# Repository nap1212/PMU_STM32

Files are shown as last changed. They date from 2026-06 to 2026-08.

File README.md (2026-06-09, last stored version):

# PMU Synchrophasor Dashboard

STM32F446RE (Nucleo) を使用した IEEE C37.118.1 準拠の PMU (Phasor Measurement Unit) 実装と、リアルタイム可視化ダッシュボードです。

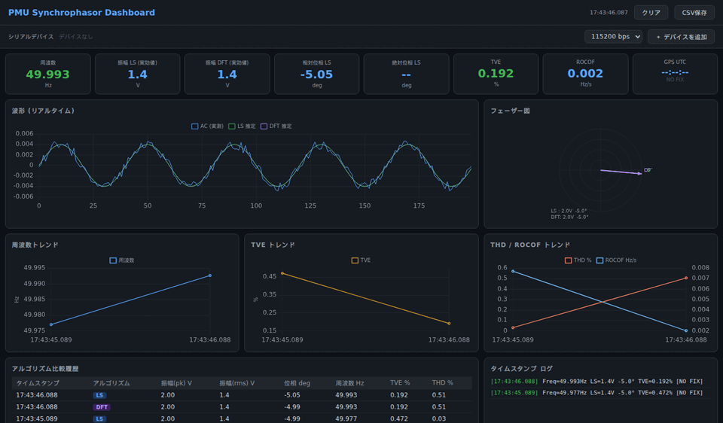
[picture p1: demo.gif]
Demo


---

## 概要

| 項目 | 内容 |
|---|---|
| MCU | STM32F446RE (Nucleo-F446RE) |
| GPS | Waveshare L76K GPS HAT |
| サンプリング周波数 | 2000 Hz |
| バッファサイズ | 200 サンプル (100 ms) |
| 対応系統周波数 | 50 Hz / 60 Hz |
| フェーザー推定 | LS法 (最小二乗) + DFT法 |
| 時刻同期 | GPS PPS (1秒パルス) による絶対フェーザー |

---

## ハードウェア構成

### 必要なもの

- STM32F446RE Nucleo ボード
- Waveshare L76K GPS HAT (または互換GPS モジュール)
- アナログ信号センサー (変換比 500:1)
- USB Type-A to Mini-B ケーブル
- ジャンパーワイヤー

### ピン接続

#### アナログ入力 (センサー)

```
交流電圧/電流
      │
   センサー (変換比 500:1)
      │
  DCバイアス回路 (目標: 1.65V = VDDA/2)
      │
   PA0 (Nucleo CN7 pin28) ← ADC1_IN0
```

#### GPS L76K HAT → Nucleo

```
L76K 40ピンヘッダー      Nucleo
─────────────────────────────────────
Pin 1  (3.3V)  ────→  3.3V (CN6 pin3)
Pin 6  (GND)   ────→  GND  (CN6 pin2)
Pin 7  (1PPS)  ────→  PA1  (CN7 pin24)  ← TIM5_CH2 入力キャプチャ
Pin 8  (TXD)   ────→  PA10 (CN10 pin33) ← USART1_RX
```

#### PC通信 (USB)

```
Nucleo USB ────→ PC (ST-Link 仮想COMポート, 115200 bps)
```

---

## ファームウェア機能

### 計測・解析

| 機能 | アルゴリズム |
|---|---|
| フェーザー推定 (相対) | LS法 (最小二乗) |
| フェーザー推定 (比較用) | DFT法 |
| **絶対フェーザー** | **GPS PPS 基準 UTC 同期** |
| 周波数推定 | ゼロクロス法 + 外れ値除外 |
| ROCOF | 周波数差分 |
| TVE | IEEE C37.118.1 準拠 (LS基準・DFT評価) |
| 高調波解析 | DFT 2次・3次 + THD |

### GPS同期

```
GPS PPS (1Hz) ──→ TIM5_CH2 入力キャプチャ
                      │
                  ppsCapture 記録 (90 MHz 分解能 ≈ 11 ns)
                      │
              バッファ先頭サンプル時刻との差分
                      │
              絶対位相 = 相対位相 − UTC基準コサイン位相
```

---

## ダッシュボード

Chrome / Edge でそのまま開けるシングルファイル HTML です。

```
pmu_dashboard.html をブラウザで開く
```

### 機能一覧

| パネル | 内容 |
|---|---|
| KPI カード | 周波数・振幅(LS/DFT)・相対位相・**絶対位相**・TVE・ROCOF・**GPS UTC/Lock** |
| 波形チャート | AC実測・LS推定・DFT推定 (200サンプルリアルタイム) |
| フェーザー図 | LS・DFT ベクトル描画 |
| 周波数トレンド | 直近60点 |
| TVE / THD / ROCOF トレンド | 直近60点 |
| アルゴリズム比較テーブル | LS vs DFT 履歴 |
| タイムスタンプログ | ミリ秒単位・GPS UTC 付き |
| CSV保存 | 全計測履歴をワンクリックでダウンロード |

### シリアル接続手順

1. Chrome または Edge でダッシュボードを開く (Firefox は WebSerial 非対応)
2. **「＋ デバイスを追加」** ボタンを押す
3. ブラウザのポート選択ダイアログで Nucleo の COM ポートを選択
4. **「接続」** ボタンを押す (115200 bps)

> デバイスパネルに `🔵 STM32 Nucleo` と表示されれば認識成功。  
> 接続すると自動でデモモードが停止し、実データに切り替わります。

---

## ビルド手順

### 1. 必要なもの

- STM32CubeIDE 1.14+
- STM32Cube FW_F4 V1.28+

### 2. ビルド

```
STM32CubeIDE でプロジェクトを開く
→ Project → Build Project
→ Run → Run
```

### 3. float printf 有効化 (初回のみ)

`Project → Properties → C/C++ Build → Settings → MCU GCC Linker → Miscellaneous → Other flags`

```
-u _printf_float
```

---

## シリアル出力フォーマット

### PLOT_MODE=0 (デフォルト: 波形)

```
AC:0.0012,LS_est:0.0011,DFT_est:0.0011   ← 200行
========================================
  PMU Synchrophasor Measurement Result
========================================
Frequency      : 50.012 Hz  [正常 50Hz]
ROCOF          : 0.0001 Hz/s
Abs Phase (LS) : -12.345 deg  [UTC基準]
GPS Lock       : LOCKED
UTC            : 12:34:56
TVE            : 0.234 %  [合格 <=1%]
...
```

### PLOT_MODE=1 (フェーザー情報)

```
Amp_LS:220.00,Amp_DFT:219.50,...,AbsPhase_LS:-12.345,UTC:12:34:56,GPS_LOCK:1
```

---

## ライセンス

MIT License

---

## 参考規格

- IEEE Std C37.118.1-2011: *IEEE Standard for Synchrophasor Measurements for Power Systems*
- NMEA 0183: GPS GPRMC センテンス

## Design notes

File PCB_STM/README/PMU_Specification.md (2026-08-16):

# 単相PMU 試作機 仕様書 (Specification)

**対象**：単相100V（コンセント地点）の同期フェーザ（電圧・電流）計測装置（ラボ試作・教育/研究用）
**版**：v3.2（アナログ3.3Vを **R1SE-0505廃止 → 低ノイズLDO一段** に簡素化）
**構成方針**：STM32で決定的サンプリング＋フェーザ演算／ESP32でWiFi送信／GPSで時刻同期／**測定線から分岐して装置自身に給電**

> **v3.2からの主な変更**：アナログ系電源（ADC AVDD / AMC VDD2）の生成を「R1SE-0505（絶縁DC-DC）＋LDO」から **低ノイズLDO一段** に変更。
> - この設計では安全絶縁は HLK と AMC3330/3302 が担うため、**R1SEの役割は“ノイズ絶縁”のみ**。R1SE自身がスイッチングノイズ源で結局LDOで掃除が要る → **最初からLDO一段の方が素直で低ノイズ・部品減**。
> - 振幅精度はADC内蔵Vref(1.2V)が決め、5Vノイズは PSRR 経由のみ。LDOのPSRR（DC〜系統高調波で60〜80dB）＋ΔΣ/AAFで十分クリーン。
> - フォールバック：**ESP32のグラウンド雑音がアナログ基準を揺らすのが実測で問題化した場合のみ**、R1SE（絶縁DC-DC）を復活してアナロググラウンドを島化する余地を残す。
>
> **v3.1（継続）**：自給電の電源部は **絶縁AC-DCモジュール HLK-10M05（AC100V→DC5V 2A）**。トランス T3＋整流＋三端子7805 を1個に集約（部品点数・発熱を削減）。容量2Aはピーク約1Aに対し余裕（5M05＝1Aは不足）。**分岐点はシャント Rsh 上流（L_NODE）で不変**。USBはデバッグ用途で併用可。

> **v2.0→v3.0**：外部USB/5V給電に代えて**測定対象の商用100Vから装置電源を自給**する構成を標準化（分岐はシャント上流）。
>
> **v1.0からの主な変更（継続）**：電流センサを ZMCT103C（電流トランス）→ **シャント抵抗 + AMC3302** に置換。
> 電流chが電圧chと同じ「センサ→絶縁アンプ→AAF→ADC」構造になり、**負担抵抗 Rb / Vcmバイアス Rcm / VCM基準回路 が不要**に。
> 位相誤差（純抵抗シャント＋固定遅延の絶縁アンプ）が大幅に低減し、PMUのTVE改善に寄与する。

---

## 1. 確定構成（主要部品）

| 役割 | 部品 | 備考 |
|---|---|---|
| MCU（取得・演算） | **STM32F446RE（NUCLEO-F446RE）** | FPU搭載、タイマ＋DMA |
| WiFi通信 | **ESP32（ESP32-WROOM-32E 開発ボード）** | C37.118 over WiFi 送信 |
| GPS（時刻同期） | **Waveshare L76K GPS HAT** | 1PPS出力、GPS/GLONASS/BeiDou/QZSS。Piに挿さずSTM32へ配線 |
| ADC | **ADS131M02** | 2ch・24bit・同時サンプリングΔΣ、SPI |
| 絶縁アンプ（電圧） | **AMC3330** | ±1V入力・絶縁DC-DC内蔵 |
| 絶縁アンプ（電流） | **AMC3302** | **±50mV入力・固定ゲイン41・絶縁DC-DC内蔵**（シャント用） |
| 電流シャント | **Rsh ≈ 1.5mΩ**（4端子/低TCR） | L線直列。10A時±21mV→×41で≈0.87V（ADC FSR ±1.2V内） |
| アナログ用LDO | **ADP7142（3.3V固定, TSOT-23-5：ADP7142AUJZ-3.3 / LFCSP：ACPZ-3.3）** | +5V_Fから ADC AVDD / AMC VDD2 を生成。入出力C≥2.2µF。代替 ADP7118-3.3 / TPS7A20 |
| **絶縁AC-DCモジュール** | **HLK-10M05（AC100-240V → DC5V 2A / 10W）** | 自給電の主電源。AC入力を**L_NODE-N_NODE（シャント上流）**へ。強化絶縁を担う。5M05(1A)は容量不足のため不採用 |
| **一次側ヒューズ（電源分岐）** | **F2：AC250V/T/0.5A** | HLK AC入力の保護 |

> **アナログ電源の位置づけ**：AMC3330/AMC3302はDC-DC内蔵のため絶縁電源は不要。ADC/AMCのアナログ3.3Vは **低ノイズLDO一段** で +5V から生成（アナロググラウンドはデジタルと1点接続）。安全絶縁はHLKとAMCが担うため、アナログ経路に絶縁DC-DC（R1SE等）は不要。**ESP32グラウンド雑音が実測で問題化した場合のみ**、R1SE（絶縁DC-DC）を追加してアナロググラウンドを島化する余地を残す。
> **自給電部（HLK-10M05）の位置づけ**：測定対象100Vから装置電源を作る。**絶縁境界は HLK（電源経路）と AMC3330/3302（信号経路）の二重**で、安全側は測定線に対して常にフローティング。**分岐点は必ずシャント Rsh より上流**とし、給電電流を測定経路（Rsh）に流さないこと（測定誤差ゼロの必須条件）。

---

## 2. システムブロック図

```
        危険側(AC100V, 測定線)          ┊絶縁┊            安全側(フローティング)
 L ─[F1]─[SW1]─●(L_NODE)─[Rsh 1.5mΩ]─●(L_LOAD)──────────→ 負荷へ(L)
              │  │                   │
              │ (電圧タップ)     シャント両端(±50mV)→ AMC3302(絶縁+DCDC) → AAF → ADS131M02 ch1
              │  │                                                          │
              │ 分圧(510k×3+5.1k)→ AMC3330(絶縁+DCDC) ─────────→ AAF → ADS131M02 ch0
              │  │                                                          │SPI/DRDY
   ┌──[F2]────┘  │      ← ★給電はシャント上流(L_NODE)で分岐 → Rshを通らない  │
   │(電源分岐)    │   ┊電源側の絶縁境界(HLK内蔵)┊                             │
 [HLK-10M05]─────┼─→ +5V(2A) ─┬─→ Nucleo(STM32) ──────────────────────────┤
 絶縁AC-DC 5V/2A  │            ├─→ ESP32 ─WiFi→ PC/PDC
   │            │            └─→ LDO(低ノイズ)→+3.3V_A(アナログ: ADC/AMC)
 N ●───────────●(N_NODE)────────────────────────────────→ 負荷へ(N)
        L76K GPS HAT ─UART/PPS─→ STM32(入力キャプチャ)   ↑MCO(8MHz)→ADC CLKIN
```

- **絶縁境界（信号）**：電圧ch＝AMC3330、電流ch＝**AMC3302**（いずれも容量結合の強化絶縁＋内蔵DC-DC）。
- **絶縁境界（電源）**：**HLK-10M05（絶縁AC-DC）**。AC入力＝危険側（L_NODE-N_NODE）、DC出力＝安全側。→ 安全側は測定線に対し**二重に絶縁**され、常にフローティング。MCU/ESP32/GPSは安全側。
- **自給電の要点**：分岐は**シャント Rsh より上流（L_NODE）**。HLK 1次電流は L_NODE→N_NODE を流れ **Rsh を通らない**ため、電流測定に一切影響しない。
- **両ch対称**：電圧・電流とも「センサ→絶縁アンプ→AAF→ADC」。出力コモンモードはアンプが自己生成（VDD2/2）。

---

## 3. 電源アーキテクチャ（測定線からの自給電）

**電源フロー**（AC-DCモジュール＋アナログ再生成）：
```
測定線 L_NODE ─[F2]─ HLK-10M05(AC100V→DC5V 2A) ═絶縁═ +5V
                                                       │
      +5V ─┬─→ Nucleo(E5V)→内蔵LDO→+3.3V_D(STM32/ADC DVDD/L76K)
           ├─→ ESP32（+5V, 470-1000µFバルク）
           └─→ LDO(低ノイズ3.3V) ─ +3.3V_A（ADC AVDD / AMC3330・3302 VDD2）
```

| レール | 供給先 | 供給元 |
|---|---|---|
| （AC入力） | HLK-10M05 Vin(L/N) | **測定線 L_NODE-N_NODE（シャント上流）** 経由、F2で保護 |
| +5V | ESP32 / アナログLDO入力 / Nucleo(E5V) | **HLK-10M05 出力 5V/2A**（自給電・絶縁済） |
| +3.3V（デジタル） | STM32 / ADS131M02 DVDD / L76K | Nucleo 3.3V（E5V経由の内蔵LDO） |
| +3.3V（アナログ） | ADS131M02 AVDD / **AMC3330 VDD2 / AMC3302 VDD2** | **+5V → 低ノイズLDO一段で3.3V**（π型フィルタ後の+5V_Fから） |
| AMC3330/AMC3302 フィールド側 | （各IC内部DC-DCが自動生成） | 不要 |

- **自給電の原則**：**分岐はシャント Rsh の上流（L_NODE）**。給電電流（HLKのAC入力）は Rsh を通らず、電流測定に影響しない（誤差ゼロの必須条件）。
- **ノイズ対策（要点）**：HLK-10M05は**スイッチング方式**で出力に数十mVppのリプル＋高周波ノイズを持つ。よって
  - **アナログ系(ADC/AMC)は π型フィルタ後の+5V → 低ノイズLDO** で作り、LDOのPSRR＋フィルタでHLKノイズを落とす。
  - HLK出力直後に **π型フィルタ（10µF＋小インダクタ/フェライトビーズ＋10µF）**＋各ICデカップリングでHF成分を減衰。
  - HLKのスイッチング周波数はADC帯域(≈fs/2 3.9kHz, AAF 1.7kHz)より遥かに高く、ΔΣ＋AAFで良く落ちるが、エイリアス防止のためAAF前段のクリーン化を優先。
- **Nucleo給電**：E5Vピンへ+5V供給（ジャンパ **JP5 を E5V 側**に設定）。
- **容量マージン**：HLK-10M05=2A に対しシステムピーク約1A → 2倍の余裕。ESP32送信バーストは **ESP32直近の 470-1000µFバルク**でも吸収。
- アナロググラウンド/デジタルグラウンドは**1点（スター）接続**。**HLKの −Vout=安全側基準（DGND）**（フローティング）。AGNDとはADC直下1点で結合。
- **VCM基準回路は廃止**（電流chがアンプ自己バイアスになったため不要）。

### 3.1 自給電電源部の設計（性能を落とさないための要点）

**目的**：測定対象の商用100Vから装置電源を作りつつ、（a）電流測定に誤差を出さない（b）ADC/AMCへスイッチングノイズを持ち込まない。

**(1) 分岐点＝シャント上流（測定誤差ゼロの必須条件）**
```
 L ─[F1]─[SW1]─●(L_NODE)──[Rsh 1.5mΩ]──●(L_LOAD)──→ 負荷L
                 │  ▲(ここを通る電流=測定値)
      ┌──[F2]────┘
 [HLK Vin(L)]   ← 分岐は必ず L_NODE（Rshの上流）。
      │           HLKのAC入力電流は L_NODE→N_NODE を流れ Rsh を通らない → 測定に加算されない
 N ───●(N_NODE)── HLK Vin(N)
```
- L_LOAD（シャント下流）から取ると給電電流が Rsh を流れ負荷電流に上乗せ＝誤差。**必ず L_NODE**。
- 電圧測定への影響：HLK入力は L_NODE-N_NODE 間の負荷になるが、分圧タップの電圧読み値自体は変わらない（精度影響なし。ごく軽い電源負荷が増えるのみ）。

**(2) 消費電力の見積り（+5V換算）**

| ブロック | 平均 | ピーク | 備考 |
|---|:---:|:---:|---|
| Nucleo（STM32＋内蔵LDO, L76K含む） | ~150mA | ~180mA | E5V給電 |
| ESP32 | ~120mA | ~500mA | WiFi送信時バースト |
| アナログ系（ADC/AMC＋LDO） | ~50mA | ~80mA | LDOで5V→3.3V、消費は小さい |
| **合計** | **~320mA** | **~0.8A** | HLK-10M05(2A)で2倍超の余裕 |

**(3) 電源モジュール（HLK-10M05）**

| 項目 | 値 | 計算/根拠 |
|---|----|---|
| 型式 | **HLK-10M05** | 絶縁AC-DC、AC100-240V入力、DC5V 2A(10W)出力 |
| 出力容量 | **2A** | システムピーク約1Aに対し2倍余裕（5M05=1Aは不足のため不採用） |
| 出力リプル | 数十mVpp＋SWノイズ | **アナログはπ型フィルタ＋低ノイズLDOで除去** |
| 出力バルク | +5V直下 100µF＋ESP32直近 470-1000µF | ESP32送信ピーク吸収 |
| AC入力保護 | **F2：AC250V/T/0.5A** | HLK入力側ヒューズ |
| 絶縁 | 強化絶縁（データシート値） | 安全側フローティングを担保 |

- **HLKの弱点＝スイッチングノイズ**：リニア（旧T3+7805）より不利。よって**アナログ経路は π型フィルタ＋低ノイズLDO** でHF減衰・再レギュレート。
- **利点**：部品点数削減・発熱ほぼ無し（放熱器不要）・入手容易・小型。トランス入手難と7805発熱の問題を解消。

**(4) ノイズ・性能維持**
- HLK-10M05は**スイッチング方式**なので、出力に数十mVppリプル＋高周波ノイズを持つ（リニアより不利）。対策を段で重ねてADCアナログ帯域への混入を抑える：
  1. **HLK出力直後にπ型LCフィルタ**（L1＋C45/C46 10µF）でHF成分を減衰。
  2. **アナログ系(ADC AVDD / AMC VDD2)は 低ノイズLDO一段**で3.3Vを再生成 → LDOのPSRR（DC〜系統高調波で60〜80dB）でHLKリプルを除去。
  3. ADCは**ΔΣ＋AAF(1.7kHz)**。HLKのスイッチング周波数（数十〜数百kHz）は帯域外で強く減衰。ただしエイリアス防止のためAAF前段のクリーン化を優先。
- 振幅精度を決めるのはADC内蔵Vref(1.2V)であり+5Vレールではない → 5Vノイズが基本波ビンのTVEへ乗る経路は細い。
- グラウンド：**HLK −Vout＝安全側基準（DGND, フローティング）**。AGND-DGNDはADC直下1点スター（§20）。ESP32のバースト電流はDGND側に閉じ込め、AGNDへ回さない。

---

## 4. 電圧フロントエンド設計

AMC3330：±1Vバイポーラ入力（中点バイアス不要）・**固定ゲイン2.0**。
分圧比は「**ゲイン2倍後の出力がADC FSR(±1.2V)に収まる**」よう設定（入力範囲だけでなく出力で確認）。

| 部品 | 値 | 計算/備考 |
|---|----|---|
| 分圧 上側 Rhi | **510kΩ ×3 直列（1.53MΩ）** | 各≈33V分担で耐圧確保。0.1%/≤25ppm/薄膜 |
| 分圧 下側 Rlo | **5.1kΩ** | 分圧比 ≈ 1/301（5.11kΩ/E96でも可）|
| 入力ピーク | 141Vpk ÷301 ≈ **0.47Vpk** | AMC3330 ±1V内 |
| AMC出力（×2）| 0.47Vpk×2 ≈ **0.94Vpk** | ADS131M02 FSR ±1.2V内（約22%余裕）|
| 分圧電流 | 約65µA（消費約6.5mW、発熱無視可） | Rhiでほぼ決まる |
| 出力コモンモード | AMC3330が VDD2/2（≈1.65V@3.3V）を生成 | ADC入力CMに整合 |

- **耐圧確認**：510kΩは working voltage ≥ 33V/本。
- **重要**：AMC3330はゲイン2なので `141Vpk × 分圧比 × 2 ≤ 1.2V` を満たすこと。
  （旧版の1/153では出力1.84Vpk＞FSRで飽和していた → Rloを10kΩ→5.1kΩに変更）

---

## 5. 電流フロントエンド設計（シャント抵抗 + AMC3302）

L線に低抵抗シャントを直列に挿入し、その両端電圧（±数十mV）を**絶縁シャントアンプ AMC3302**で測る。
純抵抗センスのため**位相誤差がほぼゼロ**、DCも測定可、飽和なし。**実用測定レンジ 〜10A**前提。

| 部品 | 値 | 計算/備考 |
|---|----|---|
| シャント Rsh | **1.5mΩ**（4端子ケルビン/≤25ppm/≥1W） | 10A rms（14.1Apk）で 14.1A×1.5mΩ ≈ **21.2mVpk**（AMC3302 ±50mV内） |
| 絶縁アンプ AMC3302 | 入力±50mV / **固定ゲイン 41** | 出力差動 = 21.2mV×41 ≈ **0.87Vpk**（ADS131M02 FSR ±1.2V内）|
| ADC飽和まで | 出力1.2V→入力29.3mV→ **約13.8A rms** | 定格10Aに対し約1.4倍の余裕 |
| 発熱 | I²R = 100×0.0015 ≈ **0.15W**（10A時）| 5A時≈0.04W |
| 出力コモンモード | AMC3302が VDD2/2（≈1.65V）を生成 | ADC入力CMに整合（中点バイアス不要）|
| レンジ調整 | 小信号重視→Rsh大（2mΩ等）／大電流→Rsh小 | 「最大電流×√2×Rsh×41 ≤ 1.2V」を満たすこと |

**接続**：Rshの両端を**ケルビン(4端子)**で AMC3302 INP/INN へ。AMC3302の高圧側GND(HGND)はシャント片端へ。
出力 OUTP/OUTN を AAF経由で AIN1P/AIN1N へ。**負担抵抗・Vcmバイアス・VCM基準は不要**。

> **重要**：シャント自体は非絶縁（L線上）。絶縁はAMC3302が担う（強化絶縁＋内蔵DC-DC）。
> シャントは**低TCR・4端子**品を選び、配線抵抗を測定値に含めないこと。

---

## 6. アンチエイリアスフィルタ（AAF）

電圧ch・電流chで**完全同一**（位相整合のため）。差動構成。**v1.0から変更なし**。

| 部品 | 値 | 備考 |
|---|----|----|
| 直列R（各ライン） | **1kΩ ×2/ch**（0.1%/薄膜） | 両ch同一型番 |
| 差動C（Cdiff） | **47nF**（C0G/NP0 or フィルム） | fc_diff ≈ 1/(2π·2kΩ·47nF) ≈ **1.7kHz** |
| コモンモードC（Ccm） | **1nF ×2/ch**（C0G） | 各ラインからAGNDへ（任意） |

- fc≈1.7kHz は fs/2（≈3.9kHz）より十分下。50Hzで約−1.7°の群遅延 → **両ch同一化で相殺＋実測補償**。

---

## 7. ADCサブシステム（ADS131M02）

| 項目 | 設計値 |
|---|---|
| CLKIN | **STM32 MCO出力 8MHz**（PA8/MCO1。Nucleo HSE由来） |
| fMOD | 4MHz（CLKIN/2） |
| OSR | **512** |
| データレート fDATA | **≈7812.5 SPS**（50Hzで約156サンプル/周期、60Hzで約130） |
| ゲイン | 1（FSR ±1.2V、内部Vref 1.2V） |
| インタフェース | SPI（STM32マスタ）、**DRDY→EXTI割込**、DMA転送 |
| ch割当 | ch0=電圧、ch1=電流（同時サンプリング） |

---

## 8. 時刻同期（L76K GPS HAT）

- HATはPi用だが、**UART(TX/RX)・PPS・5V/3.3V・GND をSTM32へ配線**して使用（Piに挿さない）。**PPSピンが端子に出ていることを確認**。
- L76K：GPS/GLONASS/BeiDou/**QZSS(みちびき)対応**、1PPS精度 <30ns（50Hzで約0.0005°相当＝十分）。
- **PPS → STM32タイマ入力キャプチャ**（sub-µsでエッジ時刻取得）。
- UARTでNMEA/構成（PPS周波数等）を受信。屋外/窓際で運用。

---

## 9. 制御・通信

- **STM32 → ESP32：UART（例 921600bps）**でフェーザ結果（タイムスタンプ・V振幅/位相・I振幅/位相・f・ROCOF）を転送。
- **ESP32**：受信データを **C37.118.2 フレーム化 → WiFi(UDP/TCP)** でPC/PDCへ。
- 両者3.3Vロジック・GND共通、レベルシフト不要。
- 時刻クリティカルパスはSTM32内で完結 → WiFi遅延・ジッタはフェーザ精度に無影響（値にタイムスタンプ）。

---

## 10. STM32ピン割当（例：NUCLEO-F446RE）

| 機能 | ピン例 |
|---|---|
| ADC SPI（SCLK/MISO/MOSI/CS） | SPI1: PA5/PA6/PA7/PA4 |
| ADC DRDY | EXTI: PB0 |
| ADC /SYNC-RESET | 予備GPIO（例 PC0。§19-E/§20参照） |
| ADC CLKIN | **MCO1: PA8（8MHz出力）** |
| GPS PPS | タイマ入力キャプチャ: TIM2_CH1 / PA0 |
| GPS UART | USART2: PA2(TX)/PA3(RX) |
| ESP32 UART | USART1: PA9(TX)/PA10(RX) |

---

## 11. 受動部品リスト（抵抗・コンデンサ）と数量

### 抵抗（すべて Thin Film、精度が効く所は 0.1%/≤25ppm）

| 値 | 用途 | 必要数 | 推奨購入数 | 仕様 |
|----|---|:---:|:---:|---|
| 510kΩ | 分圧上側（3直列） | 3 | **10** | 0.1%/≤25ppm/耐圧≥33V |
| 5.1kΩ | 分圧下側（Rlo） | 1 | **5** | 0.1%/≤25ppm（5.11kΩ/E96可・ゲイン2考慮で1/300）|
| 1kΩ | AAF（2本/ch×2ch） | 4 | **10** | 0.1%/薄膜・両ch同一型番 |
| **1.5mΩ シャント Rsh** | 電流センス | 1 | **3** | 4端子ケルビン/≤25ppm/≥1W（実発熱0.15W@10A） |

> v1.0から削除：68Ω負担抵抗 / 10kΩ×4（Vcm分圧2＋Rcm2）。
> 旧部品記号 R7(負担)・R8,R9(VCM)・R10,R11(Rcm) は廃止。

### コンデンサ

| 値 | 用途 | 必要数 | 推奨購入数 | 種類 |
|----|---|:---:|:---:|---|
| 0.1µF | 各IC電源デカップリング | ~12 | **30** | X7R 50V |
| 1µF | ADC(AVDD/DVDD/CAP)・AMC3330/AMC3302(VDD2・DC-DC高圧側) | ~10 | **25** | X7R 50V |
| 10µF | LDO入出力(C16/C18・各≥2.2µF)・AVDDバルク・πフィルタ(C45/C46) | ~5 | **15** | X5R/X7R |
| 100µF | 5Vバルク（ESP32突入対策） | 2 | **5** | 電解/タンタル |
| 47nF | AAF 差動C（Cdiff） | 2 | **10** | **C0G/NP0** or フィルム |
| 1nF | AAF コモンモードC（Ccm）・AMC高圧側 | ~8 | **15** | C0G |

> v1.0から削除：VCMバイパス10µF（C4）。追加：AMC3302のデカップリング一式（AMC3330と同じ構成）。
> ADS131M02/AMC3330/AMC3302/アナログLDO の各データシート推奨デカップリング（CAPピン・DC-DCピン等）を最終確認して値・本数を確定すること。

### 自給電電源部（v3.1：HLK-10M05 方式／v3.2：アナログLDO一段）

| 部品 | 記号 | 値/型 | 必要数 | 備考 |
|---|---|---|:---:|---|
| 絶縁AC-DCモジュール | U6 | **HLK-10M05**（AC100-240V→DC5V 2A） | 1 | AC入力を L_NODE-N_NODE（シャント上流）へ。強化絶縁 |
| 電源分岐ヒューズ | F2 | AC250V/T/0.5A ＋ホルダ | 1 | HLK AC入力保護 |
| 出力バルク（+5V直下） | C43 | 100µF | 1 | 電解/タンタル |
| 出力バルク（ESP32直近） | C44 | 470-1000µF | 1 | 電解。送信ピーク吸収 |
| πフィルタ用 | L1 | 大電流フェライトビーズ（1206以上/定格≥2A/DCR≤50mΩ/100〜600Ω@100MHz。例：村田BLM31系, TDK MPZ2012系）or 4.7〜10µH/≥2Aパワーインダクタ | 1 | HLK出力HF減衰。全電流が通るため信号用0603ビーズ不可 |
| πフィルタ用C | C45,C46 | 10µF ×2 | 2 | L1と組んでπ型LC |
| アナログ用LDO | U4 | ADP7142（3.3V固定, 例 AUJZ-3.3/ACPZ-3.3） | 1 | +5V_F→+3.3V_A。EN→VIN、SENSE→VOUT、入出力C≥2.2µF（C16/C18=10µF） |

> HLK-10M05は**トランス T3／ブリッジ BR1／平滑 C40／三端子 U6(7805)／放熱器 を全て置換**（v3.0比で大幅減）。放熱器・T3入手難の問題が解消。
> アナログ3.3Vは **低ノイズLDO一段**（R1SE-0505は廃止）。安全絶縁はHLK/AMCが担うためアナログ経路に絶縁DC-DCは不要。

---

## 12. アルゴリズム

### 12.1 取得（Acquisition）
1. STM32がMCOで8MHzをADC CLKINへ供給 → ADCは固定 fDATA(≈7812.5SPS) で**自走**。
2. **DRDY割込**ごとにSPI/DMAで2ch同時サンプル（V,I）を取得し、リングバッファへ。
3. **PPS立ち上がり**をタイマ入力キャプチャで捕捉 → そのタイマカウントを保持。
4. サンプルカウンタとPPSキャプチャ値から、各サンプルの**絶対時刻（UTC）**を復元。
   - PPS毎に基準を更新（STM32水晶のppm誤差を1秒毎にリセット）。

### 12.2 フェーザ推定（Phasor Estimation）
- 報告周期（例 **50 fps**、設定可）ごとに、UTCの基準時刻に整列した窓のサンプルを抽出。
- 基本波フェーザを **DFT** で算出：
  - `X = (2/N) Σ x[n]·e^(−j2πk0 n/N)`（k0＝基本波ビン）
  - この正規化で **|X| ＝ピーク振幅**、位相 = arg(X)（**UTC基準＝同期フェーザ**）。
  - **C37.118は振幅＝RMS慣例**のため、出力・電力計算の前に **RMS化：Vrms=|X|/√2、Irms=|X|/√2**。
- **補間DFT（Interpolated DFT, IpDFT）**で系統周波数の公称ズレを補正：
  - Hann窓を適用し、ピーク近傍の2〜3ビンから**真の周波数・振幅・位相**を補間推定。

### 12.3 周波数・ROCOF
- IpDFTで得た基本波周波数 f を出力。
- 連続する推定値から **ROCOF = df/dt**（平滑化付き差分）。

### 12.4 電力量
- **RMS化したフェーザ**（Vrms=|V|/√2, Irms=|I|/√2）から：
  - 有効電力 P = Vrms·Irms·cosφ、無効電力 Q = Vrms·Irms·sinφ、力率 = cosφ（φ＝∠V−∠I）。
  - ※ピーク振幅で計算する場合は P = ½|V||I|cosφ（1/2係数を忘れないこと）。

### 12.5 校正補償（適用順）
1. **振幅スケール**：分圧比・**シャント値 Rsh**・**AMC3302/AMC3330ゲイン**の実測係数で物理量へ換算。
2. **位相オフセット補償**：ch毎の遅れ（AMC3330/AMC3302＋AAF＋ADC）を校正テーブルで減算。
3. **AAF群遅延補償**：実測群遅延を位相から差し引く。

### 12.6 出力（C37.118）
- STM32 → ESP32（UART）：`{UTCタイムスタンプ, Vmag, Vang, Imag, Iang, f, ROCOF, status}`。
  - **Vmag/Imag は RMS値**（=|X|/√2）でC37.118に整合させる。
- ESP32：C37.118.2 データフレーム化 → WiFi送信。

---

## 13. 校正手順（TVEを決める要）

1. **振幅校正**：既知の基準電圧・電流を入力し、スケール係数を決定（電流は **Rsh×ゲイン** が基準）。
2. **位相校正**：同位相の基準V・I（抵抗負荷で力率≈1）を入力し、各chの位相オフセットを実測 → テーブル化。
   - シャント＋AMC3302は位相シフトが小さいので、残差はAAF群遅延が主成分。
3. **群遅延校正**：AAFカットオフ確定後、群遅延を実測し補償。
4. **検証**：基準器または既知力率負荷でTVE・力率を確認。

---

## 14. テスト負荷

| 負荷 | 電流 | 力率 | 用途 |
|---|---|---|---|
| 白熱電球100W | 約1A | ≈1.0 | 同相確認・位相校正基準 |
| 無誘導電力抵抗 470Ω50W | 約0.2A | ≈1.0 | 既知抵抗の校正基準 |
| 小型モーター/扇風機 | 数百mA〜 | <1 | 位相差（力率<1）観測 |

> Rsh 1.5mΩでは **ADC FSR(±1.2V)到達が約13.8A rms**（AMC3302入力±50mV到達より先にADCが飽和）。
> 余裕をみて **>10A 負荷は避ける**。レンジを変えるならRshを調整。

---

## 15. 安全設計（必須）

- L側に**ヒューズ（AC250V・T・ceramic HBC）＋電源SW**（F1/SW1）。**電源分岐にも専用ヒューズ F2**（HLK AC入力保護）。
- 危険側（分圧器・**シャント**・**HLK AC入力側**・配線）は**絶縁ケース＋端子カバー**で露出させない。
- **シャントはL線(活線)上にあり非絶縁**。絶縁境界（AMC3330・AMC3302・**HLK-10M05**）より先が安全側 → PC/WiFiデバッグ安全。
- **自給電の絶縁**：安全側は **HLK-10M05（電源）と AMC3330/3302（信号）の二重絶縁**で測定線からフローティング。**HLKは強化絶縁のAC-DC品**で、1次-2次の沿面/空間距離が確保されている（データシートの絶縁耐圧を確認）。非絶縁のトランスレス（コンデンサドロップ/抵抗ドロップ）電源は**禁止**（安全側が活線に浮く）。
- **HLK AC入力は必ずシャント上流（L_NODE）**。下流(L_LOAD)分岐は測定誤差の原因かつ配線が煩雑になるため不可。
- 危険側で自給電する場合、**測定側の絶縁トランス T2 は任意**。実系統をそのまま測るなら T2 を省き、装置ごと活線電位に置く運用も可（その場合こそ HLK/AMC の絶縁が生命線）。T2 を残すなら HLK AC入力は T2 2次側（=L_NODE-N_NODE）へ接続する。
- シャントの**ケルビン配線**を短く。高圧側GND(HGND)はシャント片端に確実に接続。
- **HLKのAC入力ピン（危険側）とDC出力ピン（安全側）を基板上で明確に分離**し、絶縁スリット/距離を確保。安全側配線を1次側パターンに近づけない。
- 初回は低ワット抵抗負荷から、電流を見ながら段階的に。自信が無ければ経験者立ち会い。

---

## 16. 追加で必要な支援部品（参考）

| 部品 | 用途 |
|---|---|
| 低ノイズ3.3V LDO（ADP7142/TPS7A20/NJM2845等） | +5V→アナログ3.3V（ADC AVDD / AMC VDD2） |
| ヒューズ＋ホルダ＋AC SW＋端子台 | 安全（F1/SW1、電源分岐F2） |
| **絶縁AC-DCモジュール HLK-10M05（5V/2A）** | **測定線からの自給電（強化絶縁・低部品点数）** |
| **πフィルタ部品（フェライトビーズ/インダクタ＋10µF×2）** | **HLK出力のスイッチングノイズ減衰** |
| 絶縁トランス T2（100:100V 小容量） | 測定側の安全給電（自給電時は任意） |
| SOIC→DIP / TSSOP→DIP 変換基板 | ADS131M02・AMC3330・AMC3302実装 |
| ユニバーサル基板・ピンヘッダ・配線材 | 試作 |

---

## 17. 要確認事項（データシート）

- **シャント Rsh**：定格電力・TCR・4端子接続の確認（測定確度に直結）。
- **AMC3302**：入力レンジ(±50mV)・**固定ゲイン41**・出力コモンモード・DC-DCピン結線とデカップリング。
- ADS131M02：CAPピン等の推奨デカップリング、入力コモンモード範囲、OSR設定。
- AMC3330：出力コモンモード値、DC-DCピン結線とデカップリング推奨部品。
- アナログLDO（U4）：出力3.3V・低ノイズ/高PSRR品か・ドロップアウト（5V入力で余裕）・入出力コンデンサ推奨値。
- L76K GPS HAT：PPSピンの引き出し位置、UART電圧レベル。
- STM32 MCO：8MHz出力設定（HSE経由）とADC CLKIN要件の整合。
- **HLK-10M05**：AC入力範囲・**絶縁耐圧（1次-2次）**・出力2A定格・出力リプル/ノイズ実測値・ピン配置（AC入力L/N、DC出力+Vo/-Vo）。基板の絶縁沿面距離。
- **HLK出力ノイズ**：スイッチング周波数と出力リプルをオシロで確認。**+3.3V_A（AVDD/VDD2）へノイズが混入しないこと**を確認し、必要ならπフィルタ/LDO段を強化。
- Nucleo給電：**E5V給電のジャンパ設定（JP5）**。
- ESP32送信バーストで+5Vが落ち込まないこと（C43＋C44バルクで確認、必要なら容量増）。

---

## 18. 既知の制約・発展

- シャント方式は**位相精度・DC測定・無飽和**が利点。一方シャントは**非絶縁・発熱**があり、大電流では抵抗値を下げてSNRとのトレードオフになる。
- L76Kは**測位・汎用グレード**（非timing）。TVE認証級を狙うならNEO-M8T等timingグレードへ格上げ。
- 単相構成。三相化＋正相算出、OCXOホールドオーバ、P/Mクラスフィルタ対応が標準PMUへの発展経路。

---

## 19. 詳細回路図（ブロック別）

> ピン名は機能名。実ピン番号は ADS131M02(TSSOP-16)/AMC3330・AMC3302(SOIC-16 DWE) のデータシートで確認。

### A. 商用入力・安全部（＋自給電分岐）
```
 L ●──[F1]──[SW1]──●(L_NODE)──→ 電圧タップ & シャントRsh & ★電源分岐
 N ●───────────────●(N_NODE)──→ 分圧基準 & 負荷N & ★電源分岐(戻り)
   ↑ 測定側の給電は絶縁トランス T2(100:100V) 経由（自給電時は任意）
 F1: AC250V/T/ceramic HBC/3〜10A   SW1: AC定格SW
 L_NODE─[Rsh 1.5mΩ]─●(L_LOAD)──→ 負荷L
 ★自給電分岐（シャント上流）:
   L_NODE─[F2 0.5A]─U6.Vin(L)   U6.Vin(N)─N_NODE   ; HLK AC入力は Rsh を通らない
   F2: AC250V/T/0.5A   U6: HLK-10M05
```

### B. 電圧チャネル（AMC3330）
```
 L_NODE─[R1 510k]─[R2 510k]─[R3 510k]─●(VDIV_TAP)─► U1.INP
                                       │
                                     [R4 5.1k]
                                       │
 N_NODE────────────────────────────────●─► U1.INN（=U1.HGND 高圧側基準）
            === 絶縁境界(U1内蔵DC-DC) ===
 U1.VDD2←+3.3V_A (C20 1µF/C21 0.1µF)  U1.GND2←AGND
 U1 DC-DC/LDO: DCDC_OUT-HLDO_IN, DCDC_HGND-HGND, LDO_OUT-DCDC_IN, DCDC_GND-GND
              HLDO_OUT(C 1nF/0.1µF→HGND), DCDC_OUT(C 1nF/1µF→HGND), DCDC_IN(C 0.1µF→GND)
 U1.OUTP─[R5 1k]─┬─► AIN0P     (C1 47nF 差動 across AIN0P/N)
 U1.OUTN─[R6 1k]─┴─► AIN0N     C2 1nF→AGND, C3 1nF→AGND
```

### C. 電流チャネル（シャント + AMC3302）
```
 L_NODE─[Rsh 1.5mΩ]─L_LOAD      ; シャント両端をケルビンで取り出し
 Rsh(L_NODE側)●──────► U5.INP
 Rsh(L_LOAD側)●──────► U5.INN（=U5.HGND 高圧側基準）
            === 絶縁境界(U5内蔵DC-DC) ===
 U5.VDD2←+3.3V_A (C28 1µF/C29 0.1µF)  U5.GND2←AGND
 U5 DC-DC/LDO: DCDC_OUT-HLDO_IN, DCDC_HGND-HGND, LDO_OUT-DCDC_IN, DCDC_GND-GND
              HLDO_OUT(C32 0.1µF/C33 1nF→HGND), DCDC_OUT(C30 1µF/C31 1nF→HGND), DCDC_IN(C34 0.1µF→GND)
 U5.OUTP─[R12 1k]─┬─► AIN1P    (C5 47nF across AIN1P/N)
 U5.OUTN─[R13 1k]─┴─► AIN1N    C6 1nF→AGND, C7 1nF→AGND
```

### D. （VCM基準は廃止）
```
 v1.0のVCM分圧(R8/R9/C4)は、電流chがAMC3302の自己バイアスになったため不要。
```

### E. ADC（U2 ADS131M02）
```
 +3.3V_A─(C8 1µF/C9 0.1µF)─U2.AVDD   U2.AGND→AGND
 +3.3V_D─(C10 1µF/C11 0.1µF)─U2.DVDD U2.DGND→DGND
 U2.CAP─C12 1µF→AGND
 U2.AIN0P/AIN0N←電圧(AMC3330)   U2.AIN1P/AIN1N←電流(AMC3302)
 U2.CLKIN←PA8(MCO 8MHz)
 SPI: SCLK←PA5 DIN←PA7 DOUT→PA6 /CS←PA4 /DRDY→PB0 /SYNC-RST←GPIO
 ★AGND-DGNDはU2直下で1点接続
```

### F. 自給電電源部（測定線 → +5V, HLK-10M05）
```
 [危険側]              === 絶縁境界(HLK内蔵) ===        [安全側]
 L_NODE─[F2]─U6.Vin(L)                    U6.+Vout─●(+5V)
 N_NODE──────U6.Vin(N)                    U6.−Vout─●(DGND=安全側基準)
   U6 = HLK-10M05（AC100V→DC5V 2A, 強化絶縁）
   ●(+5V) C43(100µF)→DGND / C45(10µF)→DGND          ; ★π入力側C（HLK出力直後）
   +5V─[L1 ﾌｪﾗｲﾄﾋﾞｰｽﾞ≥2A/or 数µH]─●(+5V_F)  C46(10µF)→DGND ; L1＋C46でπ出力側
   +5V_F─┬─→ Nucleo E5V（JP5=E5V）
         ├─→ ESP32 +5V                    C44(470-1000µF)→DGND（ESP32直近）
         └─→ U4(アナログLDO)入力          C16(10µF)/C17(0.1µF)→DGND（LDO入力）
 ※ HLKのAC入力(危険側)とDC出力(安全側)を基板上で明確分離・絶縁距離確保
```

### F2. アナログ低ノイズ電源（LDO一段）
```
 +5V_F─(C16 10µF/C17 0.1µF)─U4(低ノイズ3.3V LDO)─(C18 10µF/C19 0.1µF)─+3.3V_A
 ※ ADP7142は入力・出力とも Cbyp≥2.2µF が要件 → C16=10µF, C18=10µF（≥2.2µF確保）。
 ※ R1SE-0505は廃止（安全絶縁はHLK/AMCが担うため不要）。
 ※ ESP32グラウンド雑音が問題化した場合のみ +5V_F と U4入力の間に R1SE(絶縁DC-DC) を挿入する余地。
```

### G. 制御・通信
```
 STM32: SPI1/PB0/PA8→U2   USART2(PA2/PA3)→L76K   PA0←L76K PPS
        USART1(PA9/PA10)→ESP32
 ESP32: +5V (C24 100µF/C25 10µF/C26 0.1µF), GND共通, →WiFi
 L76K : VCC←3.3V/5V, GND共通 （HATはPiに挿さず配線）
```

---

## 20. ネットリスト（Net : 接続ピン）

> 形式：`ネット名 : 部品.ピン, ...`。ICのピンは機能名（番号はDS確認）。STM32はNUCLEO-F446REのピン名。

### 電源・グラウンド
```
AC_L_BR   : L_NODE, F2.1                          ; 自給電分岐(シャント上流)
AC_TAP_L  : F2.2, U6.Vin_L                         ; HLK AC入力(L)
AC_TAP_N  : N_NODE, U6.Vin_N                       ; HLK AC入力(N)
+5V       : U6.+Vout, L1.1, C43.1, C45.1            ; === HLK内蔵で絶縁 === HLK DC出力(π入力側)
+5V_F     : L1.2, NUCLEO.E5V, ESP32.5V, U4.VIN, U4.EN, C44.1, C46.1, C16.1, C17.1, C24.1, C25.1, C26.1  ; π後(π出力側C46)。U4.EN=VINで常時ON
+3.3V_A   : U4.VOUT, U4.SENSE, U2.AVDD, U1.VDD2, U5.VDD2, C8.1, C9.1, C18.1, C19.1,
            C20.1, C21.1, C28.1, C29.1
+3.3V_D   : NUCLEO.3V3, U2.DVDD, L76K.VCC, C10.1, C11.1
AGND      : U2.AGND, U1.GND2, U5.GND2, R4(基準系は信号側),
            C2.2, C3.2, C6.2, C7.2, C8.2, C9.2, C12.2, C18.2, C19.2,
            C20.2, C21.2, C28.2, C29.2, U4.GND
DGND      : U2.DGND, NUCLEO.GND, ESP32.GND, L76K.GND, C10.2, C11.2, C24.2, C25.2, C26.2,
            U6.−Vout, C43.2, C44.2, C45.2, C46.2, C16.2, C17.2   ; HLK −Vout=安全側基準(フローティング)
※ AGND-DGND は U2 直下スター1点で接続
※ 安全側GND（DGND）は HLK-10M05 の絶縁により測定線から分離される。危険側(L_NODE/N_NODE)とは接続しない
```

### 商用・電圧チャネル
```
L_NODE    : F1.2(→SW1.1→)SW1.2, R1.1, Rsh.1, F2.1   ; (T2.SEC1経由) ★自給電もここで分岐(Rsh上流)
L_LOAD    : Rsh.2, 負荷L
N_NODE    : T2.SEC2, R4.2, U1.INN, U1.HGND, U6.Vin_N, 負荷N
VDIV_A    : R1.2, R2.1
VDIV_B    : R2.2, R3.1
VDIV_TAP  : R3.2, R4.1, U1.INP
VOUTP_AMC : U1.OUTP, R5.1
VOUTN_AMC : U1.OUTN, R6.1
VADC0P    : R5.2, C1.1, C2.1, U2.AIN0P
VADC0N    : R6.2, C1.2, C3.1, U2.AIN0N
```

### 電流チャネル（シャント + AMC3302）
```
SH_HI     : Rsh.1(=L_NODE側ケルビン), U5.INP
SH_LO     : Rsh.2(=L_LOAD側ケルビン), U5.INN, U5.HGND
IOUTP_AMC : U5.OUTP, R12.1
IOUTN_AMC : U5.OUTN, R13.1
IADC1P    : R12.2, C5.1, C6.1, U2.AIN1P
IADC1N    : R13.2, C5.2, C7.1, U2.AIN1N
```

### AMC3330 / AMC3302 高圧側デカップリング（DS §7.4準拠）
```
U1_HVDCDC : U1.DCDC_OUT, U1.HLDO_IN, C(1nF), C(1µF)→U1.HGND
U1_HLDO   : U1.HLDO_OUT, C(1nF), C(0.1µF)→U1.HGND
U1_LVDCDC : U1.LDO_OUT, U1.DCDC_IN, C(0.1µF)→U1.GND   ; U1.DCDC_GND=U1.GND, U1.DCDC_HGND=U1.HGND
U5_HVDCDC : U5.DCDC_OUT, U5.HLDO_IN, C30(1µF), C31(1nF)→U5.HGND
U5_HLDO   : U5.HLDO_OUT, C32(0.1µF), C33(1nF)→U5.HGND
U5_LVDCDC : U5.LDO_OUT, U5.DCDC_IN, C34(0.1µF)→U5.GND  ; U5.DCDC_GND=U5.GND, U5.DCDC_HGND=U5.HGND
```

### ADC クロック・デジタルIF
```
ADC_CAP   : U2.CAP, C12.1
MCO_CLK   : NUCLEO.PA8(MCO1), U2.CLKIN
SPI_SCLK  : NUCLEO.PA5, U2.SCLK
SPI_MISO  : NUCLEO.PA6, U2.DOUT
SPI_MOSI  : NUCLEO.PA7, U2.DIN
SPI_CS    : NUCLEO.PA4, U2./CS
ADC_DRDY  : NUCLEO.PB0, U2./DRDY
ADC_SYNC  : NUCLEO.PC0(予備GPIO), U2./SYNC-RESET
```

### GPS / ESP32
```
GPS_PPS   : NUCLEO.PA0(TIM2_CH1), L76K.PPS
GPS_TX    : L76K.TX, NUCLEO.PA3(USART2_RX)
GPS_RX    : NUCLEO.PA2(USART2_TX), L76K.RX
ESP_RX    : NUCLEO.PA9(USART1_TX), ESP32.RX
ESP_TX    : NUCLEO.PA10(USART1_RX), ESP32.TX
```

### 部品ピン凡例
```
抵抗/コンデンサ : .1=一端, .2=他端（無極性。電解C24はC24.1=+）
Rsh             : .1=L_NODE側, .2=L_LOAD側（電流経路）。INP/INNはケルビンで別取り出し
U1 AMC3330      : INP,INN,HGND,OUTP,OUTN,VDD2(=VDD),GND2(=GND) ＋DC-DC系
                  (DCDC_OUT,DCDC_HGND,HLDO_IN,HLDO_OUT,LDO_OUT,DCDC_IN,DCDC_GND,DIAG,NC)
U5 AMC3302      : 同上（±50mV入力のシャント用絶縁アンプ）
U2 ADS131M02    : AVDD,AGND,DVDD,DGND,CAP,AIN0P,AIN0N,AIN1P,AIN1N,
                  CLKIN,SCLK,DIN,DOUT,/CS,/DRDY,/SYNC-RESET
U4 ADP7142(LDO) : VIN(→+5V_F), GND(→AGND), EN(→VIN 常時ON), SENSE/ADJ(→VOUT), VOUT(→+3.3V_A)
                  TSOT-23-5: 1=VIN,2=GND,3=EN,4=SENSE,5=VOUT。入出力C≥2.2µF（C16/C18=10µF）
U6 HLK-10M05    : Vin_L,Vin_N(AC入力=危険側), +Vout,−Vout(DC5V=安全側)
L1              : .1=+5V(HLK直後), .2=+5V_F（πフィルタ直列素子。大電流ﾋﾞｰｽﾞ≥2A/DCR≤50mΩ 例:村田BLM31）
F2 ヒューズ      : .1=L_NODE側, .2=U6.Vin_L側
```

> このネットリストはKiCad等での回路図化・配線チェックの下敷き用。最終的に各ICデータシートのピン番号・推奨デカップリングで補正すること。
> AMC3330/AMC3302のDC-DC系ピン（DCDC_OUT/HLDO_IN/HLDO_OUT/LDO_OUT/DCDC_IN/DCDC_GND/DCDC_HGND）は
> データシート(SBASA34B等)の指定どおり相互接続し、高圧側Cは各IC HGND、低圧側Cは各IC GNDへ戻すこと。

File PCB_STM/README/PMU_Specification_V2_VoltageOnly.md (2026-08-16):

# 単相PMU 試作機 仕様書 — Version 2（電圧のみ / 電流計測なし）

**対象**：単相100V（コンセント地点）の**電圧**同期フェーザ計測装置（ラボ試作・教育/研究用）
**版**：V2.0（本体 `PMU_Specification.md` v3.2 から **電流計測部（シャント/AMC3302/電流ch）を削除**した派生版）
**構成方針**：STM32で決定的サンプリング＋フェーザ演算／ESP32でWiFi送信／GPSで時刻同期／測定線から自給電

> **本体との違い（削除したもの）**：
> - **電流シャント Rsh**、**電流用絶縁アンプ AMC3302(U5)**、**電流ch AAF(R12/R13/C5/C6/C7)**、**ADC ch1(AIN1)** を削除。
> - アルゴリズムから **電力量(P/Q/力率)** と **電流の校正** を削除。フェーザは **電圧のみ（Vmag/Vang/f/ROCOF）**。
> - **シャントが無いため「分岐はシャント上流」という制約が消滅** → 自給電のAC入力は L-N から自由に分岐可。
>
> **本体から引き継ぐもの**：電圧フロントエンド（分圧＋AMC3330）、AAF、ADC（ADS131M02, ch0のみ）、GPS時刻同期、
> **自給電電源（HLK-10M05＋πフィルタ＋ADP7142 LDO）**、C37.118出力。

---

## 1. 確定構成（主要部品）

| 役割 | 部品 | 備考 |
|---|---|---|
| MCU（取得・演算） | **STM32F446RE（NUCLEO-F446RE）** | FPU搭載、タイマ＋DMA |
| WiFi通信 | **ESP32（ESP32-WROOM-32E 開発ボード）** | C37.118 over WiFi 送信 |
| GPS（時刻同期） | **Waveshare L76K GPS HAT** | 1PPS出力、GPS/GLONASS/BeiDou/QZSS。Piに挿さずSTM32へ配線 |
| ADC | **ADS131M02**（**ch0のみ使用**） | 2ch・24bit・ΔΣ、SPI。1ch版 **ADS131M01** でも可 |
| 絶縁アンプ（電圧） | **AMC3330** | ±1V入力・**固定ゲイン2.0**・絶縁DC-DC内蔵 |
| 絶縁AC-DCモジュール | **HLK-10M05（AC100-240V→DC5V 2A / 10W）** | 自給電の主電源。強化絶縁 |
| アナログ用LDO | **ADP7142（3.3V固定, TSOT-23-5：AUJZ-3.3 / LFCSP：ACPZ-3.3）** | +5V_Fから ADC AVDD / AMC VDD2。入出力C≥2.2µF |
| 一次側ヒューズ（電源分岐） | **F2：AC250V/T/0.5A** | HLK AC入力保護 |

> **削除**：電流シャント Rsh、AMC3302(U5)、電流ch AAF、R1SE-0505（本体v3.2で既に廃止）。

---

## 2. システムブロック図

```
        危険側(AC100V, 測定線)          ┊絶縁┊            安全側(フローティング)
 L ─[F1]─[SW1]─●(L_NODE)───────────────────────────────→ 負荷へ(L)/開放可
              │  │
              │ (電圧タップ)
              │ 分圧(510k×3+5.1k)→ AMC3330(絶縁+DCDC) ─────────→ AAF → ADS131M02 ch0
   ┌──[F2]────┘  │                                                          │SPI/DRDY
   │(電源分岐)    │   ┊電源側の絶縁境界(HLK内蔵)┊                             │
 [HLK-10M05]─────┼─→ +5V(2A) ─┬─→ Nucleo(STM32) ──────────────────────────┤
 絶縁AC-DC 5V/2A  │            ├─→ ESP32 ─WiFi→ PC/PDC
   │            │            └─→ ADP7142→+3.3V_A(アナログ: ADC/AMC)
 N ●───────────●(N_NODE)────────────────────────────────→ 負荷へ(N)
        L76K GPS HAT ─UART/PPS─→ STM32(入力キャプチャ)   ↑MCO(8MHz)→ADC CLKIN
```

- **絶縁境界（信号）**：電圧ch＝**AMC3330**（容量結合の強化絶縁＋内蔵DC-DC）。
- **絶縁境界（電源）**：**HLK-10M05**。AC入力＝危険側、DC出力＝安全側。安全側は**二重絶縁**でフローティング。
- **電圧のみ**：センサ→絶縁アンプ→AAF→ADC ch0。出力コモンモードはAMC3330が自己生成（VDD2/2）。
- **負荷は任意**：電圧測定は L-N 間電圧を見るだけなので、負荷が無く（開放）ても測れる。

---

## 3. 電源アーキテクチャ（測定線からの自給電）

**電源フロー**：
```
測定線 L_NODE ─[F2]─ HLK-10M05(AC100V→DC5V 2A) ═絶縁═ +5V
   └[C43/C45]─[L1 大電流ﾋﾞｰｽﾞ≥2A]─[C46]─ +5V_F ─┬─→ Nucleo(E5V, JP5=E5V)
                                                  ├─→ ESP32（+5V, バルク470µF級を直近）
                                                  └─→ ADP7142(3.3V固定LDO) ─ +3.3V_A（ADC AVDD / AMC VDD2）
```

| レール | 供給先 | 供給元 |
|---|---|---|
| （AC入力） | HLK-10M05 Vin(L/N) | 測定線 L_NODE-N_NODE（**シャントが無いので分岐位置は自由**）、F2で保護 |
| +5V / +5V_F | ESP32 / LDO入力 / Nucleo(E5V) | **HLK-10M05 出力 5V/2A**（自給電・絶縁済） |
| +3.3V（デジタル） | STM32 / ADS131M02 DVDD / L76K | Nucleo 3.3V（E5V経由の内蔵LDO） |
| +3.3V（アナログ） | ADS131M02 AVDD / **AMC3330 VDD2** | **+5V_F → ADP7142(3.3V固定LDO)** |

- **消費見積り**：Nucleo ~150mA / ESP32 ~120mA(ピーク~500mA) / GPS ~40mA / アナログ ~30mA → 合計約 **0.3A(平均)/0.7A(ピーク)**。HLK-10M05(2A)で余裕。
- **ノイズ対策**：HLK出力に**π型フィルタ（C-L-C）**＋アナログは**ADP7142(低ノイズLDO)** で再生成 → HLKのSWノイズをADC基準へ入れない。
- グラウンド：**HLK −Vout=安全側基準（DGND, フローティング）**。AGND-DGNDはADC直下1点スター。
- （電流計測が無いため、シャント・VCM基準・負担抵抗は一切不要。）

### 3.1 HLK周りのフィルタ配線

```
 HLK +Vout ●──┬────────┬──[ L1 ]──┬────────┬────────┬──→ 各負荷
             (+5V)     │  ﾋﾞｰｽﾞ  (+5V_F)   │        │
              │        │  ≥2A     │        │        │
            C43(100µF) C45(10µF)  C46(10µF) C44      C16+C17
             │        │           │     470-1000µF  10µF+0.1µF
 HLK −Vout ●──┴────────┴───────────┴────────┴────────┴──● DGND
              ↑π入力側              ↑π出力側  ↑ESP32直近 ↑LDO入力
```

- 全コンデンサの片脚は DGND。直列素子は L1 のみ。電解は極性注意（−をDGND）。
- **L1**：大電流フェライトビーズ（1206以上/定格≥2A/DCR≤50mΩ/例 村田BLM31）or 4.7〜10µH/≥2Aインダクタ。

### 3.2 ADP7142（TSOT-23-5, 3.3V固定）ピン接続

| ピン | 名前 | つなぐ先 |
|:---:|---|---|
| 1 | VIN | +5V_F（入力C≥2.2µF＝C16 10µF/C17 0.1µF→DGND） |
| 2 | GND | AGND |
| 3 | EN | VIN(=+5V_F) に直結（常時ON） |
| 4 | SENSE/ADJ | VOUT(5) に接続（負荷点） |
| 5 | VOUT | +3.3V_A（出力C≥2.2µF＝C18 10µF/C19 0.1µF→AGND） |

- SSピンはTSOT-23-5には無い（起動~380µs固定）。LFCSP品なら開放（GND直結禁止）。

---

## 4. 電圧フロントエンド設計

AMC3330：±1Vバイポーラ入力（中点バイアス不要）・**固定ゲイン2.0**（データシート確認済）。
分圧比は「ゲイン2倍後の出力がADC FSR(±1.2V)に収まる」よう設定。

| 部品 | 値 | 計算/備考 |
|---|----|---|
| 分圧 上側 Rhi | **510kΩ ×3 直列（1.53MΩ）** | 各≈33V分担で耐圧確保。0.1%/≤25ppm/薄膜 |
| 分圧 下側 Rlo | **5.1kΩ** | 分圧比 ≈ 1/301 |
| 入力ピーク | 141Vpk ÷301 ≈ **0.47Vpk** | AMC3330 ±1V内 |
| AMC出力（×2）| 0.47Vpk×2 ≈ **0.94Vpk** | ADS131M02 FSR ±1.2V内（約22%余裕）|
| 分圧電流 | 約65µA（消費約6.5mW） | Rhiでほぼ決まる |
| 出力コモンモード | AMC3330が VDD2/2（≈1.65V@3.3V）を生成 | ADC入力CMに整合 |

- **重要**：`141Vpk × 分圧比 × 2 ≤ 1.2V` を満たすこと。510kΩは working voltage ≥33V/本。

---

## 5. アンチエイリアスフィルタ（AAF）

電圧ch差動RCフィルタ（パッシブ）。

| 部品 | 値 | 備考 |
|---|----|----|
| 直列R（各ライン） | **1kΩ ×2**（0.1%/薄膜） | R5/R6 |
| 差動C（Cdiff） | **47nF**（C0G/NP0 or フィルム） | fc_diff ≈ 1/(2π·2kΩ·47nF) ≈ **1.7kHz** |
| コモンモードC（Ccm） | **1nF ×2**（C0G） | 各ラインからAGNDへ（任意） |

- fc≈1.7kHz は fs/2（≈3.9kHz）より十分下。50Hzで約−1.7°の群遅延 → **実測補償**。
- （電流chが無いため「両ch同一化」は不要。ただし群遅延は絶対位相（UTC基準）に効くので校正で補償。）

---

## 6. ADCサブシステム（ADS131M02, ch0のみ）

| 項目 | 設計値 |
|---|---|
| CLKIN | **STM32 MCO出力 8MHz**（PA8/MCO1。Nucleo HSE由来） |
| fMOD | 4MHz（CLKIN/2） |
| OSR | **512** |
| データレート fDATA | **≈7812.5 SPS**（50Hzで約156サンプル/周期、60Hzで約130） |
| ゲイン | 1（FSR ±1.2V、内部Vref 1.2V） |
| インタフェース | SPI（STM32マスタ）、**DRDY→EXTI割込**、DMA転送 |
| ch割当 | **ch0＝電圧**（ch1は未使用：入力はデータシート指定に従いAGND/中点へ処理） |

> **1ch版 ADS131M01 を使う場合**：ピン数が減り配線簡素。設計値（OSR/fDATA/Vref）は同一。

---

## 7. 時刻同期（L76K GPS HAT）

- HATはPi用だが、**UART(TX/RX)・PPS・電源・GND をSTM32へ配線**して使用（Piに挿さない）。**PPSピンが端子に出ていることを確認**。
- L76K：GPS/GLONASS/BeiDou/**QZSS対応**、1PPS精度 <30ns（50Hzで約0.0005°相当）。
- **PPS → STM32タイマ入力キャプチャ**（sub-µsでエッジ時刻取得）。UARTでNMEA受信。屋外/窓際で運用。

---

## 8. 制御・通信

- **STM32 → ESP32：UART（例 921600bps）**で電圧フェーザ結果（タイムスタンプ・V振幅/位相・f・ROCOF）を転送。
- **ESP32**：受信データを **C37.118.2 フレーム化 → WiFi(UDP/TCP)** でPC/PDCへ。
- 両者3.3Vロジック・GND共通、レベルシフト不要。時刻クリティカルパスはSTM32内で完結。

---

## 9. STM32ピン割当（例：NUCLEO-F446RE）

| 機能 | ピン例 |
|---|---|
| ADC SPI（SCLK/MISO/MOSI/CS） | SPI1: PA5/PA6/PA7/PA4 |
| ADC DRDY | EXTI: PB0 |
| ADC /SYNC-RESET | 予備GPIO（例 PC0） |
| ADC CLKIN | **MCO1: PA8（8MHz出力）** |
| GPS PPS | タイマ入力キャプチャ: TIM2_CH1 / PA0 |
| GPS UART | USART2: PA2(TX)/PA3(RX) |
| ESP32 UART | USART1: PA9(TX)/PA10(RX) |

---

## 10. 受動部品リスト（抵抗・コンデンサ）と数量

### 抵抗（Thin Film、精度が効く所は 0.1%/≤25ppm）

| 値 | 用途 | 必要数 | 推奨購入数 | 仕様 |
|----|---|:---:|:---:|---|
| 510kΩ | 分圧上側（3直列） | 3 | **10** | 0.1%/≤25ppm/耐圧≥33V |
| 5.1kΩ | 分圧下側（Rlo） | 1 | **5** | 0.1%/≤25ppm（5.11kΩ/E96可）|
| 1kΩ | AAF（2本） | 2 | **10** | 0.1%/薄膜 |

> **削除**：シャント Rsh、電流ch AAF 1kΩ×2、（v1.0の負担抵抗/VCM系は本体で既に廃止）。

### コンデンサ

| 値 | 用途 | 必要数 | 推奨購入数 | 種類 |
|----|---|:---:|:---:|---|
| 0.1µF | 各IC電源デカップリング | ~8 | **20** | X7R 50V |
| 1µF | ADC(AVDD/DVDD/CAP)・AMC3330(VDD2・DC-DC高圧側) | ~6 | **15** | X7R 50V |
| 10µF | LDO入出力(C16/C18≥2.2µF)・AVDDバルク・πフィルタ(C45/C46) | ~5 | **15** | X5R/X7R |
| 100µF | 5Vバルク（ESP32突入・HLK出力C43） | 2 | **5** | 電解/タンタル |
| 470-1000µF | ESP32直近バルク（C44、送信ピーク吸収） | 1 | **3** | 電解 |
| 47nF | AAF 差動C（C1） | 1 | **5** | C0G/NP0 or フィルム |
| 1nF | AAF コモンモードC（C2/C3）・AMC高圧側 | ~4 | **10** | C0G |

### 電源・自給電部

| 部品 | 記号 | 値/型 | 必要数 | 備考 |
|---|---|---|:---:|---|
| 絶縁AC-DCモジュール | U6 | HLK-10M05（AC100-240V→DC5V 2A） | 1 | 強化絶縁 |
| πフィルタ用 | L1 | 大電流ﾋﾞｰｽﾞ≥2A/DCR≤50mΩ（例 村田BLM31）or 4.7-10µH/≥2A | 1 | 全電流が通る |
| アナログ用LDO | U4 | ADP7142（3.3V固定, AUJZ-3.3/ACPZ-3.3） | 1 | EN→VIN, SENSE→VOUT, 入出力C≥2.2µF |
| 電源分岐ヒューズ | F2 | AC250V/T/0.5A ＋ホルダ | 1 | HLK AC入力保護 |

> **削除**：AMC3302(U5)のデカップリング一式、シャント関連。

---

## 11. アルゴリズム

### 11.1 取得（Acquisition）
1. STM32がMCOで8MHzをADC CLKINへ供給 → ADCは固定 fDATA(≈7812.5SPS) で自走。
2. **DRDY割込**ごとにSPI/DMAで **ch0（電圧）サンプル** を取得し、リングバッファへ。
3. **PPS立ち上がり**をタイマ入力キャプチャで捕捉 → タイマカウントを保持。
4. サンプルカウンタとPPSキャプチャ値から、各サンプルの**絶対時刻（UTC）**を復元（PPS毎に基準更新）。

### 11.2 フェーザ推定（Phasor Estimation）
- 報告周期（例 50 fps、設定可）ごとに、UTC基準時刻に整列した窓のサンプルを抽出。
- 基本波フェーザを **DFT** で算出：
  - `X = (2/N) Σ x[n]·e^(−j2πk0 n/N)`（k0＝基本波ビン）
  - この正規化で **|X|＝ピーク振幅**、位相 = arg(X)。**C37.118は振幅=RMS慣例** → **Vrms=|X|/√2**。
- **補間DFT（IpDFT）**：Hann窓＋ピーク近傍2〜3ビンから真の周波数・振幅・位相を補間。

### 11.3 周波数・ROCOF
- IpDFTで得た基本波周波数 f を出力。連続推定値から **ROCOF = df/dt**（平滑化付き差分）。

### 11.4 校正補償（適用順）
1. **振幅スケール**：分圧比・**AMC3330ゲイン**の実測係数で物理量へ換算。
2. **位相オフセット補償**：電圧chの遅れ（AMC3330＋AAF＋ADC）を校正テーブルで減算。
3. **AAF群遅延補償**：実測群遅延を位相から差し引く。

> **削除**：電力量(P/Q/力率)、電流の振幅/位相校正（電流chが無いため）。

### 11.5 出力（C37.118）
- STM32 → ESP32（UART）：`{UTCタイムスタンプ, Vmag(RMS), Vang, f, ROCOF, status}`。
- ESP32：C37.118.2 データフレーム化 → WiFi送信（電圧フェーザのみ）。

---

## 12. 校正手順（TVEを決める要）

1. **振幅校正**：既知の基準電圧を入力し、スケール係数を決定。
2. **位相校正**：基準電圧に対する電圧chの位相オフセットを実測 → テーブル化（残差はAAF群遅延が主成分）。
3. **群遅延校正**：AAFカットオフ確定後、群遅延を実測し補償。
4. **検証**：基準器で電圧TVE・周波数精度を確認。

---

## 13. テスト

| 入力 | 用途 |
|---|---|
| 商用100V（コンセント） | 実運用の電圧フェーザ観測 |
| 可変トランス/基準電圧源 | 振幅校正（既知電圧を印加） |
| 基準位相/GPS同期の基準器 | 位相・周波数の検証 |

> **負荷は不要**：電圧測定は L-N 間電圧を見るだけなので、負荷（電流を流す機器）は無くてよい。
> （本体v3.2の「白熱電球/電力抵抗」等の電流用テスト負荷は本V2では不要。）

---

## 14. 安全設計（必須）

- L側に**ヒューズ（AC250V・T・ceramic HBC）＋電源SW**（F1/SW1）。**電源分岐にも専用ヒューズ F2**。
- 危険側（分圧器・**HLK AC入力側**・配線）は**絶縁ケース＋端子カバー**で露出させない。
- 絶縁境界（**AMC3330・HLK-10M05**）より先が安全側 → PC/WiFiデバッグ安全。
- **自給電の絶縁**：安全側は **HLK（電源）＋AMC3330（信号）の二重絶縁**で測定線からフローティング。非絶縁トランスレス電源は**禁止**。
- HLKのAC入力ピン（危険側）とDC出力ピン（安全側）を基板上で明確分離・絶縁距離確保。
- （シャントが無いので活線シャント配線の注意は不要。分圧器の高抵抗は感電エネルギーが小さいが、危険側電位であることに変わりないので露出させない。）

---

## 15. 詳細回路図（ブロック別）

### A. 商用入力・安全部（＋自給電分岐）
```
 L ●──[F1]──[SW1]──●(L_NODE)──→ 電圧タップ & ★電源分岐 & 負荷L(任意)
 N ●───────────────●(N_NODE)──→ 分圧基準 & ★電源分岐(戻り) & 負荷N(任意)
 ★自給電分岐（シャントが無いので位置自由）:
   L_NODE─[F2 0.5A]─U6.Vin(L)   U6.Vin(N)─N_NODE
 F1: AC250V/T/ceramic HBC/3〜10A   SW1: AC定格SW   U6: HLK-10M05
```

### B. 電圧チャネル（AMC3330）
```
 L_NODE─[R1 510k]─[R2 510k]─[R3 510k]─●(VDIV_TAP)─► U1.INP
                                       │
                                     [R4 5.1k]
                                       │
 N_NODE────────────────────────────────●─► U1.INN（=U1.HGND 高圧側基準）
            === 絶縁境界(U1内蔵DC-DC) ===
 U1.VDD2←+3.3V_A (C20 1µF/C21 0.1µF)  U1.GND2←AGND
 U1 DC-DC/LDO: DCDC_OUT-HLDO_IN, DCDC_HGND-HGND, LDO_OUT-DCDC_IN, DCDC_GND-GND
              HLDO_OUT(C 1nF/0.1µF→HGND), DCDC_OUT(C 1nF/1µF→HGND), DCDC_IN(C 0.1µF→GND)
 U1.OUTP─[R5 1k]─┬─► AIN0P     (C1 47nF 差動 across AIN0P/N)
 U1.OUTN─[R6 1k]─┴─► AIN0N     C2 1nF→AGND, C3 1nF→AGND
```

### C. ADC（U2 ADS131M02, ch0のみ）
```
 +3.3V_A─(C8 1µF/C9 0.1µF)─U2.AVDD   U2.AGND→AGND
 +3.3V_D─(C10 1µF/C11 0.1µF)─U2.DVDD U2.DGND→DGND
 U2.CAP─C12 1µF→AGND
 U2.AIN0P/AIN0N←電圧(AMC3330)    ; AIN1P/AIN1N=未使用（DS指定処理）
 U2.CLKIN←PA8(MCO 8MHz)
 SPI: SCLK←PA5 DIN←PA7 DOUT→PA6 /CS←PA4 /DRDY→PB0 /SYNC-RST←PC0
 ★AGND-DGNDはU2直下で1点接続
```

### D. 自給電電源部（測定線 → +5V, HLK-10M05）
```
 [危険側]              === 絶縁境界(HLK内蔵) ===        [安全側]
 L_NODE─[F2]─U6.Vin(L)                    U6.+Vout─●(+5V)
 N_NODE──────U6.Vin(N)                    U6.−Vout─●(DGND=安全側基準)
   ●(+5V) C43(100µF)→DGND / C45(10µF)→DGND        ; π入力側C（HLK出力直後）
   +5V─[L1 ﾋﾞｰｽﾞ≥2A/or 数µH]─●(+5V_F)  C46(10µF)→DGND ; L1＋C46でπ出力側
   +5V_F─┬─→ Nucleo E5V（JP5=E5V）
         ├─→ ESP32 +5V              C44(470-1000µF)→DGND（ESP32直近）
         └─→ U4(ADP7142)入力         C16(10µF)/C17(0.1µF)→DGND（LDO入力）
```

### E. アナログ低ノイズ電源（ADP7142 LDO一段）
```
 +5V_F─(C16 10µF/C17 0.1µF)─U4(ADP7142 3.3V固定)─(C18 10µF/C19 0.1µF)─+3.3V_A
 EN→VIN(常時ON)  SENSE→VOUT  GND→AGND   ; 入出力C≥2.2µF
```

### F. 制御・通信
```
 STM32: SPI1/PB0/PA8→U2   USART2(PA2/PA3)→L76K   PA0←L76K PPS   USART1(PA9/PA10)→ESP32
 ESP32: +5V (C24 100µF/C25 10µF/C26 0.1µF), GND共通, →WiFi
 L76K : VCC←3.3V/5V, GND共通
```

---

## 16. ネットリスト（Net : 接続ピン）

### 電源・グラウンド
```
AC_L_BR   : L_NODE, F2.1
AC_TAP_L  : F2.2, U6.Vin_L
AC_TAP_N  : N_NODE, U6.Vin_N
+5V       : U6.+Vout, L1.1, C43.1, C45.1            ; === HLKで絶縁 === (π入力側)
+5V_F     : L1.2, NUCLEO.E5V, ESP32.5V, U4.VIN, U4.EN, C44.1, C46.1, C16.1, C17.1, C24.1, C25.1, C26.1
+3.3V_A   : U4.VOUT, U4.SENSE, U2.AVDD, U1.VDD2, C8.1, C9.1, C18.1, C19.1, C20.1, C21.1
+3.3V_D   : NUCLEO.3V3, U2.DVDD, L76K.VCC, C10.1, C11.1
AGND      : U2.AGND, U1.GND2, U4.GND, C2.2, C3.2, C8.2, C9.2, C12.2, C18.2, C19.2, C20.2, C21.2
DGND      : U2.DGND, NUCLEO.GND, ESP32.GND, L76K.GND, C10.2, C11.2, C24.2, C25.2, C26.2,
            U6.−Vout, C43.2, C44.2, C45.2, C46.2, C16.2, C17.2
※ AGND-DGND は U2 直下スター1点で接続。危険側(L_NODE/N_NODE)とは接続しない。
```

### 電圧チャネル
```
L_NODE    : F1.2(→SW1.1→)SW1.2, R1.1, F2.1, 負荷L(任意)
N_NODE    : R4.2, U1.INN, U1.HGND, U6.Vin_N, 負荷N(任意)
VDIV_A    : R1.2, R2.1
VDIV_B    : R2.2, R3.1
VDIV_TAP  : R3.2, R4.1, U1.INP
VOUTP_AMC : U1.OUTP, R5.1
VOUTN_AMC : U1.OUTN, R6.1
VADC0P    : R5.2, C1.1, C2.1, U2.AIN0P
VADC0N    : R6.2, C1.2, C3.1, U2.AIN0N
```

### AMC3330 高圧側デカップリング（DS §7.4準拠）
```
U1_HVDCDC : U1.DCDC_OUT, U1.HLDO_IN, C(1nF), C(1µF)→U1.HGND
U1_HLDO   : U1.HLDO_OUT, C(1nF), C(0.1µF)→U1.HGND
U1_LVDCDC : U1.LDO_OUT, U1.DCDC_IN, C(0.1µF)→U1.GND
```

### ADC クロック・デジタルIF / GPS / ESP32
```
ADC_CAP   : U2.CAP, C12.1
MCO_CLK   : NUCLEO.PA8(MCO1), U2.CLKIN
SPI_SCLK  : NUCLEO.PA5, U2.SCLK
SPI_MISO  : NUCLEO.PA6, U2.DOUT
SPI_MOSI  : NUCLEO.PA7, U2.DIN
SPI_CS    : NUCLEO.PA4, U2./CS
ADC_DRDY  : NUCLEO.PB0, U2./DRDY
ADC_SYNC  : NUCLEO.PC0, U2./SYNC-RESET
GPS_PPS   : NUCLEO.PA0(TIM2_CH1), L76K.PPS
GPS_TX    : L76K.TX, NUCLEO.PA3(USART2_RX)
GPS_RX    : NUCLEO.PA2(USART2_TX), L76K.RX
ESP_RX    : NUCLEO.PA9(USART1_TX), ESP32.RX
ESP_TX    : NUCLEO.PA10(USART1_RX), ESP32.TX
```

### 部品ピン凡例
```
U1 AMC3330      : INP,INN,HGND,OUTP,OUTN,VDD2(=VDD),GND2(=GND) ＋DC-DC系
U2 ADS131M02    : AVDD,AGND,DVDD,DGND,CAP,AIN0P,AIN0N,(AIN1P,AIN1N=未使用),
                  CLKIN,SCLK,DIN,DOUT,/CS,/DRDY,/SYNC-RESET
U4 ADP7142(LDO) : 1=VIN(→+5V_F),2=GND(→AGND),3=EN(→VIN),4=SENSE(→VOUT),5=VOUT(→+3.3V_A)。入出力C≥2.2µF
U6 HLK-10M05    : Vin_L,Vin_N(AC入力=危険側), +Vout,−Vout(DC5V=安全側)
L1              : .1=+5V(HLK直後), .2=+5V_F（大電流ﾋﾞｰｽﾞ≥2A/DCR≤50mΩ）
F2 ヒューズ      : .1=L_NODE側, .2=U6.Vin_L側
```

> このネットリストはKiCad等の下敷き用。最終的に各ICデータシートのピン番号・推奨デカップリングで補正すること。

---

## 17. 要確認事項（データシート）

- **AMC3330**：固定ゲイン2.0・出力コモンモード値・DC-DCピン結線とデカップリング推奨部品。
- ADS131M02（またはADS131M01）：CAPピン等の推奨デカップリング、入力コモンモード範囲、OSR設定、**未使用ch1の処理**。
- **HLK-10M05**：AC入力範囲・絶縁耐圧・出力2A・出力リプル/ノイズ実測値・ピン配置。
- **ADP7142**：3.3V固定品番・入出力C≥2.2µF・EN/SENSE結線。
- L76K GPS HAT：PPSピンの引き出し位置、UART電圧レベル。
- STM32 MCO：8MHz出力設定（HSE経由）とADC CLKIN要件の整合。

---

## 18. 本体（電圧＋電流版）との対応

| 項目 | 本体 v3.2 | 本V2（電圧のみ） |
|---|---|---|
| 電流計測 | シャント1.5mΩ＋AMC3302＋ch1 | **削除** |
| ADC使用ch | ch0（電圧）＋ch1（電流） | **ch0のみ**（ADS131M01可） |
| 出力 | V,I,P,Q,力率,f,ROCOF | **V,f,ROCOF のみ** |
| 自給電の分岐制約 | シャント上流必須 | **制約なし（L-N自由）** |
| テスト負荷 | 電流用（電球/抵抗）必要 | **不要（電圧のみ）** |
| 電源部 | HLK-10M05＋πフィルタ＋ADP7142 | **同一** |

*(本V2は `PMU_Specification.md` v3.2 の派生。電源・電圧FE・GPS・通信は本体と共通で、電流計測のみ削除。)*

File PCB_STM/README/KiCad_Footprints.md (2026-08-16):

# KiCad シンボル/フットプリント割り当て表（PMU v2.0）

`PMU_Specification.md` v2.0（シャント＋AMC3302）の部品に、KiCadのシンボル・フットプリントを割り当てたもの。
ライブラリ名は KiCad 標準ライブラリ基準。**絶縁IC・シャントは land pattern が特殊なので注記を必ず確認**。

---

## 1. 能動部品（IC・モジュール）

| 記号 | 部品 | シンボル（例）| フットプリント（例）| 注意 |
|---|---|---|---|---|
| U1 | AMC3330（電圧絶縁アンプ）| 自作 or `Amplifier_Difference` 系 | **TIのDWE推奨ランドパターン**（SOIC-16 ワイド）| 絶縁クリアレージ重要・DSの推奨パターン使用 |
| U5 | AMC3302（電流絶縁アンプ）| 同上（U1と同ピン配置）| **同上（DWEはU1と同一）** | U1と完全同形状 |
| U2 | ADS131M02（24bit ADC）| 自作 | `Package_SO:TSSOP-16_4.4x5mm_P0.65mm` | TSSOP-16 |
| U3 | RECOM R1SE-0505（絶縁DCDC・任意）| `Converter_DCDC` | RECOM R1SE 専用（SIP/SMD・DSの寸法で自作）| 任意部品 |
| U4 | 3.3V LDO（NJM2845等・任意）| `Regulator_Linear` | パッケージに合わせる（SOT-23/TO-252等）| 採用品で確定 |

> **絶縁IC(U1/U5)**：AMC3330/AMC3302はDWEパッケージ（ワイドSOIC-16, 沿面距離確保形）。
> KiCad標準の `SOIC-16W_7.5x10.3mm_P1.27mm` が近いが、**必ずTIデータシートの推奨ランドパターンと照合**。
> 絶縁部はパッド間スリット等で creepage を確保すること。

---

## 2. 抵抗

| 記号 | 値 | フットプリント | 注意 |
|---|----|---|---|
| R1,R2,R3 | 510k | `Resistor_SMD:R_0805_2012Metric` | 耐圧分担。3直列を離して配置 |
| R4 | 10k | `R_0805_2012Metric` | 分圧下側 |
| R5,R6,R12,R13 | 1k | `R_0805_2012Metric` | AAF・両ch同一 |
| **Rsh** | 1.5mΩ | `Resistor_SMD:R_2512_6332Metric` | **ケルビン(4端子)センス配線**。電流経路とセンス経路を分離 |

> **シャント Rsh の配線が最重要**：電流が流れる太線(L_NODE↔L_LOAD)と、AMC3302へ行くセンス線(INP/INN)を
> **パッドの内側エッジから別々に取り出す（ケルビン接続）**。これを怠ると配線抵抗が誤差になる。
> 厳密な4端子が必要なら Vishay WSK2512 / Susumu PMR 系（4パッド品）＋専用フットプリントに変更。

---

## 3. コンデンサ

| 記号 | 値 | フットプリント | 注意 |
|---|----|---|---|
| C1,C5 | 47nF | `Capacitor_SMD:C_1206_3216Metric` | C0G。フィルム代替時はTH用に変更 |
| C2,C3,C6,C7 ほか1nF | 1nF | `C_0805_2012Metric` | C0G |
| 0.1µF 各種（C9,C11… C29,C32,C34）| 0.1µF | `C_0805_2012Metric` | X7R |
| 1µF 各種（C8,C10,C12… C20,C28,C30）| 1µF | `C_0805_2012Metric` | X7R |
| C16,他10µF | 10µF | `C_0805_2012Metric` | X5R/X7R |
| C14,C15系 4.7µF | 4.7µF | `C_0805_2012Metric` | X7R |
| C24（100µF）| 100µF | `Capacitor_THT:CP_Radial_D6.3mm_P2.50mm` | 電解・スルーホール・極性注意 |

> デカップリングCは各**ICの電源ピン直近**に配置（フットプリント配置時に最優先）。
> AMC3330/AMC3302の高圧側C(HLDO_OUT/DCDC_OUT系)は **HGND側**、低圧側は **GND側** に戻す。

---

## 4. コネクタ（ボードを挿すソケット・2.54mmピッチ）

| 記号 | 対象 | フットプリント | 注意 |
|---|---|---|---|
| J_NUC1/2 | NUCLEO Morpho CN7/CN10 | `Connector_PinSocket_2.54mm:PinSocket_2x19_P2.54mm_Vertical` ×2 | CN7-CN10間隔は実測/ST機械図で確認 |
| J_ESP | ESP32 DevKit | `PinSocket_1x19_P2.54mm_Vertical` ×2 | **2列の幅は実機を実測**（22.86 or 25.4mm等）|
| J_GPS | L76K GPS HAT | `PinSocket_2x20_P2.54mm_Vertical`（必要ピンのみでも可）| **PPSピン位置を実測確認** |
| J_AC | AC入力/負荷 端子台 | `TerminalBlock` 5.08mmピッチ（穴径1.3mm）| 例：秋月TB111-2（前出）|

> いずれも **2.54mmピッチ**で確定。ボードの**列間隔（横幅）だけ実測**して合わせる。

---

## 5. フットプリント割り当ての進め方（KiCad手順）

1. 回路図（Schematic Editor）に各シンボルを配置（U1/U5は自作 or 既成、Rsh・端子台など）。
2. **Tools → Assign Footprints** で上表のフットプリントを割り当て。
3. U1/U5・Rsh は標準ライブラリに完全一致が無いので、**Footprint Editorで自作 or 既成を複製して修正**。
   - U1/U5：TIのDWE推奨ランド（沿面スリット込み）
   - Rsh：2512に**ケルビンのセンスパッド**を追加
4. PCB Editorで配置：**デカップリングCをICピン直近**、シャントのケルビン配線、AGND/DGNDのU2直下1点接続。
5. DRC（特に**AC100V部の沿面・クリアランス**、絶縁境界をまたぐ配線がないか）を確認。

---

## 6. 特に注意（v2.0固有）

- **絶縁境界**：U1(電圧)とU5(電流)の**高圧側(HGND側)と低圧側(GND側)を、配線・ベタGNDで絶対に繋がない**。
  境界をまたぐのは各ICの内部絶縁のみ。基板上は溝/スリットで分離。
- **シャントは活線(L)上**：Rsh周辺は危険電位。端子カバー・絶縁を確実に。
- **U1とU5は同一フットプリント**（DWE）なので、1つ作れば流用可。
- ADS131M02(U2)直下で **AGND-DGND 1点接続** のランド/ジャンパを用意。

---

## 7. U1/U5 共用フットプリント（AMC3330/AMC3302 DWE）作成手順

> AMC3330・AMC3302は**同一の DWE パッケージ**（ワイドSOIC-16, 1.27mmピッチ, 本体10.3×10.3mm）。
> 1つ作れば両方に割り当てられる。**絶縁部品なのでランドはTI公式寸法を使う**こと。

### 方式A：TI公式フットプリントを使う（推奨・最短・最安全）
1. TIの製品ページ（AMC3330 / AMC3302）→ **「Design & development」→ CAD/CAE symbols**。
2. **Ultra Librarian** で *KiCad* 形式を選び、シンボル＋フットプリントをDL。
3. KiCadのライブラリに取り込み、U1・U5へ割り当て。
4. データシート **§7.5 Layout** の推奨ランドと照合（特に絶縁ギャップ）。

→ 自分で寸法を測らずに済み、**沿面距離(creepage)も公式保証**。まずこれを試す。

### 方式B：Footprint Editorで自作（公式が使えない時）
1. KiCad → **Footprint Editor** → New（名前 `AMC33xx_DWE_SOIC16`）。
2. **パッドを16個**配置。共通設定：
   - Type：**SMD**、Shape：Roundrect（ピン1のみ目印に矩形 or 別シルク）
   - **ピッチ：1.27mm**
   - パッド寸法：約 **0.60 × 2.20mm**（暫定。TI land patternで確定）
   - 行間（左右パッド列の中心間）：**DWEのland patternの値**（§7.5/機械図で確認。ワイド形なので≈9.5mm前後だが**必ず実値**）
3. **ピン番号の並び（標準SOIC・反時計回り）**：
   ```
   左列 上→下: 1,2,3,4,5,6,7,8
   右列 下→上: 9,10,11,12,13,14,15,16
   ```
   データシート Figure 4-1 と一致：
   ```
   1 DCDC_OUT  ┌──∪──┐ 16 DCDC_IN
   2 DCDC_HGND │     │ 15 DCDC_GND
   3 HLDO_IN   │     │ 14 DIAG
   4 NC        │     │ 13 LDO_OUT
   5 HLDO_OUT  │     │ 12 VDD
   6 INP       │     │ 11 OUTP
   7 INN       │     │ 10 OUTN
   8 HGND      └─────┘  9 GND
   ```
   左列(1-8)＝高圧側、右列(9-16)＝低圧側。
4. パッドのY座標：8ピンなら +4.445mm(ピン1) から 1.27刻みで −4.445mm(ピン8)。右列はピン9(−4.445)→ピン16(+4.445)。
5. シルク：本体外形10.3×10.3mm、ピン1マーク、**絶縁境界の線**（左右列の間）を引く。
6. **3Dモデル**（任意）：TIのSTEPを割り当て。

### 絶縁フットプリント特有の注意（最重要）
- **左列(高圧側1-8)と右列(低圧側9-16)の間に、銅・シルク・ビアを一切置かない**。
  DWEの沿面距離(creepage)8mmを基板上でも維持（パッド間に溝/スリットも有効）。
- KiCadの **Courtyard を左右で分けない**よう…ではなく、**ベタGNDを境界でまたがせない**（GNDゾーンを高圧側/低圧側で分離）。
- 高圧側パッド(HGND系)と低圧側パッド(GND系)が、基板配線で繋がっていないことを **DRC＋目視** で確認。

### 割り当て
- 完成した `AMC33xx_DWE_SOIC16` を **U1（AMC3330）と U5（AMC3302）の両方**に割り当てる（同形状）。
- ピン機能名はIC共通（INP/INN/HGND/OUTP/OUTN/VDD/GND＋DC-DC系）なので、シンボルも共用可。

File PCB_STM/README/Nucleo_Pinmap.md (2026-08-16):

# NUCLEO-F446RE ピン接続表（PMU試作機）

`PMU_Specification.md` のネットリスト（§20）と NUCLEO-F446RE のピン配置を突き合わせた、
STM32と各機器の接続一覧。

- Nucleoの物理ピンは **Arduino互換ラベル（CN5/CN6/CN8/CN9）** で表記（配線時に分かりやすいため）。
- 同じポートは ST Morpho ヘッダ（CN7/CN10）にも出ている。
- ICの実ピン番号は各データシート（ADS131M02=TSSOP-16 / AMC3330=SOIC-16）で最終確認すること。

---

## ① ADS131M02（ADC, U2）— SPI + クロック + 割込

| STM32ポート | Arduinoピン | 信号 | ADS131M02ピン | 向き |
|---|---|---|---|---|
| **PA5** | D13（CN5）| SPI1_SCK | **SCLK** | STM32→ADC |
| **PA6** | D12（CN5）| SPI1_MISO | **DOUT** | ADC→STM32 |
| **PA7** | D11（CN5）| SPI1_MOSI | **DIN** | STM32→ADC |
| **PA4** | A2（CN8）| SPI1_CS（GPIO）| **/CS** | STM32→ADC |
| **PB0** | A3（CN8）| EXTI割込 | **/DRDY** | ADC→STM32 |
| **PA8** | D7（CN9）| **MCO1（8MHz出力）** | **CLKIN** | STM32→ADC |
| PCx（任意）| 任意のGPIO | リセット/同期 | **/SYNC-RESET** | STM32→ADC |

---

## ② L76K GPS HAT — UART + 1PPS

| STM32ポート | Arduinoピン | 信号 | L76Kピン | 向き |
|---|---|---|---|---|
| **PA0** | A0（CN8）| TIM2_CH1 入力キャプチャ | **PPS** | GPS→STM32 |
| **PA2** | D1（CN9）| USART2_TX | **RX** | STM32→GPS |
| **PA3** | D0（CN9）| USART2_RX | **TX** | GPS→STM32 |

---

## ③ ESP32 — UART（フェーザ結果送信）

| STM32ポート | Arduinoピン | 信号 | ESP32ピン | 向き |
|---|---|---|---|---|
| **PA9** | D8（CN5）| USART1_TX | **RX** | STM32→ESP32 |
| **PA10** | D2（CN9）| USART1_RX | **TX** | ESP32→STM32 |

---

## ④ 電源・グランド（CN6 電源コネクタ）

| Nucleoピン | コネクタ | レール | つなぐ先 |
|---|---|---|---|
| **3V3** | CN6-4 | +3.3V_D | ADS131M02 **DVDD** / L76K **VCC** |
| **5V** | CN6-5 | +5V | ESP32 5V / R1SE-0505入力 / L76K(5V可) |
| **GND** | CN6-6,7 | DGND | ADC DGND / ESP32 GND / L76K GND（共通グランド）|

---

## 接続全体図（STM32視点）

```
                        NUCLEO-F446RE
                     ┌──────────────────┐
  ADS131M02 ◄────────┤ PA5(D13) SCLK     │
  (ADC, U2)  ────────┤ PA6(D12) MISO◄DOUT│
             ◄───────┤ PA7(D11) MOSI     │
             ◄───────┤ PA4(A2)  /CS      │
             ───────►┤ PB0(A3)  /DRDY    │
             ◄───────┤ PA8(D7)  MCO1 8MHz│
                     │                   │
  L76K GPS   ───────►┤ PA0(A0)  PPS      │
             ◄───────┤ PA2(D1)  USART2_TX│
             ───────►┤ PA3(D0)  USART2_RX│
                     │                   │
  ESP32      ◄───────┤ PA9(D8)  USART1_TX│
             ───────►┤ PA10(D2) USART1_RX│
                     │                   │
  3.3V/5V/GND◄───────┤ CN6 電源          │
                     └──────────────────┘
  ◄ = STM32が出力 / ► = STM32が入力
```

---

## 重要な注意点

1. **AMC3330（U1）はSTM32に直接つながない**
   アナログ信号チェーン（電圧分圧→ADC）の途中にあり、STM32が電圧を読むのは ADS131M02 経由。

2. **PA2/PA3（USART2）はST-LinkのVCPと共用**
   F446REでは PA2/PA3 が基板上で ST-Link 仮想COMポートに接続（SB13/SB14・SB62/SB63）。
   GPSをここに配線する場合は、USBデバッグprintを使わない／別UART（例 USART6=PC6/PC7）に逃がす／
   Morphoヘッダ側のPA2/PA3を直接使う、のいずれかを検討。

3. **PA5 は基板上のユーザLED（LD2）と共用**
   SPI動作に支障はないが、通信中にLEDがチラつく。

4. **PA8（MCO1）は要設定**
   ADCのCLKIN用8MHzは、STM32の MCO1出力を HSE由来8MHz で出す設定（CubeMX等）が必要。

5. **グランドは共通＋ADC直下で1点接続**
   DGND（Nucleo GND・ESP32・GPS）と AGND（ADCアナログ系）は、ADS131M02の直下で1点接続する（§20）。

---

## 参考：使用するSTM32ペリフェラル

| ペリフェラル | 用途 | ピン |
|---|---|---|
| SPI1 | ADCとの通信（マスタ）| PA5/PA6/PA7 + PA4(CS) |
| EXTI（PB0）| ADC /DRDY 割込 | PB0 |
| MCO1 | ADC CLKIN 8MHz供給 | PA8 |
| TIM2_CH1 | GPS PPS 入力キャプチャ | PA0 |
| USART2 | GPS通信 | PA2/PA3 |
| USART1 | ESP32通信 | PA9/PA10 |

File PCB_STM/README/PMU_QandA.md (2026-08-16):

# 単相PMU 試作機 Q&A 集

`PMU_Specification.md` の内容についての疑問とその回答をまとめたもの。
回路の各要素（電圧/電流フロントエンド、AAF、VCM、グランド等）の意味と役割の解説。

> **注意（v2.0変更）**：本Q&Aはv1.0（電流センサ=ZMCT103C）時点の解説。
> 仕様書はv2.0で**電流センサを シャント抵抗＋AMC3302 に変更**し、
> 負担抵抗(Rb)・Vcmバイアス(Rcm)・VCM基準回路は**廃止**された。
> 以下の Q3・Q6・Q7・Q11・Q12（ZMCT103C関連）と Q2（VCM）は**歴史的経緯**として残す。
> AAF・AGND・スター接地・デカップリング・絶縁アンプの概念解説は v2.0でも有効。

---

## Q1. 電圧タップとは？

商用100Vの電圧を測定するために **L線（ライブ線）から電圧を分岐して取り出す接続点**。

```
L ─[F]─[SW]─●─[ZMCT103C 1本貫通]─●───→ 負荷へ(L)
            │
       (電圧タップ) ← ここ
            │
       分圧(510k×3+10k) → AMC3330 → AAF → ADS131M02 ch0
N ──────────●──────────────────────────→ 負荷へ(N)
```

- 負荷へ電力を流す主線路を切らずに、その電位を高インピーダンスの分圧回路で覗き見るための分岐点。
- タップ点から **L–N間の電圧** を分圧回路（上側510k×3、下側10k、分圧比≈1/153）に渡し、
  141Vpk → 約0.92Vpk に降圧して AMC3330（絶縁アンプ）へ入力する。
- 電流が主目的の ZMCT103C（電流タップに相当）と対になる概念。

---

## Q2. Vcm とは？

**Vcm = Common-mode Voltage（コモンモード電圧 / 中点バイアス電圧）**。
約 **1.65V（AVDD/2 = 3.3V÷2）** に設定された基準電位。

- ADCは0〜3.3Vの片電源で動くため、±にスイングする交流（バイポーラ信号）の
  中心を電源の真ん中（1.65V）に持ち上げる必要がある。これが中点バイアス。
- **電流ch**：ZMCT103C二次出力にはDCオフセットがないので、自前でVcmを与える必要がある。
  10kΩ×2分圧＋10µFバイパスで生成（オペアンプ不要）。
- **電圧ch**：AMC3330が出力コモンモード（VDD2/2≈1.65V）を内部生成するため外付け不要。

| 項目 | 内容 |
|---|---|
| Vcm | コモンモード基準電圧 ≈ 1.65V = AVDD/2 |
| 目的 | バイポーラ信号を片電源ADCの入力範囲の中央に載せる |
| 生成 | 10kΩ×2分圧 ＋ 10µFバイパス |
| 使う所 | 電流ch（ZMCT103C入力のバイアス） |

---

## Q3. T1.S1 とは？

**T1（電流センサ ZMCT103C）の二次側端子のうちの片方**。

| 表記 | 意味 |
|---|---|
| T1 | 部品記号。電流トランス ZMCT103C |
| S1 | Secondary 1 = 二次巻線の端子①（もう片方は S2） |
| PRI | Primary = 一次側（L_NODEの電線を1本貫通＝一次1回巻き） |

- 一次：L線の電流が流れる電線を ZMCT103C のコアに1本貫通（一次巻数=1）。
- 二次：巻数比1000:1で誘起された電流が S1〜S2 間に出る。
- S1–S2間に負担抵抗 Rb=68Ω を入れて電流→電圧変換し、ADCの AIN1P/AIN1N へ。
- S1・S2はそれぞれ Rcm=10kΩ経由で VCM(≈1.65V) にバイアス。

ネットリスト: `CT_S1 : T1.S1, R7.1, R10.1, R12.1`（同じノードに繋がる端子を列挙）

---

## Q4. AAF とは？

**AAF = Anti-Aliasing Filter（アンチエイリアスフィルタ / 折り返し雑音防止フィルタ）**。
ADCの手前に置くローパスフィルタで、fs/2（ナイキスト周波数）より高い成分を削り、
エイリアシング（折り返し雑音）を防ぐ。

この機種の設計（差動RCフィルタ、パッシブ）:

| 項目 | 値 | 意味 |
|---|----|----|
| 直列R | 1kΩ ×2/ch | 各差動ラインに直列 |
| 差動C（Cdiff）| 47nF | カットオフ fc≈1.7kHz を決める |
| コモンモードC（Ccm）| 1nF ×2 | 同相ノイズ除去（任意）|

- fc ≈ 1/(2π·2kΩ·47nF) ≈ 1.7kHz、fs/2 ≈ 3.9kHz より十分低い。
- **電圧ch・電流chで完全同一**（位相整合のため）。PMUは電圧と電流の位相差を測るので、
  両chのフィルタ群遅延を揃える必要がある。残る群遅延は実測補償。

---

## Q5. ADCの入力割り当て（AIN0/AIN1）は？

**ch0とch1を間違えやすいので注意。**

| ADC入力 | 入れるもの | 信号 |
|---|---|---|
| **AIN0P / AIN0N**（ch0）| AMC3330 の OUTP / OUTN | 電圧 |
| **AIN1P / AIN1N**（ch1）| ZMCT103C の S1 / S2 | 電流 |

注意点:
- 直結ではなく、必ず **AAF（1kΩ直列＋47nF差動）を経由**して入力する。
- **N_NODE はADCに入れない**。N_NODEは危険側（AC100V側）にあり、AMC3330の入力 U1.INN に行くだけ。
  ADC（安全側）が見るのは絶縁後の AMC3330 出力 OUTP/OUTN のみ。
- 電流側も S1/S2 を N_NODE には繋がず、二次は S1–S2間で完結。

---

## Q6. ZMCT103C は入力と出力が1つずつ？

いいえ。**二次側（出力）は必ず2端子（S1・S2）**ある（トランス巻線は両端のある線のため）。

| 側 | 端子 | 内容 |
|----|---|---|
| 一次側（PRI）| 貫通電線 | 測定対象のL線をコアの穴に1本通すだけ（巻数1）。これが「入力」 |
| 二次側 | S1 と S2 の2本 | 1000:1で誘起された電流が出る。これが「出力」 |

- 「1つに見える」のは一次側（負荷へ行くL線をコアに1回通すだけ＝通過電線）。CT自身の端子ではない。
- 二次のS1→負担抵抗(68Ω)→S2 という閉ループを作って初めて電流が測れる。1端子では経路ができない。

---

## Q7. ZMCTを貫通させた線は何につなぐ？

**特別な配線ではなく、負荷へ電流を流すL線そのもの**。CTのコアに通すだけ。

```
L ●─[F1]─[SW1]─●(L_NODE)──→（ZMCT103Cのコアを1本貫通）──→ 負荷のL端子
N ●────────────●(N_NODE)─────────────────────────────→ 負荷のN端子
```

- 線の片端：L_NODE側（F1・SW1を通ってきたAC100VのL）
- 線のもう片端：負荷（測定対象機器）のL端子
- **必ずLかNの片方だけを通す**（両方通すと電流が打ち消し合いゼロになる）。
- 貫通線（一次）とS1/S2（二次）は磁気結合のみで電気的に絶縁されている。

---

## Q8. 負荷は必要？

**はい。電流を測る以上、電流を流す負荷が必要。**

- 負荷をつなぐ → L線に電流が流れる → CTが検出 → 電流測定できる。
- 負荷なし（開放）→ 電流ゼロ → 出力もゼロ → 何も測れない。
- 電圧は負荷がなくても測れる（L-N間に電圧はかかっている）。
- 試運転は低ワット抵抗負荷から段階的に。**最大10A（>10A負荷は避ける）**。

---

## Q9. 試験につなぐ負荷（測定対象）はどのくらい？

コンセント先につなぐ実際の負荷の話。仕様書推奨は「初回は低ワット抵抗負荷から」。

| 負荷 | 例 | 電流の目安 | コメント |
|---|----|---|---|
| 白熱電球 | 40W / 60W | 0.4〜0.6A | 最初の試験に最適。純抵抗・力率≈1で波形がきれい |
| ヒーター | 500W〜1kW | 5〜10A | 純抵抗。大きめ電流を見たいとき |
| セメント抵抗 | 100Ω/100W等 | 1A前後 | 実験用に値を選べる |

- 最大10A（1000W）以内を厳守。`I = P / 100V` で見積もる。
- スイッチング電源・モーター・LED電球は力率が低く波形が歪むので、基本動作確認には不向き。

---

## Q10. 分圧後の線とN_nodeをつなぐ10kΩ（R4/Rlo）の役割は？

分圧回路の **下側抵抗（Rlo）**。上側510kΩ×3と組んで100Vを縮小する。

```
L_NODE─[510k]─[510k]─[510k]─●(VDIV_TAP)──► U1.INP
        (上側 Rhi=1.53MΩ)    │
                          [R4 10k]  ← これ（下側 Rlo）
                              │
N_NODE────────────────────────●──────────► U1.INN
```

役割:
1. **分圧比を決める**：10k/(1.53M+10k) ≈ 1/153 → 141Vpk → 約0.92Vpk（AMC3330の±1V内）。
   この値が電圧chのゲインを決めるので高精度品（0.1%/≤25ppm）が必須。
2. **N_NODE（N相）を基準にする**：下端をN_NODEにつなぐことで「L–N間電圧」を測る。N基準への戻り経路。
3. 上側を510k×3に分けるのは耐圧確保（各≈33V分担）。

---

## Q11. 電流チャネルのバイアス抵抗（Rcm = 10kΩ ×2 / R10・R11）は？

S1・S2をそれぞれ VCM(≈1.65V) にぶら下げ、**中点バイアスを与える**抵抗。

```
T1.S1●─┬──────────[R12 1k]─┬─► AIN1P
       [R7 68Ω]            │
T1.S2●─┴──────────[R13 1k]─┴─► AIN1N
   S1─[R10 10k]─●(VCM)●─[R11 10k]─S2   ← R10・R11 がバイアス抵抗
```

- ZMCT103C二次出力はDC基準を持たないため、S1・S2の直流動作点を1.65Vに固定する。
- 値の理由：**Rb(68Ω) ≪ Rcm(10k)** なので、二次電流はほぼ全部Rb(68Ω)を流れ、
  バイアスはするが電流→電圧変換（測定精度）には影響しない。
- 電圧ch側（AMC3330）は内部でコモンモード生成するため不要。電流ch特有の部品。

---

## Q12. 負担抵抗（Rb / R7 = 68Ω）の役割は？

CTの二次電流を「電圧」に変換するための抵抗（ADCは電圧しか測れないため）。

| 役割 | 内容 |
|---|---|
| ① 電流→電圧変換 | 二次電流を電圧に（V=I×R）。一次10A→二次14.1mApk×68Ω≈0.96Vpk（FSR ±1.2V内）|
| ② ゲイン設定 | 抵抗値で測定レンジを決める |
| ③ 二次開放の防止 | CT二次を常に閉ループにし、開放時の過電圧・破損を防ぐ |

測定レンジ別のおすすめ:

| 測りたい最大電流 | 推奨Rb | Vpk |
|---|---|-----|
| 〜5A | 120Ω | 約0.85Vpk（小電流を高分解能で）|
| 〜10A | **68Ω**（標準・推奨）| 約0.96Vpk |
| 〜15A | 47Ω | 約1.0Vpk（CT定格に注意・推奨外）|

- 迷ったら68Ω。0.1%・≤25ppmの薄膜抵抗を使用。

---

## Q13. AGND とは？

**AGND = Analog Ground（アナロググランド）**。アナログ信号系の基準電位（0V）。

- デジタル系のノイズをアナログ信号から隔離するため、GNDを2種類に分けている。

| 名称 | 何の基準か |
|---|---|
| AGND | ADCアナログ部・VCM・AAF・アナログ信号の0V |
| DGND | STM32・SPI・デジタル回路の0V |

- ルール：**AGNDとDGNDはADS131M02(U2)の直下で1点だけ接続**（スター接地）。
  デジタルノイズ電流がアナログ領域を通らないようにしつつ、基準は共通化する。

---

## Q14. VCMの3.3Vはどこから取る？

**アナログ3.3Vレール（+3.3V_A）** から取る。

```
+3.3V_A─[R8 10k]─●(VCM)─[R9 10k]─AGND   ; VCMに C4 10µF→AGND
```

+3.3V_A の供給源は2択:

| | 供給源 | メリット | デメリット |
|--|---|---|---|
| ①推奨 | R1SE-0505(絶縁DCDC 5V→5V)→LDO→+3.3V_A | 低ノイズ・高精度 | 部品増 |
| ②簡易 | Nucleoの3.3V共用（省略時）| 配線簡単・省部品 | ノイズに弱い |

- 仕様書では「省略可」。まず②で動作確認 → 精度を詰めるとき①に格上げが現実的。
- **VCMの3.3VとADCのAVDDは必ず同じ+3.3V_Aレールから取る**こと。

---

## Q15. 「同じレール」とは？

**レール = 電源ライン（同じ電圧を配る配線）**。同じレールから取る＝
まったく同じ電源配線（同じノード）から枝分かれして電気を取ること。

```
            +3.3V_A レール
   電源 ──●──────●──────●──
          │      │      └─→ VCM生成(R8/R9)
          │      └────────→ ADS131M02 AVDD
          └───────────────→ AMC3330 VDD2
```

- VCMは「AVDDのちょうど半分（AVDD/2）」を作るのが目的。
- 同じレールなら電源が3.3V→3.32Vに揺れてもAVDDとVCMが同じ割合で動き、
  「VCM=AVDDの真ん中」の関係が保たれ測定誤差が出ない。
- 別レールだとVCMだけずれてオフセット誤差になる。

---

## Q16. C6・C7（各1nF）の役割は？

電流ch ADC入力 AIN1P・AIN1N から AGND へつなぐ、**AAFのコモンモード用コンデンサ**。

```
──[R12 1k]──┬──────► AIN1P
            ├──[C6 1nF]──AGND
          [C5 47nF]
            ├──[C7 1nF]──AGND
──[R13 1k]──┴──────► AIN1N
```

| 種類 | 部品 | 接続 | 落とすノイズ |
|---|---|---|---|
| 差動C | C5（47nF）| AIN1P–AIN1N 間 | 差動（ノーマルモード）= 信号成分の高域 |
| コモンモードC | **C6・C7（1nF×2）** | 各ライン→AGND | コモンモード（同相）= 両線共通のノイズ |

- C6・C7は両線共通に乗るノイズ（EMI・電源由来）をADC手前でAGNDへ逃がす。
- **必ず両線に同じ値（1nF・C0G）で対称配置**。非対称だとコモンモード→差動変換でノイズ化する。
- 仕様書上は「任意」（ノイズ対策の追加オプション、省略可）。
- 電圧ch側にも対の C2・C3（1nF×2→AGND）がある。

---

## Q17. C6・C7は両線にそれぞれつなぐ？

**はい。AIN1PとAIN1Nの両線に1個ずつ（C6・C7、計2個）。** 各線が独立にAGNDへつながる。

```
──[R12 1k]──┬──────► AIN1P
          [C6 1nF]──AGND      ← C6: AIN1P から AGND へ1個
──[R13 1k]──┬──────► AIN1N
          [C7 1nF]──AGND      ← C7: AIN1N から AGND へ1個
```

差動C（C5）との違い:

| 部品 | つなぎ方 | 個数 |
|---|---|---|
| C5（47nF）差動C | AIN1PとAIN1Nの線間に橋渡し | 1個 |
| C6・C7（1nF）コモンモードC | 各線からそれぞれAGNDへ | 2個 |

- 片方だけだと左右が非対称になり、コモンモードノイズが差動信号に化けるため、必ず両線に同値で。

---
---

# ── 電源設計編（v3.x：測定線からの自給電） ──

> **テーマ**：測定対象の商用100Vから装置自身に給電（セルフパワード）しつつ、計測精度(TVE)を落とさない電源設計。
> **最終構成**：**HLK-10M05（絶縁AC-DC 5V/2A）＋ πフィルタ ＋ 低ノイズLDO(ADP7142)**。
> 分岐は**シャント Rsh 上流(L_NODE)**、絶縁は**HLK＋AMC3330/3302の二重**、安全側フローティング。
> 関連：`PMU_Specification.md`（§1・§3・§11・§15・§19・§20 に反映済み）。

---

## Q18. 制御側の電源を、測定する商用電源から給電できる？

**A. できる。「絶縁」して「シャントより上流」から取ること。**

- 安全側(STM32/ESP32/GPS/ADC)と危険側(AC100V)は AMC3330/AMC3302 の強化絶縁で分離済み。絶縁電源で+5Vを作れば安全側はフローティング維持。
- 必須2条件：①絶縁型であること（L線から非絶縁でDC生成は禁止）②シャント Rsh より上流(L_NODE)で分岐（給電電流をRshに流さない＝電流測定に誤差ゼロ）。

```
 L ─[F1]─[SW1]─●(L_NODE)──[Rsh]──●(L_LOAD)──→ 負荷L
                 │ ▲(測定電流)
      ┌──[F2]────┘  ○上流分岐：Rshを通らない＝誤差ゼロ
   [絶縁電源]         ×下流分岐：制御電流がRshに乗って誤差
 N ───●(N_NODE)
```

---

## Q19. 商用由来の電源をADCの安全側電源に使ってもいい？

**A. 問題なし。ADCは丸ごと安全側。ただしアナログ側はノイズ対策を。**

- ADCの AVDD/DVDD は絶縁境界の安全側。絶縁電源由来ならOK。
- 注意はノイズだけ：AVDDは低ノイズ化(フィルタ＋LDO)、AGND-DGNDはADC直下1点、ESP32用に5Vバルク。

---

## Q20. トランス＋リニア電源 と HLK(絶縁AC-DCモジュール)、どっち？

**A. 精度差は小さい。入手性・部品点数で HLK-10M05 を採用。**

- 振幅精度を決めるのは**ADC内蔵Vref(1.2V)**で5Vレールではない。5Vノイズは PSRR 経由のみ。
- TVEを支配するのは電源方式でなく**シャントTCR/許容差・分圧・AMC/AAF位相・GPS/PPSタイミング**。
- トランス＋7805は低ノイズだが発熱＋トランス入手難（9V/1A級基板トランスは国内実質ディスコン）。
- → アナログはLDOで再生成するのでHLKでも実用TVE差は小さい、と判断。

---

## Q21. HLKの −Vout はアナログGNDにつなぐ？

**A. いいえ。まず DGND につなぐ。AGNDとはADC直下で1点だけ結合。**

- HLKの+5Vは ESP32(WiFiバースト)等の騒がしい系に給電 → 戻りは DGND。
- −VoutをAGND直結すると ESP32電流がアナロググラウンドを汚しTVE悪化。
- 正：**+Vout→+5V、−Vout→DGND**、AGNDはADC(U2)直下で1点結合。

---

## Q22. NUCLEO＋ESP32＋GPS HAT の給電に HLK-5M05(1A)で足りる？

**A. 足りない。HLK-10M05(2A)を推奨。**

| デバイス | 平均 | ピーク |
|---|:---:|:---:|
| NUCLEO-F446RE | ~120mA | ~150mA |
| ESP32 | ~120mA | ~500mA(瞬時~600mA) |
| L76K GPS HAT | ~40mA | ~50mA |
| アナログ系(ADC/AMC+LDO) | ~50mA | ~80mA |
| **合計** | **~330mA** | **~0.8A** |

- 5M05=1Aはピークに肉薄＋温度ディレーティング＋過渡応答が悪い → 実質不足。10M05(2A)で2倍余裕。

---

## Q23. 正直トランスで作った方が精度いいよね？

**A. 原理的には低ノイズ。ただしこの設計では差が小さい。**

- 理由：①振幅精度はVref依存 ②アナログはLDOで再生成しバッファ ③ΔΣ＋AAFが帯域外ノイズを除去。
- より効く一手は電源方式より「アナログ電源の分離」「シャント/分圧の精度・校正」。

---

## Q24. 7805 とは？（※最終的にHLK採用で不要）

- 入力を安定+5Vにする三端子リニアレギュレータ。3ピン(IN/GND/OUT)。低ノイズだが**余剰電圧を熱で捨てる**((入力-5V)×電流)。3W級は放熱器必須、熱源はシャント/分圧から離す(熱ドリフト対策)。
- トランス選定は 100V:9V/8〜10VA/強化絶縁だが、9V/1A級基板トランスは国内実質ディスコン(豊澄HT系生産終了、秋月はHT-1205=0.5A止まり)。→ **トランス+7805案は破棄、HLK-10M05に決定**。

---

## Q25. アナログ3.3Vは R1SE(絶縁DC-DC) と 三端子(LDO) どっち？

**A. LDO一段が良い（R1SEは廃止）。**

- R1SEは安全絶縁の役ではない(それはHLK/AMCが担当)。役割はノイズ絶縁のみ。
- R1SE自身がSWノイズ源で結局LDOで掃除が要る → 最初からLDO一段が素直・低ノイズ・部品減。
- LDOのPSRR(DC〜系統高調波で60〜80dB)＋ΔΣ/AAFで十分クリーン。
- フォールバック：ESP32グラウンド雑音が実測で問題化した時のみR1SE復活でアナログGND島化。

---

## Q26. 仕様書の全体点検（見つけて反映した修正）

1. **シャント値の矛盾**：§11だけ「3mΩ」→他は1.5mΩ → **1.5mΩ/≥1Wに統一**。
2. **有効電力の係数**：DFT `X=(2/N)Σ…` は|X|=ピーク振幅 → **RMS化(=|X|/√2)、P=Vrms·Irms·cosφ**（C37.118は振幅=RMS慣例）。
3. **シャントTCR**：§5(≤75ppm)/§11(≤25ppm) → **≤25ppmに統一**。
4. **シャント電力定格** → **≥1Wに統一**。
5. **§10ピン表に ADC /SYNC-RESET(PC0)** 追加。
- 確認済で問題なし：AMC3330ゲイン=2.0(DS一致)、AMC3302=41、AAF fc≈1.7kHz、fDATA=7812.5SPS。

---

## Q27. HLK周りのフィルタ用コンデンサのつなぎ方は？

**A. どのCも「片脚=電源レール／もう片脚=DGND」。直列に入るのは L1 だけ。**

```
 HLK +Vout ●──┬──[ L1 ]──┬────────┬────────┬──→ 各負荷
             (+5V)      (+5V_F)   │        │
              │  │       │        │        │
            C43 C45     C46      C44      C16+C17
           100µF 10µF   10µF   470-1000µF 10µF+0.1µF
           (電解)(ｾﾗ)    (ｾﾗ)   (ESP32直近) (LDO入力)
              │  │       │        │        │
 HLK −Vout ●──┴──┴───────┴────────┴────────┴──● DGND
              ↑π入力側    ↑π出力側
```

- π型フィルタ = **C(入力)‑L‑C(出力)**。C43/C45=π入力、L1=直列、C46=π出力。
- ルール：①全部レール↔DGND ②電解は極性あり(−をDGND) ③大容量電解＋小容量セラミック並列 ④C44はESP32直近・C16/C17はLDO直近。
- ノイズは「Cで落とす→Lで堰き止め→LDOで磨く」の3段でADC基準まで届かせない。

---

## Q28. ESP32付近に既に100u/10u/0.1uFがある。470uも追加？

**A. 4個目を必ず足す必要はない。狙いは「ESP32近くのバルク合計を470µF級」にすること。**

- 100µFと470µFは同じ担当(低周波バルク)。0.1/10µFは高〜中周波担当なので残す。
- 選択A：**100µF→470µFに大型化**(推奨)。選択B：100µFに470µF並列(余裕重視)。
- まず今のままテスト → 送信でリセット/+5Vがガクッと落ちるなら大型化。

---

## Q29. フェライトビーズ(L1)のおすすめは？「470-1000」の意味は？

- **「470-1000」＝470µF〜1000µFの範囲で1個を選ぶ**意味(2個ではない)。まず470µF、足りなければ1000µF。
- **L1は全電流(連続~1A/ピーク~2A)が流れる** → **電源用(大電流)ビーズ**(信号用0603はNG)。
  - 基準：**1206以上／定格≥2A(できれば3A)／DCR≤50mΩ／100〜600Ω@100MHz**。
  - 例：村田 BLM31シリーズ、TDK MPZ2012シリーズ の高電流品。
- ビーズは高周波ハッシュ用。リプル(数十〜数百kHz)まで抑えたいなら小型パワーインダクタ4.7〜10µH/≥2Aに格上げ(最後はLDOが除去するのでまずビーズで十分)。

---

## Q30. アナログLDOは ADP7174 シリーズなら何でもいい？

**A. ADP7174 は存在しない(型番違い)。ADP7142 か ADP7118 の 3.3V固定品を選ぶ。**

- 近い実在品：ADP7142(40V/200mA)、ADP7118(20V/200mA)、ADP7104(500mA) 等の低ノイズCMOS LDO。
- 「シリーズなら何でも」ではなく：①出力3.3V固定品(末尾 -3.3) ②出力電流が足りる(本用途~80mA→200mA品で十分)。
- おすすめ：**ADP7118AUJZ-3.3** または **ADP7142ACPZ-3.3 / AUJZ-3.3**。

---

## Q31. ADP7142 のピンは何につなぐ？（TSOT-23-5 / 3.3V固定）

| ピン | 名前 | つなぐ先 | 補足 |
|:---:|---|---|---|
| 1 | VIN | **+5V_F**(πフィルタ後) | 入力C **≥2.2µF**(C16 10µF)をGNDへ |
| 2 | GND | **AGND** | このLDOはアナログ系電源 |
| 3 | EN | **VIN(=+5V_F)に直結**(常時ON) | 開放不可。制御したいならGPIOへ |
| 4 | SENSE/ADJ | **VOUT(5)に接続**(負荷点) | 固定品は出力へ繋ぐだけ |
| 5 | VOUT | **+3.3V_A**(ADC AVDD/AMC VDD2) | 出力C **≥2.2µF** をGNDへ |

- グラウンド：入力Cのコールド→DGND、GNDピン・出力Cのコールド→AGND。AGND-DGNDはADC直下1点。
- **【要修正】出力C18=1µFはADP7142要件(≥2.2µF)未満** → **2.2µF以上(例2.2〜10µF)に変更**。

---

## Q32. SS（ソフトスタート）ピンはどうする？

**A. 「開放(未接続)」でOK。GNDには絶対繋がない。もしくはSSピンの無いTSOT品を選ぶ。**

| パッケージ | SSピン | 対応 |
|---|:---:|---|
| TSOT-23-5(5ピン) | 無い | 何もしない(起動~380µs固定)＝おすすめ |
| LFCSP-8(8ピン) | 有る | **開放→380µs**／ゆっくり起動は SS↔GND間にC(数nF〜100nF)／**GND直結は禁止** |

- アナログ系は突入電流が小さく標準380µsで十分。特別な理由がなければコンデンサ不要。

---

## 最終電源構成（まとめ）

```
測定線 L_NODE ─[F2 0.5A]─ HLK-10M05(AC100V→DC5V 2A) ═絶縁═ +5V
   └ 分岐はシャント上流(電流測定に影響なし)          │
                                                    ├─[C43/C45]─[L1 ﾋﾞｰｽﾞ≥2A]─[C46]─ +5V_F
   +5V_F ─┬─→ Nucleo(E5V, JP5=E5V)
          ├─→ ESP32(+5V, バルク470µF級を直近)
          └─→ ADP7142(3.3V固定LDO) ─ +3.3V_A ─→ ADC AVDD / AMC3330・3302 VDD2
 −Vout=DGND(安全側基準/フローティング)   AGND-DGNDはADC直下で1点接続
```

- 絶縁：**HLK(電源)＋AMC3330/3302(信号)** の二重で安全側フローティング。
- ノイズ：**π型フィルタ(C-L-C)＋低ノイズLDO** でHLKのSWノイズをADC基準へ入れない。
- 電流測定：**分岐はシャント Rsh 上流(L_NODE)** で誤差ゼロ。

*(本ログは検討時点の結論。最終値は各データシートで確認のこと。)*

---
---

# ── テスト負荷・派生版・KiCad実装編 ──

> 仕様書仕上げ〜基板実装の検討ログ。テスト負荷の発熱、電圧のみ派生版(V2)、KiCadのグランド塗り。

---

## Q33. 負荷抵抗10Ωを100Vに直列/直結すると発熱は大丈夫？

**A. ダメ。1000W発熱する。**

- `I = V/R = 100/10 = 10A`、`P = V²/R = 100²/10 = 1000W`。
- 10Ωは小型電気ヒーター並みの発熱 → 普通の抵抗器では焼損・発火。しかも10Aは測定レンジ上限ぎりぎり。
- 発熱は抵抗値だけで決まる（P=V²/R）。小さい抵抗ほど大電流＝大発熱。

| 抵抗 | 電流 | 発熱 | 判定 |
|---|:---:|:---:|---|
| 10Ω | 10A | 1000W | ❌ 論外 |
| 100Ω | 1A | 100W | ○（電球100W相当）|
| 470Ω | 0.21A | 21W | ◎ 初回向き |
| 1kΩ | 0.1A | 10W | ◎ 最安全 |

- ※シャント(1.5mΩ)は「負荷」ではなくセンス抵抗（10Aでも0.15W）。混同しない。

---

## Q34. 470Ωならできる？

**A. できる。470Ω/50W品でOK（発熱21W、余裕2.4倍）。ただし熱くはなる。**

- `I=100/470≈0.21A`、`P≈21W` → **50W定格の無誘導電力抵抗**で安全（§14想定どおり）。
- 扱い：開放空間/放熱器で使用、可燃物に触れさせない、素手厳禁（表面100〜150℃）。定格は発熱の2倍以上。
- 測定上の注意：0.21Aだと電流chの信号は **ADC FSRの約1.5%** と小さい（シャント両端≈0.45mVpk→×41≈18.5mVpk）。
  - ◎ 既知抵抗の振幅校正基準／力率≈1の位相校正。△ 電流ダイナミックレンジ確認には不向き。
  - 強い電流信号が欲しいときは 100W電球(≈1A) の方がSNR良好。

---

## Q35. 電流計測を削除した Version 2（電圧のみ）仕様書

**A. `PMU_Specification_V2_VoltageOnly.md` を作成。**

- **削除**：シャント Rsh／AMC3302(U5)／電流ch AAF(R12/R13/C5-C7)／ADC ch1／電力量(P/Q/力率)／電流校正／電流用テスト負荷。
- **ADC**：ADS131M02 の **ch0のみ**使用（1ch版 ADS131M01 でも可）。
- **出力**：Vmag(RMS)/Vang/f/ROCOF のみ。
- **引き継ぎ**：電圧FE(分圧+AMC3330)、AAF、GPS、**自給電電源(HLK-10M05＋πフィルタ＋ADP7142)**、C37.118。
- **楽になった点**：①シャント無しで自給電の分岐位置が自由（「シャント上流」制約消滅）②電圧のみなので**負荷不要**（開放でも測れる）。

---

## Q36. KiCad：GNDピンを接続しないと、べたGNDに自動で繋がる？

**A. 繋がらない。「接続しない＝どこにも繋がっていない（ERCエラー）」。**

- ネットは回路図で明示的に繋いだ所しか接続されない。べたGNDは**GNDネットのパッドだけ**を繋ぎ、他ネット/無所属パッドはクリアランスで避ける。
- 例：抵抗のマイナス側を何も繋がない → 浮く（フローティング）。近くにベタがあっても繋がらない。
- 唯一の「自動」＝**電源ポートシンボル（GND/+3.3V等）は同名なら配線なしで結合**。ただしピンにそのシンボルを"置く"必要はある。
- 対策：GNDにしたいピンには必ずGNDシンボル/配線を付け、ERC＋DRC(未接続チェック)で浮きゼロを確認。

---

## Q37. べたGNDはアナログGNDとデジタルGNDどっち？領域で塗り分ける？

**A. 「全面どちらか一色」ではない。分けなくてもいい（統一GND1枚が推奨）。**

- 一番おすすめ：**ベタを分割せず統一GND1枚**にして、**部品配置**でアナログ/デジタルを分離（ΔΣ ADCの定石。2層試作で事故が少ない）。
- 仕様書どおり分割する場合：**その場所の下の回路のGND**を塗る（アナログ部下=AGND、デジタル部下=DGND）、ADC直下で1点接続。
- 分割の落とし穴：**信号が分割線をまたぐと戻り電流が遠回りしてかえってノイズ源**。またぎ配線ゼロを徹底できないなら分割しない方がマシ。
- **判定**：分けなくてもよい（分けてはいけない訳ではない）。迷うなら統一GND1枚。

---

## Q38. べたGNDをDGNDで塗りつぶせばいい？

**A. 塗るネットは1つでよいが、旧AGNDピンも同じネットに繋ぎ替えること。**

- 全面をDGNDで塗るなら、**AGNDピン(ADC AVDD戻り・AMC GND2・LDO出力C・分圧Rlo戻り等)も全部そのネットに入れる**。別ネットのままだとAGNDピンがベタから浮く（島になる）。
- 一番きれい：回路図で **AGND/DGNDを「GND」1ネットに統一**して塗る。名前はGNDに一本化推奨。

---

## Q39. アナログGNDが（DGNDベタから）浮いてても、全AGNDを繋いでDGNDと1点結線すれば大丈夫では？

**A. 正しい。それが正しい分割グランド（スター接地）。AGNDは浮いていない。**

- 「浮く」のは **AGNDに専用の銅を与えず、DGNDベタが運んでくれると誤解した時**だけ。
- **AGND専用の銅（配線 or 別ゾーン）で全AGNDピンを繋ぎ、DGNDと1点で結線**すれば問題なし（DGNDベタが運ぶのではなく、AGND導体を自分で用意する）。
- KiCad実装：AGNDゾーン/配線＋**AGND–DGNDを1点だけ**結線（別ネット直結はDRCがショート判定するので**net-tie**等を使う）。信号は分割線をまたがない。

| やり方 | 可否 |
|---|---|
| AGND専用銅＋DGNDと1点結線 | ✅ 分割の定石 |
| DGNDだけ塗りAGNDに銅を与えない | ❌ AGND浮く |
| 全部GND1ネットに統一 | ✅ 一番簡単 |

---

## Q40. net-tieじゃなくて0Ω抵抗でもいい？

**A. OK。0Ω抵抗はAGND-DGND 1点結線の定番。**

| | 0Ω抵抗 | net-tie |
|---|---|---|
| ネット分離(DRC OK) | ✅(2ネットを橋渡し) | ✅ |
| BOM部品 | 要1個 | 不要(銅のみ) |
| 追加インピーダンス | ≒0 | ゼロ |
| 融通 | ◎ 後でﾋﾞｰｽﾞ/DNPに差替可 | 固定 |

- KiCad的に0Ω抵抗は「2パッドが別ネットの実部品」なのでDRCのショートエラーは出ない。
- コツ：**ADC直下に1個だけ**置き、**AGND-DGND接続はこの0Ωだけ**にする。0402〜0805で十分。
- 注意：ΔΣ ADCでは AGND-DGND間は **0Ω(実質直結)推奨**。フェライトビーズ常設は避ける（両GND間電圧差が誤差要因）。切り分け用に「まず0Ω、必要時だけビーズ」。

---

*(グランド設計：この規模なら「統一GND1枚＋配置分離」か「分割＋0Ωで1点結線」のどちらでも可。またぎ配線ゼロが守れないなら統一GNDが安全。)*

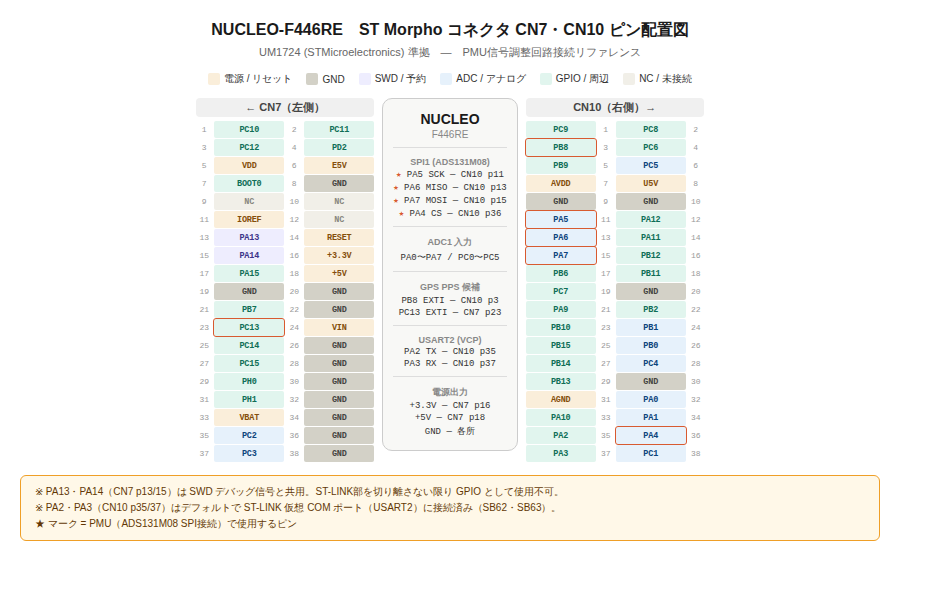
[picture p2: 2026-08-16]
PCB_STM/README/nucleo_f446re_pinout.png

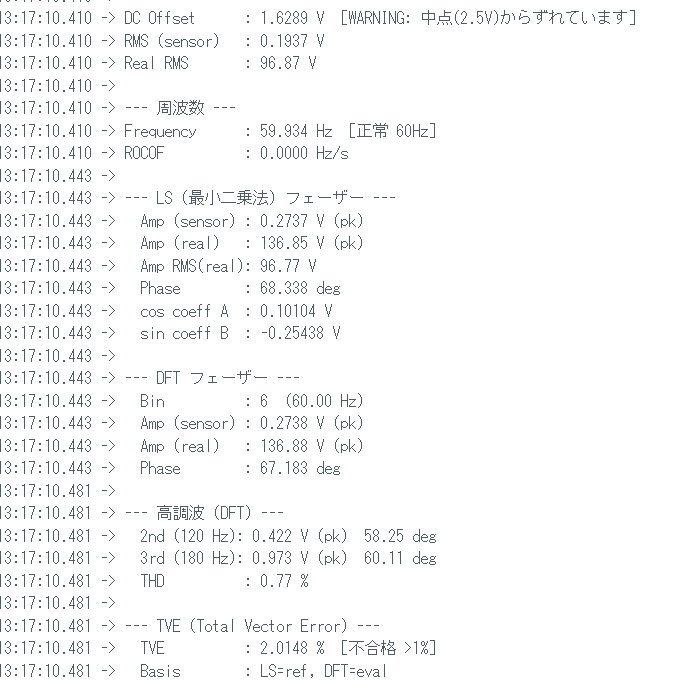
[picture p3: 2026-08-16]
phote/Pasted image 20260602132038.png

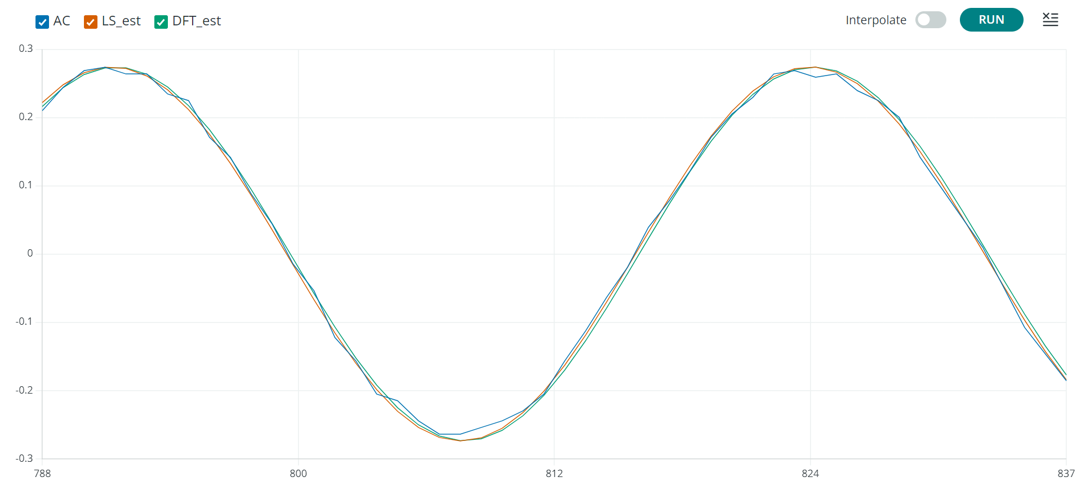
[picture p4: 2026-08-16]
phote/Pasted image 20260602132052.png

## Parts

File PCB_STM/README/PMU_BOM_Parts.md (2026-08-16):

# PMU試作機 受動部品・電源部 発注BOM（型番リスト）

**版**：v3.2（電源を **HLK-10M05＋πフィルタ＋ADP7142 LDO** に更新／R1SE-0505 廃止）

`PMU_Specification.md`（v3.2）§1・§11 の部品リストと §20 ネットリストの部品記号に、具体的なメーカー型番を割り当てたもの。

- 精度が効く抵抗：**Susumu RG2012P 薄膜（±0.1% / ±25ppm/℃ / 0805）** … 日本メーカーで入手性良。
- コンデンサ：**Murata / TDK / Panasonic** 中心。サイズは手はんだしやすい **0805(2012)** 基本。
- 型番は代表例。**発注前に在庫・値・許容差/TCRコード・耐圧を必ず確認**すること。

> **v2.0→v3.2 の主な変更**：
> - 自給電の電源部を「トランス＋7805」→ **絶縁AC-DCモジュール HLK-10M05（5V/2A）** に置換。
> - アナログ3.3Vを「R1SE-0505＋LDO」→ **ADP7142 低ノイズLDO一段** に簡素化（**R1SE-0505・その入出力C(C14/C15/C16/C17旧)廃止**）。
> - **HLK出力に π型フィルタ（C43/C45＋L1＋C46）**、**ESP32直近に大容量バルク C44（470–1000µF）** を追加。
> - **電源分岐ヒューズ F2** を追加。シャント Rsh の TCR を **≤25ppm** に統一（≥1W）。

---

## 1. 抵抗（精度品は Susumu RG2012P：±0.1% / ±25ppm / 0805）

| 値 | 用途 | 部品記号 | 代表型番 | 主要スペック | 推奨購入数 |
|----|---|---|---|---|:---:|
| 510kΩ | 分圧上側（3直列）| R1, R2, R3 | **RG2012P-514-B-T5** | 0.1%/25ppm/0805/150V | 10 |
| 5.1kΩ | 分圧下側（Rlo）| R4 | **RG2012P-512-B-T5** | 0.1%/25ppm/0805（5.11kΩ/E96可）| 5 |
| 1kΩ | AAF直列（両ch同一）| R5, R6, R12, R13 | **RG2012P-102-B-T5** | 0.1%/25ppm/0805 | 10 |
| **1.5mΩ シャント Rsh** | 電流センス（L線直列）| Rsh | **WSK2512R0015◯EA**（Vishay, 4端子ケルビン）| ±1%/≤75ppm(標準)/1W/2512 | 3 |

> - 1kΩ(AAF)と分圧抵抗は**同一型番・同一ロットで揃える**（両ch整合・位相精度のため）。
> - 510kΩは1本あたり33V分担、RG2012(0805)定格150Vで余裕あり。
> - **シャントは4端子(ケルビン)必須**。仕様書は **≤25ppm** 目標だが標準WSKは≤75ppm。
>   **≤25ppmを厳守するなら** Susumu **KRL2512** 系や Vishay 金属箔（**WSBM/Foil**）、Isabellenhütte 等の高TCR等級へ格上げ（要確認）。
> - Rshの発熱は10Aで0.15W → 1W品で余裕。

---

## 2. コンデンサ

| 値 | 用途 | 部品記号 | 代表型番 | メーカー | 主要スペック | 推奨購入数 |
|----|---|---|---|---|---|:---:|
| 0.1µF | 各IC電源デカップリング | C9,C11,C17,C19,C21,C29,C33,C34,C26 ほか | **GRM21BR61H104KA01L**（X5R）／代替 GRM21BR71H104KA01L（X7R）| Murata | **X5R**（X7R可）/**50V**/0805 | 30 |
| 1µF | ADC AVDD/DVDD/CAP・AMC VDD2・DC-DC高圧側 | C8,C10,C12,C20,C28,C30 ほか | **GRM21BR61H105KA12L**（X5R）／代替 GRM21BR71H105KA12L（X7R）| Murata | **X5R**（X7R可）/**50V**/0805 | 25 |
| 10µF | **LDO入出力(C16/C18・各≥2.2µF)**・AVDDバルク・**πフィルタ(C45/C46)** | C16,C18,C25,C45,C46 ほか | **GRM21BR61E106KA73L** | Murata | X5R/25V/0805 | 15 |
| 100µF | **HLK出力バルク(C43)**・5Vバルク(ESP32 C24)| C43, C24 | **EEU-FR1C101** | Panasonic | 低ESR電解/16V/φ6.3 | 5 |
| **470µF** | **ESP32直近バルク（送信ピーク吸収）** | **C44** | **EEU-FR1C471L** | Panasonic | 低ESR電解/16V/φ10 | 3 |
| 47nF | AAF 差動C（Cdiff）| C1, C5 | **C3216C0G1H473J160AA** | TDK | **C0G**/50V/1206 | 10 |
| 1nF | AAF コモンモードC・AMC高圧側 | C2,C3,C6,C7,C31,C33 ほか | **GRM2165C1H102JA01J** | Murata | **C0G**/50V/0805 | 15 |

### 選定の要点
- **0.1µF / 1µF は X5R でよい**（X7R も可）。**X5RとX7Rの差は上限温度のみ（X5R=85℃ / X7R=125℃、容量精度はどちらも±15%）**で、本機はラボ室内・低発熱のため **85℃上限のX5Rで十分**。
  - ★**ただし耐圧は 50V を維持**すること。実効容量減（DCバイアス）は**X5R/X7Rの別よりケースサイズと耐圧で決まる**。X5Rは25V/16V品が多いが、「X5Rだから」と低耐圧を選ぶと実効容量が落ちる。**0805・50V のまま X5R** が正解。
  - dielectricを**X5Rに統一**すれば 0.1µF/1µF/10µF が同系となり発注が簡素化できる（47nF/1nFは別物のC0Gなので対象外）。
- **10µF（LDO入出力 C16/C18）は ADP7142 要件の ≥2.2µF を満たす**。X5R/25V/10µF なら余裕（DCバイアス減も見込んで10µF採用）。
- **47nF / 1nF は必ず C0G/NP0**（AAF特性安定・両ch整合。X7Rは容量変動大でNG）。47nF C0Gは1206。
- **100µF/470µF は低ESRの電解 / ポリマー / タンタル**。ESP32のWiFi突入電流とHLK出力平滑用。
- **C44(470µF)は ESP32のできるだけ近く** に配置（バーストはL1を通れず近接バルクから供給）。
- **削除**：4.7µF（旧R1SE-0505入力 C14）、10µF旧R1SE出力用の一部。

### 2.1 セラミック / 電解 の判断根拠（コンデンサ種別の詳細）

> **結論**：**バルク蓄電の 100µF / 470µF（C43・C24・C44）だけが電解（または低ESRポリマー/タンタル）**で、**それ以外の 0.1µF〜10µF・47nF・1nF はすべてセラミック（MLCC）**。判断軸は「①動作周波数と要求ESR/ESL」「②必要容量とサイズ/コスト」「③容量安定性（DCバイアス・温度）」「④極性の有無」の4つ。

#### 判断早見表

| 値 | 記号 | 種類（確定）| 主因 | 理由の要点 |
|----|---|:---:|---|---|
| **0.1µF** | C9,C11,C17,C19,C21,C29,C33,C34,C26 ほか | **セラミック(X5R可/X7R)** | 高周波デカップリング | IC電源ピン直近のHFバイパス。**低ESL/低ESRが必須**でMLCC一択。電解はESL大でこの用途に使えない。無極性。**X5RでOK（本機は85℃上限で十分）／耐圧50Vは維持**。|
| **1µF** | C8,C10,C12,C20,C28,C30 ほか | **セラミック(X5R可/X7R)** | 中域デカップリング／DC-DC | ADC AVDD/DVDD/CAP・AMC VDD2・AMCのDC-DC高圧側。数百kHz〜MHzの応答が要る。**MLCC**。電解不可。**X5R可／50V維持**。|
| **10µF** | C16,C18,C25,C45,C46 | **セラミック(X5R)** | LDO安定化／πフィルタ | ADP7142は**セラミック出力C前提で安定**（低ESR領域で設計）。πフィルタ(C45/C46)は**低ESRでこそHF減衰**が効く。→ MLCCが正解。ここを電解にするとLDO発振やπの効き低下の恐れ。|
| **47nF** | C1,C5 | **セラミック C0G/NP0** | フィルタ時定数 | AAF差動C。**容量の絶対精度・温度/電圧安定性・低誘電吸収**が両ch整合＝位相精度に直結。X7Rですら容量変動大でNG。**C0G/NP0必須**（代替はフィルム）。電解は論外（極性・巨大公差・漏れ電流）。|
| **1nF** | C2,C3,C6,C7,C31,C33 ほか | **セラミック C0G/NP0** | フィルタ／HF | AAFコモンモードC・AMC高圧側HF。小容量・高安定が要る。**C0G**。電解不可。|
| **100µF** | C43, C24 | **電解**（低ESR/ポリマー/タンタル可）| バルク蓄電 | HLK出力平滑・ESP32 5Vバルク。**大容量を安価・小型に**確保するのが目的で、動作は低周波(系統/突入)。この容量域でMLCCは高価・大型・**DCバイアスで実効容量が大きく減る**ため電解が実用的。|
| **470µF** | C44 | **電解**（低ESR/ポリマー可）| ESP32送信ピーク吸収 | WiFi送信バーストの大電流を近接供給。**大容量＋十分なリプル電流定格**が要る。MLCCで470µFは非現実的。電解（またはポリマー）。|

#### なぜ小容量〜10µFは「セラミック」なのか
- **周波数**：デカップリング/フィルタが効くべき帯域は数百kHz〜数十MHz。ここでは**ESL（等価直列インダクタンス）とESRの小ささ**が支配的で、MLCCが圧倒的に有利。電解は内部構造上ESL/ESRが大きく、高周波でインピーダンスが下がらず**役に立たない**。
- **LDO(ADP7142)の安定性**：本LDOは**低ESRのセラミック出力コンデンサを前提**に位相補償されている。ここに高ESRの電解を単独で置くと**発振/不安定**の懸念。→ C18/C19（出力）は必ずMLCC。
- **πフィルタ(L1＋C45/C46)**：LCフィルタの減衰は**コンデンサのESRが低いほど深い**。C45/C46は低ESRのMLCCであること。
- **AAF(47nF/1nF)**：フィルタのfc・群遅延・**両ch整合**が測定精度（TVE・位相）を決める。**C0G/NP0**は容量が電圧・温度でほぼ動かず、誘電吸収も小さい。X7Rは容量変動が大きく両ch整合を崩すため**明確にNG**、電解は極性・公差・漏れで**使用禁止**。

#### なぜ100µF/470µFだけ「電解」なのか
- **目的が違う**：これらは高周波バイパスではなく、**低周波のエネルギー貯蔵（バルク）**。ESP32のWiFi送信突入電流やHLK出力の平滑を担う。必要なのは「大きな容量」と「リプル電流定格」であり、超高周波特性は不要。
- **サイズ・コスト・DCバイアス**：100〜470µFをMLCCで作ると**高価・大型**なうえ、MLCCは**印加電圧で実効容量が大きく低下（DCバイアス特性）**するため、公称値どおりの蓄電が得にくい。低ESR電解/ポリマー/タンタルなら**小型・安価に大容量**を確保できる。
- **HF成分は別途MLCCで補う**：電解は高周波が苦手なので、**必ず近傍に小容量MLCCを並列**にする（本設計は C24[100µF電解]＋C25[10µF]＋C26[0.1µF]、C43[100µF電解]＋C45/C46[10µF MLCC] と既に対応済み）。この「電解＝低周波バルク／MLCC＝高周波バイパス」の**役割分担**が要点。

#### 実務上の注意
- **C44(470µF)は極性あり**。基板の＋/−向きを厳守（ネットリスト §20 も `C24.1=+` 等、電解は極性表記）。MLCC群は無極性。
- **電解は低ESR品を選ぶ**（EEU-FR1C系＝低ESR）。ESP32ピーク吸収・LDO/πの安定に効く。長寿命・無極性が欲しければ**導電性ポリマー**への格上げも可（§6 参照）。
- **温度**：電解は寿命が温度依存。放熱器レスのHLK近傍でも周囲温度に注意（105℃品推奨）。MLCCは温度安定だが**X5R/X7Rは±定格電圧の範囲でDCバイアス減**を織り込む（本設計は50V/25V品でマージン確保済み）。
- **代替の余地**：100µF/470µFは**タンタル／導電性ポリマー**でも可（低ESR・面実装）。ただしタンタルは**耐圧マージン（実効2倍以上）**を取ること。逆に小容量側を電解へ置き換えるのは**不可**。

---

## 3. AMC3330（電圧）／AMC3302（電流）デカップリング（DS SBASA34B §7.4 準拠）

> AMC3330・AMC3302は**同じDC-DC内蔵アーキテクチャ**なのでデカップリングは共通。**2個（U1・U5）分**必要。

| ノード（ピン）| 必要C | 使用型番 | 戻り先 |
|---|---|---|---|
| HLDO_OUT(5) | 1nF ＋ 100nF(0.1µF) | GRM2165C1H102JA01J ＋ GRM21BR71H104KA01L | **HGND**（高圧側）|
| DCDC_OUT(1)＝HLDO_IN(3) | 1nF ＋ 1µF | GRM2165C1H102JA01J ＋ GRM21BR71H105KA12L | **HGND**（高圧側）|
| DCDC_IN(16)＝LDO_OUT(13) | 100nF(0.1µF) | GRM21BR71H104KA01L | **GND**（低圧側）|
| VDD2(12) | 1nF ＋ 1µF | GRM2165C1H102JA01J ＋ GRM21BR71H105KA12L | **GND**（低圧側）|

- **高圧側Cは HGND、低圧側Cは GND** へ戻す（絶縁境界をまたがない）。
- IC1個あたり 1nF×3、0.1µF×2、1µF×2 程度 → **U1+U5で約2倍**（購入数に含む）。
- 電圧ch(U1)：C20/C21(VDD2) ほか。電流ch(U5)：C28,C29(VDD2)/C30,C31(DCDC高)/C32,C33(HLDO_OUT)/C34(DCDC低)。

---

## 4. 電源部・半導体（v3.2 で新規）

| 部品 | 記号 | 代表型番 | メーカー | 主要スペック | 推奨購入数 |
|---|---|---|---|---|:---:|
| 絶縁AC-DCモジュール | U6 | **HLK-10M05** | Hi-Link | AC100-240V→DC5V 2A(10W)・強化絶縁 | 1 |
| 低ノイズLDO(3.3V固定) | U4 | **ADP7142AUJZ-3.3**（TSOT-23-5）| Analog Devices | 40V/200mA/低ノイズ・入出力C≥2.2µF | 2 |
| πフィルタ用ビーズ | L1 | **BLM31PG601SN1**（1206, 600Ω@100MHz, 3A, 低DCR）| Murata | 大電流ﾋﾞｰｽﾞ ≥2A/DCR≤50mΩ | 2 |
| 電源分岐ヒューズ | F2 | **0215.500MXP**（5×20mm, T0.5A, 250V）＋ホルダ | Littelfuse | AC250V/T/0.5A | 2 |

- **ADP7142** 結線（TSOT-23-5）：1=VIN(→+5V_F)、2=GND(→AGND)、3=EN(→VIN 常時ON)、4=SENSE(→VOUT)、5=VOUT(→+3.3V_A)。入力C=C16(10µF)/C17(0.1µF)、出力C=C18(10µF)/C19(0.1µF)。
  - 代替：**ADP7142ACPZ-3.3**（LFCSP・SSピン有）／**ADP7118AUJZ-3.3**（20V品）／TPS7A20-3.3。
- **L1** は全電流(連続~1A/ピーク~2A)が通るため**信号用0603ビーズ不可**。代替：TDK **MPZ2012S601AT**（2A）、または 4.7–10µH/≥2A パワーインダクタ（Bourns SRR等）。
- **HLK-10M05** は AC入力(危険側)/DC出力(安全側)を基板上で明確分離・絶縁距離確保。

---

## 5. 発注サマリ（買い物リスト）

### 抵抗（Susumu RG2012P, 0.1%/25ppm ＋ シャント）
- [ ] RG2012P-514-B-T5（510kΩ）×10
- [ ] RG2012P-512-B-T5（5.1kΩ Rlo）×5
- [ ] RG2012P-102-B-T5（1kΩ）×10
- [ ] WSK2512R0015◯EA（1.5mΩ 4端子シャント 1W/2512）×3 ※≤25ppm厳守ならKRL/箔品へ

### 半導体・電源モジュール
- [ ] AMC3330（電圧ch 絶縁アンプ・SOIC-16 DWE）×1
- [ ] AMC3302（電流ch 絶縁シャントアンプ・SOIC-16 DWE）×1
- [ ] ADS131M02（2ch 24bit ΔΣ ADC・TSSOP-16）×1
- [ ] **HLK-10M05（絶縁AC-DC 5V/2A）×1**
- [ ] **ADP7142AUJZ-3.3（低ノイズLDO 3.3V固定・TSOT-23-5）×2**
- [ ] **BLM31PG601SN1（大電流フェライトビーズ 3A）×2**
- [ ] **0215.500MXP（T0.5A/250V ヒューズ）＋ホルダ ×2**

### コンデンサ
- [ ] GRM21BR61H104KA01L（0.1µF **X5R** 50V。X7R:GRM21BR71H104KA01L も可）×30
- [ ] GRM21BR61H105KA12L（1µF **X5R** 50V。X7R:GRM21BR71H105KA12L も可）×25
- [ ] GRM21BR61E106KA73L（10µF X5R 25V）×15
- [ ] EEU-FR1C101（100µF 低ESR電解 16V）×5
- [ ] **EEU-FR1C471L（470µF 低ESR電解 16V）×3**
- [ ] C3216C0G1H473J160AA（47nF C0G 50V 1206）×10
- [ ] GRM2165C1H102JA01J（1nF C0G 50V 0805）×15

> **v2.0から削除**：GRM21BR71E475KA73L（4.7µF・旧R1SE入力）、R1SE-0505 本体。

---

## 6. 代替・グレード変更

| 目的 | 代替案 |
|---|---|
| 手はんだが苦手 | 抵抗・C とも **1206**（RG3216P-xxx-B-T5 / GRM31…）にすると扱いやすい |
| スルーホールで作る | 抵抗＝金属皮膜0.1%（KOA MF, Vishay PTF56）、47nF＝WIMAフィルムでTH化 |
| シャント ≤25ppm 厳守 | Susumu **KRL2512** / Vishay 金属箔 / Isabellenhütte 等の高TCR等級へ |
| LDOにSS(ソフトスタート)が欲しい | **ADP7142ACPZ-3.3**（LFCSP-8, SSピン有。開放で380µs） |
| HLKのリプルをさらに抑える | L1 を **4.7–10µH/≥2Aパワーインダクタ** に格上げ（LC実効） |
| C0G 47nFが大きい | フィルム（WIMA FKP2 47nF/63V）に変更 |

### 6.1 コスト最適化方針（性能の最低ラインを守りつつ）

> **大前提**：本BOMの支配的コストは **IC/モジュール（HLK-10M05・ADS131M02・AMC3330/3302・ADP7142）** であり、受動部品は元々安い。受動で効くコストレバーは **①ブランド（Murata→Samsung/Yageo）／②耐圧の適正化／③許容差の緩和** の3つ。**性能に直結する所（下表「死守」列）は下げない**。

| 部品 | 最低保証スペック（死守）| 下げてよい所 | 安価候補（性能同等）|
|---|---|---|---|
| 0.1µF デカップリング | MLCC・X5R以上・**耐圧≥16V** | ブランド、50V→**25V** | Samsung **CL21B104KBCNNNC**（X7R50V, 激安）/ 25V X5R |
| 1µF デカップリング | MLCC・X5R以上・**耐圧≥16V** | ブランド、50V→**25V X5R** | Samsung **CL21A105KBFNNNE**（X5R25V）|
| 10µF | MLCC（**LDO出力C18/πC45,C46は低ESR維持**）| ブランド | Samsung **CL21A106KAYNNNE**（X5R25V）|
| **47nF（AAF差動 C1,C5）** | **C0G/NP0必須・両ch整合・1206以上** | ブランド or フィルム化 | **WIMA FKP2 47nF/63V**（THT・安い）/ 他社1206 C0G ※**0805不可** |
| 1nF（AAFコモン C2,C3,C6,C7 等）| **C0G/NP0必須** | ブランド、50V→**25V** | Samsung **CL21C102JBANNNC**（C0G50V, 激安）|
| 100µF/470µF バルク | 低ESR電解（**ESP32側 C24/C44 は必須**）| **C43（HLK出力）は汎用105℃電解可** | Nichicon/Rubycon 汎用（C43）、低ESRはESP32側のみ |
| 510k/5.1k/1k | **薄膜・≤50ppm**（**厚膜200ppmは不可**）| 許容差 **0.1%→0.5%**（校正で吸収）| Panasonic **ERA-6A**系（薄膜0.5%/25ppm）|
| シャント Rsh | **4端子ケルビン必須** | 既に標準WSK（75ppm）がコスト版 | 現行 WSK2512 のままでOK |

**下げてはいけない理由（最低ライン）**
- **AAFの C0G と 精度抵抗の薄膜**：容量/抵抗の温度・電圧安定と**両ch整合**が位相精度＝TVEを決める。X7Rや厚膜(200ppm)にすると校正でも取りきれない**ドリフト＆ch間ズレ**が出る。→ ブランドは変えて安くできても、**種別（C0G・薄膜）は死守**。
- **LDO出力C（C18）・πフィルタC（C45/C46）**：ADP7142は低ESRセラミック前提で安定。ESP32バルク（C24/C44）は低ESRでバースト吸収。ここのESRは性能値。
- **シャント4端子**：配線抵抗を測定値に混ぜない必須要件。

**素直に効くコストダウン**
- MLCC群を **Murata GRM → Samsung CL21 / Yageo** に置換（同じ X5R/X7R・C0G で **約1/2〜1/3**、性能同等）。
- 抵抗の許容差を **0.1%→0.5%**（低ppmは維持）に緩め、ブランドを Panasonic ERA 等へ。
- デカップリング/コモンモードCの耐圧を **50V→25V**（3.3/5Vレールなら十分、DCバイアス減も軽微）。

> ★**注意（値の取り違え）**：`GRM2165C1H472JA01D` は **4.7nF（`472`=47×10²pF）** であり、AAF差動Cの **47nF（`473`=47×10³pF）ではない**。10倍小さく fc≈17kHz となり fs/2 を超えて**アンチエイリアスが破綻**する。加えて **47nF C0G は0805では作れず1206以上が必須**（容積制約）。→ 47nF枠は **1206 C0G のまま**、または **フィルム（WIMA FKP2 47nF/63V）** を使う。

---

## 7. 部品記号 早見（仕様書 v3.2 §20 より）

| 記号 | 値 | 役割 |
|---|----|----|
| R1,R2,R3 | 510k | 分圧上側 |
| R4 | 5.1k | 分圧下側（Rlo・1/301）|
| R5,R6 | 1k | 電圧ch AAF直列 |
| R12,R13 | 1k | 電流ch AAF直列 |
| **Rsh** | **1.5mΩ** | **電流シャント（L線直列・4端子）** |
| C1 | 47nF | 電圧ch 差動AAF |
| C2,C3 | 1nF | 電圧ch コモンモードAAF |
| C5 | 47nF | 電流ch 差動AAF |
| C6,C7 | 1nF | 電流ch コモンモードAAF |
| C8,C9 | 1µF/0.1µF | ADC AVDD |
| C10,C11 | 1µF/0.1µF | ADC DVDD |
| C12 | 1µF | ADC CAP |
| **C16,C17** | **10µF/0.1µF** | **ADP7142 LDO 入力（+5V_F）** |
| **C18,C19** | **10µF/0.1µF** | **ADP7142 LDO 出力（+3.3V_A）** |
| C20,C21 | 1µF/0.1µF | AMC3330(U1) VDD2系 |
| C24,C25,C26 | 100µF/10µF/0.1µF | ESP32 5V |
| C28,C29 | 1µF/0.1µF | AMC3302(U5) VDD2系 |
| C30,C31 | 1µF/1nF | AMC3302(U5) DC-DC高圧側 |
| C32,C33 | 0.1µF/1nF | AMC3302(U5) HLDO_OUT |
| C34 | 0.1µF | AMC3302(U5) DC-DC低圧側 |
| **C43** | **100µF** | **HLK出力バルク（π入力側）** |
| **C44** | **470–1000µF** | **ESP32直近バルク** |
| **C45,C46** | **10µF/10µF** | **πフィルタ（C45=π入力, C46=π出力）** |
| **L1** | ﾋﾞｰｽﾞ≥2A | **πフィルタ直列素子** |
| **F2** | T0.5A | 電源分岐ヒューズ |

> IC/モジュール：**U1=AMC3330（電圧）／U5=AMC3302（電流）／U2=ADS131M02／U4=ADP7142(LDO)／U6=HLK-10M05**。
> **削除（v2.0→v3.2）**：U3=R1SE-0505、C4(VCM)、C14/C15(旧R1SE入力)、旧C16/C17(旧R1SE出力)。

---

## 8. KiCad フットプリント割当

> KiCad 7/8 標準ライブラリの `ライブラリ:フットプリント` 名。手はんだ主体なら SMD は `_HandSolder` 付き変種（パッド大）を推奨。
> **★印＝標準ライブラリに無く、カスタム作成 or ベンダ/SnapEDA等の取込みが必要。**

### 受動部品（SMD/THT）

| 部品記号 | 部品 | サイズ/PKG | KiCad フットプリント |
|---|---|---|---|
| R1,R2,R3 / R4 / R5,R6,R12,R13 | 抵抗（RG2012P）| 0805(2012) | `Resistor_SMD:R_0805_2012Metric`（手はんだ:`..._Pad1.20x1.40mm_HandSolder`）|
| **Rsh** | シャント（WSK2512, **4端子ケルビン**）| 2512 | ★ `Resistor_SMD:R_2512_6332Metric` は2端子用。**4端子Kelvinは要カスタム/ベンダ取込**（Vishay WSK2512 の4パッド外形）|
| C（0.1µF/1µF/10µF, MLCC）| セラミック | 0805(2012) | `Capacitor_SMD:C_0805_2012Metric`（手はんだ:`..._HandSolder`）|
| C1,C5（47nF C0G）| セラミック | 1206(3216) | `Capacitor_SMD:C_1206_3216Metric` |
| C2,C3,C6,C7,C31,C33（1nF C0G）| セラミック | 0805(2012) | `Capacitor_SMD:C_0805_2012Metric` |
| C24,C43（100µF 電解, EEU-FR φ6.3）| 電解(THT) | φ6.3/P2.5 | `Capacitor_THT:CP_Radial_D6.3mm_P2.50mm` |
| **C44（470µF 電解, EEU-FR φ10）** | 電解(THT) | φ10/P5.0 | `Capacitor_THT:CP_Radial_D10.0mm_P5.00mm` |
| **L1**（BLM31 ビーズ）| インダクタ/ビーズ | 1206(3216) | `Inductor_SMD:L_1206_3216Metric` |

### 半導体・モジュール

| 部品記号 | 部品 | パッケージ | KiCad フットプリント |
|---|---|---|---|
| U1, U5 | AMC3330 / AMC3302 | **SOIC-16 (DWE, ワイド0.3")** | `Package_SO:SOIC-16W_7.5x10.3mm_P1.27mm` |
| U2 | ADS131M02 | TSSOP-16 | `Package_SO:TSSOP-16_4.4x5mm_P0.65mm` |
| **U4** | ADP7142AUJZ-3.3 | **TSOT-23-5** | `Package_TO_SOT_SMD:SOT-23-5`（TSOT-23-5互換。厳密なTSOT外形が要れば要確認）|
| U4(代替) | ADP7142ACPZ-3.3 | LFCSP-8 (3×3) | `Package_DFN_QFN:LFCSP-8-1EP_3x3mm_P0.5mm_...`（DS外形で選択）|
| **U6** | **HLK-10M05** | 基板実装モジュール(4端子) | ★ **標準に無し。要カスタム作成**（AC in L/N, +Vo, −Vo。DSの外形寸法・ピンピッチで作図。SnapEDA等に有）|
| **F2** | 5×20mm ヒューズホルダ | THT クリップ | `Fuse:Fuseholder_Cylinder-5x20mm_Schurter_0031_8201_Horizontal`（使用ホルダに合わせ選択）|

### 外部ボード接続（ピンヘッダ実装の場合・参考）

| 接続先 | フットプリント例 |
|---|---|
| NUCLEO-F446RE（Morpho/Arduino） | `Connector_PinHeader_2.54mm:PinHeader_1x**_P2.54mm_Vertical`（該当ピン数）|
| ESP32-WROOM 開発ボード | `Connector_PinHeader_2.54mm:PinHeader_1x19_P2.54mm_Vertical` ×2（ボード幅に合わせ）|
| L76K GPS HAT | `Connector_PinHeader_2.54mm:PinHeader_1x**_P2.54mm_Vertical`（引き出す信号分）|

> **注意点**
> - ★の **Rsh(4端子ケルビン)** と **HLK-10M05** は標準ライブラリに無いので、データシート外形からカスタム作成、または SnapEDA / Ultra Librarian / メーカー提供の KiCad データを取り込む。
> - **SOIC-16W(DWE)** は幅広(300mil)。狭幅の `SOIC-16_3.9x9.9mm`（150mil）と**間違えない**こと。
> - AMC3330/AMC3302 の **DC-DC系ピン・HGND** はワイドSOICのピン割当をDSで確認（絶縁境界がパッケージ中央を跨ぐ）。
> - 手はんだ主体なら 0805/1206 は `_HandSolder` 変種、電解は THT を選ぶと作業性良。リフローなら標準SMDでOK。

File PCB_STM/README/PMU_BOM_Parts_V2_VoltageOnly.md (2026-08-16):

# PMU試作機 受動部品・電源部 発注BOM — Version 2（電圧のみ / 電流計測なし）

**版**：V2.0（`PMU_Specification_V2_VoltageOnly.md` V2.0 に対応。本体BOM `PMU_BOM_Parts.md` v3.2 から**電流計測部を削除**した派生版）

対応仕様書 `PMU_Specification_V2_VoltageOnly.md`（§10 部品リスト・§16 ネットリスト）の部品記号に、具体的なメーカー型番を割り当てたもの。

- 精度が効く抵抗：**薄膜（±0.1〜0.5% / ≤25ppm/℃ / 0805）**。ドリフト・両ch整合が測定精度（TVE）に直結する所は死守。
- コンデンサ：デカップリング/バルクは**コスト最適（ブランド置換）**、AAFのフィルタCは**C0G/NP0 死守**。
- 型番は代表例。**発注前に在庫・値・許容差/TCRコード・耐圧を必ず確認**すること。

> **本体BOM（電圧＋電流版）からの削除**：
> - **シャント Rsh**（WSK2512）、**電流用絶縁アンプ AMC3302(U5)** とそのデカップリング一式（C28〜C34）。
> - **電流ch AAF**：R12,R13（1kΩ）／C5（47nF）／C6,C7（1nF）。
> - → 1kΩ抵抗は **2本のみ**（R5,R6）、47nFは **1個のみ**（C1）、AMCデカップリングは **U1(AMC3330)の1個分だけ**。
>
> **設計方針（本BOMで反映済み）**：
> - **セラミック/電解の使い分け**：0.1〜10µF・47nF・1nF は **MLCC**、100µF/470µF バルクのみ **電解**（§2.3 参照）。
> - **X5Rでよい**（X7Rとの差は上限温度85℃/125℃のみ、精度は同じ±15%）。ただし**耐圧は適正化**（下記）。
> - **コスト最適**：Murata GRM → **Samsung CL21 / Yageo** で約1/2〜1/3、性能同等（§6 参照）。

---

## 1. 抵抗（薄膜。精度品は Susumu RG2012P：±0.1% / ±25ppm / 0805）

| 値 | 用途 | 部品記号 | 代表型番 | 主要スペック | 必要数 | 推奨購入数 |
|----|---|---|---|---|:---:|:---:|
| 510kΩ | 分圧上側（3直列）| R1, R2, R3 | **RG2012P-514-B-T5** | 0.1%/25ppm/0805/150V | 3 | 10 |
| 5.1kΩ | 分圧下側（Rlo）| R4 | **RG2012P-512-B-T5** | 0.1%/25ppm/0805（5.11kΩ/E96可）| 1 | 5 |
| 1kΩ | AAF直列（電圧ch）| R5, R6 | **RG2012P-102-B-T5** | 0.1%/25ppm/0805 | 2 | 10 |

> - **電流計測が無いため「両ch整合」は不要**だが、AAF群遅延は**絶対位相（UTC基準）**に効くので、R5/R6は同型番・低ppmを維持。
> - 510kΩは1本あたり33V分担、RG2012(0805)定格150Vで余裕。
> - **コスト緩和**：許容差 **0.1%→0.5%**（振幅は§12で校正吸収）＋ブランドを **Panasonic ERA-6A系（0.5%/25ppm）** へ。ただし**低ppm薄膜は維持**（厚膜200ppmはドリフト大で不可）。
> - **シャント Rsh は本V2では不要**（電流計測なし）。

---

## 2. コンデンサ

| 値 | 用途 | 部品記号 | 代表型番（Murata）| コスト最適候補 | 主要スペック | 必要数 | 推奨購入数 |
|----|---|---|---|---|---|:---:|:---:|
| 0.1µF | 各IC電源デカップリング | C9,C11,C17,C19,C21,C26 ＋AMC3330低圧側 | **GRM21BR61H104KA01L**（X5R）| Samsung **CL21B104KBCNNNC** | **X5R**（X7R可）/**50V**/0805 | ~8 | 20 |
| 1µF | ADC AVDD/DVDD/CAP・AMC3330 VDD2/DC-DC高圧側 | C8,C10,C12,C20 ＋AMC3330高圧側 | **GRM21BR61H105KA12L**（X5R）| Samsung **CL21A105KBFNNNE** | **X5R**（X7R可）/**50V**/0805 | ~6 | 15 |
| 10µF | **LDO入出力(C16/C18≥2.2µF)**・AVDDバルク・**πフィルタ(C45/C46)** | C16,C18,C25,C45,C46 | **GRM21BR61E106KA73L**（X5R）| Samsung **CL21A106KAYNNNE** | X5R/25V/0805 | 5 | 15 |
| 100µF | **HLK出力バルク(C43)**・ESP32 5Vバルク(C24)| C43, C24 | **EEU-FR1C101**（Panasonic・DK在庫あり）| Nichicon **UPW1C101MPD** | 低ESR電解/16V/φ6.3 | 2 | 5 |
| **470µF** | **ESP32直近バルク（送信ピーク吸収）**| **C44** | **UPW1C471MPD6**（Nichicon・DK在庫多数）| Panasonic **EEU-FR1E471**（25V・DK在庫あり）| 低ESR電解/16V/φ10 | 1 | 3 |
| 47nF | **AAF 差動C（C1）**| C1 | **C3216C0G1H473J160AA**（TDK）| WIMA **FKP2 47nF/63V**（フィルム）| **C0G**/50V/1206 | 1 | 5 |
| 1nF | AAF コモンモードC（C2,C3）・AMC高圧側 | C2,C3 ＋AMC3330高圧側 | **GRM2165C1H102JA01J** | Samsung **CL21C102JBANNNC** | **C0G**/50V/0805 | ~4 | 10 |

### 2.1 選定の要点（コスト最適 × 最低性能保証）
- **0.1µF / 1µF は X5R でよい**（X7R可）。X5R/X7Rの差は**上限温度のみ**（85℃/125℃）、容量精度はどちらも±15%。本機はラボ室内・低発熱で**X5Rで十分**。
  - ★**耐圧50Vは維持**（実効容量減=DCバイアスは耐圧・サイズで決まる。X5Rは25/16V品が多いが、そこへ落とすと実効容量が減る）。**0805・50V のまま X5R** が正解。
  - **1µF代替**：`GRM219R61H105KA73J`（1µF/X5R/50V/±10%/0805・厚み違いの等価バリアント）でも可。
- **10µF（LDO出力C18・πC45/C46）は低ESRのMLCC必須**。ADP7142は低ESRセラミック前提で安定、πはESR低いほど減衰が深い。25V品でOK（5Vレール）。
- **47nF / 1nF は必ず C0G/NP0**（AAF特性の温度・電圧安定＝位相/群遅延の再現性）。X7Rは容量変動大でNG、電解は論外。
- **100µF/470µF は低ESR電解**。ESP32のWiFi突入とHLK出力平滑。**C44はESP32直近**（バーストはL1を通れず近接バルクから供給）。

### 2.2 ★注意：容量コードの取り違え（47nF vs 4.7nF）
Murataの容量コードは「上2桁＋10のべき乗（pF）」。

| コード | 計算 | 容量 | 用途 |
|---|---|---|---|
| `473` | 47×10³ pF | **47nF** | **AAF差動C（C1）= これが正** |
| `472` | 47×10² pF | **4.7nF** | ← 値違い。使わない |
| `102` | 10×10² pF | 1nF | AAFコモンC（C2,C3）|

- **`GRM2165C1H472JA01D` は 4.7nF** であり **47nF ではない**。入れると fc≈17kHz となり fs/2(3.9kHz)を超え**アンチエイリアス破綻**。
- **47nF C0G は 0805 では作れない**（容積制約）。→ **1206 C0G** か **フィルム（WIMA FKP2）** を使う。

### 2.3 セラミック / 電解 の使い分け（なぜこの種別か）
- **0.1〜10µF・47nF・1nF＝セラミック(MLCC)**：数百kHz〜数十MHzで効くべきデカップリング/フィルタ。**低ESL/低ESR**が支配的でMLCC一択。電解はESL大で高周波に効かない。
- **100µF/470µF＝電解**：目的は高周波バイパスでなく**低周波のエネルギー貯蔵（バルク）**。大容量を安価・小型に確保。MLCCだと高価・大型・DCバイアス減が不利。**必ず近傍に小容量MLCCを並列**（C24[100µF]＋C25[10µF]＋C26[0.1µF]、C43[100µF]＋C45/C46[10µF] で対応済み）。
- **極性注意**：C24/C43/C44（電解）は＋/−向き厳守（−をDGNDへ）。MLCC群は無極性。

---

## 3. AMC3330（電圧）デカップリング（DS SBASA34B §7.4 準拠）

> 本V2は **AMC3330（U1）1個のみ**（電流用AMC3302は削除）。

| ノード（ピン）| 必要C | 使用型番 | 戻り先 |
|---|---|---|---|
| HLDO_OUT(5) | 1nF ＋ 0.1µF | GRM2165C1H102JA01J ＋ GRM21BR61H104KA01L | **HGND**（高圧側）|
| DCDC_OUT(1)＝HLDO_IN(3) | 1nF ＋ 1µF | GRM2165C1H102JA01J ＋ GRM21BR61H105KA12L | **HGND**（高圧側）|
| DCDC_IN(16)＝LDO_OUT(13) | 0.1µF | GRM21BR61H104KA01L | **GND**（低圧側）|
| VDD2(12) | 1µF ＋ 0.1µF（C20/C21）| GRM21BR61H105KA12L ＋ GRM21BR61H104KA01L | **GND**（低圧側）|

- **高圧側Cは U1.HGND、低圧側Cは U1.GND** へ戻す（絶縁境界をまたがない）。
- U1 1個あたり概算 **1nF×2〜3、0.1µF×2、1µF×2**（購入数に含む）。

---

## 4. 電源部・半導体

| 部品 | 記号 | 代表型番 | メーカー | 主要スペック | 必要数 | 推奨購入数 |
|---|---|---|---|---|:---:|:---:|
| 絶縁AC-DCモジュール | U6 | **HLK-10M05** | Hi-Link | AC100-240V→DC5V 2A(10W)・強化絶縁 | 1 | 1 |
| 低ノイズLDO(3.3V固定) | U4 | **ADP7142AUJZ-3.3**（TSOT-23-5）| Analog Devices | 40V/200mA/低ノイズ・入出力C≥2.2µF | 1 | 2 |
| πフィルタ用ビーズ | L1 | **BLM31PG601SN1**（1206, 600Ω@100MHz, 3A, 低DCR）| Murata | 大電流ﾋﾞｰｽﾞ ≥2A/DCR≤50mΩ | 1 | 2 |
| 電源分岐ヒューズ（ヒューズ本体）| F2 | **0215.500MXP**（5×20mm, T0.5A, 250V）| Littelfuse | AC250V/**T（スローブロー）**/0.5A | 1 | 2 |
| ↑用 **インライン**ホルダ | F2ホルダ | **BF301**（5×20mm・500V/10A・ワイヤリード）| MPD | ケーブル割り込み（基板非実装）| 1 | 1 |

- **ヒューズはインライン方式**：HLKへ行く **AC入力ケーブルの L（活線）側** に `BF301` を割り込ませ、中に `0215.500MXP`（T0.5A）を入れる。基板上には実装しない。N側には入れない。むき出し金属は熱収縮/端子カバーで絶縁。代替ホルダ：MPD **BF303**（500V/15A・在庫潤沢）／Littelfuse **01500274Z**（10A/350V）。
- **ADP7142** 結線（TSOT-23-5）：1=VIN(→+5V_F)、2=GND(→AGND)、3=EN(→VIN 常時ON)、4=SENSE(→VOUT)、5=VOUT(→+3.3V_A)。入力C=C16(10µF)/C17(0.1µF)、出力C=C18(10µF)/C19(0.1µF)。
  - 代替：**ADP7142ACPZ-3.3**（LFCSP・SSピン有）／**ADP7118AUJZ-3.3**（20V品）／TPS7A20-3.3。
- **L1** は全電流(連続~0.7A/ピーク~1A強)が通るため**信号用0603ビーズ不可**。代替：TDK **MPZ2012S601AT**（2A）、または 4.7–10µH/≥2A パワーインダクタ。
- **HLK-10M05** は AC入力(危険側)/DC出力(安全側)を基板上で明確分離・絶縁距離確保。

---

## 5. 発注サマリ（買い物リスト）

### 抵抗（薄膜 0.1〜0.5% / ≤25ppm）
- [ ] RG2012P-514-B-T5（510kΩ）×10
- [ ] RG2012P-512-B-T5（5.1kΩ Rlo）×5
- [ ] RG2012P-102-B-T5（1kΩ AAF）×10
- ※コスト緩和なら Panasonic ERA-6A系（0.5%/25ppm 薄膜）でも可。**シャントは不要**。

### 半導体・電源モジュール
- [ ] **AMC3330DWE**（電圧ch 絶縁アンプ・SOIC-16 DWE。リール品は AMC3330DWER）×1
- [ ] **ADS131M02IPWR**（2ch 24bit ΔΣ ADC・**TSSOP-20 / PW**）×1 ※小リールは ADS131M02I**PWT**。WQFN-20版もあり（別フットプリント）。**ADS131M01（1ch版）でも可**（配線簡素）
- [ ] HLK-10M05（絶縁AC-DC 5V/2A）×1
- [ ] ADP7142AUJZ-3.3（低ノイズLDO 3.3V固定・TSOT-23-5）×2
- [ ] BLM31PG601SN1（大電流フェライトビーズ 3A）×2
- [ ] 0215.500MXP（T0.5A/250V ヒューズ本体・5×20mm）×2
- [ ] **BF301（インライン・ヒューズホルダ 5×20mm/500V・ワイヤリード）×1**（代替 BF303 / Littelfuse 01500274Z）
- ※**AMC3302・シャントは本V2では発注不要**。

### コンデンサ（Murata基準／コスト最適はSamsung等）
- [ ] 0.1µF X5R 50V 0805：GRM21BR61H104KA01L（安価版 Samsung CL21B104KBCNNNC）×20
- [ ] 1µF X5R 50V 0805：GRM21BR61H105KA12L（安価版 Samsung CL21A105KBFNNNE）×15
- [ ] 10µF X5R 25V 0805：GRM21BR61E106KA73L（安価版 Samsung CL21A106KAYNNNE）×15
- [ ] 100µF 低ESR電解 16V：**EEU-FR1C101**（DigiKey在庫あり）×5 ／代替 Nichicon UPW1C101MPD
- [ ] 470µF 低ESR電解 16V：**UPW1C471MPD6**（Nichicon・DigiKey在庫多数）×3 ／代替 Panasonic EEU-FR1E471（470µF **25V**・在庫あり、φ大きめ）
      ※ Panasonic **EEU-FR1C471L**（16V）は末尾Lが特殊梱包で、素の **EEU-FR1C471** も現在DigiKeyバックオーダー。→ 上記に差し替え
- [ ] 47nF **C0G** 50V 1206：C3216C0G1H473J160AA（フィルム代替 WIMA FKP2 47nF/63V）×5
- [ ] 1nF **C0G** 50V 0805：GRM2165C1H102JA01J（安価版 Samsung CL21C102JBANNNC）×10

---

## 6. 代替・グレード変更 ／ コスト最適化

| 目的 | 代替案 |
|---|---|
| 手はんだが苦手 | 抵抗・C とも **1206**（RG3216P-xxx-B-T5 / GRM31…）にすると扱いやすい |
| スルーホールで作る | 抵抗＝金属皮膜0.1%（KOA MF, Vishay PTF56）、47nF＝WIMAフィルムでTH化 |
| LDOにSS(ソフトスタート)が欲しい | **ADP7142ACPZ-3.3**（LFCSP-8, SSピン有。開放で380µs） |
| HLKのリプルをさらに抑える | L1 を **4.7–10µH/≥2Aパワーインダクタ** に格上げ（LC実効） |
| C0G 47nFが大きい | フィルム（WIMA FKP2 47nF/63V）に変更 |
| **車載/高信頼グレードにしたい** | MLCCを **GCM（AEC-Q200・標準端子）** or **GCJ（軟端子・基板たわみ/熱サイクル対策）** にドロップイン置換。※**電気性能は同等でコスト増**。ラボ試作では通常不要 |

### コスト最適化方針（性能の最低ラインを守りつつ）
> 支配的コストは **IC/モジュール（HLK-10M05・ADS131M02・AMC3330・ADP7142）**。受動で効くレバーは **①ブランド ②耐圧 ③許容差** の3つ。**下表「死守」は下げない**。

| 部品 | 最低保証（死守）| 下げてよい所 | 安価候補 |
|---|---|---|---|
| 0.1µF / 1µF デカップリング | MLCC・X5R以上・**耐圧≥16V**（50V推奨）| ブランド、Murata→Samsung/Yageo | Samsung CL21 各種 |
| 10µF（LDO出力/π）| MLCC・**低ESR** | ブランド | Samsung CL21A106 |
| **47nF / 1nF（AAF）**| **C0G/NP0必須**（47nFは1206以上）| ブランド or フィルム化 | WIMA FKP2 / Samsung C0G |
| 100µF/470µF | 低ESR電解（**ESP32側C24/C44必須**）| **C43は汎用105℃電解可** | Nichicon/Rubycon |
| 510k/5.1k/1k | **薄膜・≤50ppm**（厚膜200ppm不可）| 許容差 0.1%→**0.5%** | Panasonic ERA-6A |

**素直に効くコストダウン**：MLCC群を **Murata GRM → Samsung CL21 / Yageo**（同じX5R/C0Gで約1/2〜1/3、性能同等）。抵抗は許容差0.1%→0.5%（低ppm維持）。電解はC43のみ汎用品でOK。

---

## 7. 部品記号 早見（V2仕様 §16 より）

| 記号 | 値 | 役割 |
|---|----|----|
| R1,R2,R3 | 510k | 分圧上側 |
| R4 | 5.1k | 分圧下側（Rlo・1/301）|
| R5,R6 | 1k | 電圧ch AAF直列 |
| C1 | 47nF | 電圧ch 差動AAF（**C0G**）|
| C2,C3 | 1nF | 電圧ch コモンモードAAF（**C0G**）|
| C8,C9 | 1µF/0.1µF | ADC AVDD |
| C10,C11 | 1µF/0.1µF | ADC DVDD |
| C12 | 1µF | ADC CAP |
| C16,C17 | 10µF/0.1µF | ADP7142 LDO 入力（+5V_F）|
| C18,C19 | 10µF/0.1µF | ADP7142 LDO 出力（+3.3V_A）|
| C20,C21 | 1µF/0.1µF | AMC3330(U1) VDD2系 |
| C24,C25,C26 | 100µF/10µF/0.1µF | ESP32 5V |
| C43 | 100µF | HLK出力バルク（π入力側）|
| C44 | 470–1000µF | ESP32直近バルク |
| C45,C46 | 10µF/10µF | πフィルタ（C45=π入力, C46=π出力）|
| L1 | ﾋﾞｰｽﾞ≥2A | πフィルタ直列素子 |
| F2 | T0.5A | 電源分岐ヒューズ |

> IC/モジュール：**U1=AMC3330（電圧）／U2=ADS131M02（ch0のみ, ADS131M01可）／U4=ADP7142(LDO)／U6=HLK-10M05**。
> **本V2で不在**：U5=AMC3302（電流）、シャント Rsh、C5(47nF)、C6/C7(1nF)、R12/R13(1k)、C28〜C34（AMC3302デカップリング）。

---

## 8. KiCad フットプリント割当

> KiCad 7/8 標準ライブラリの `ライブラリ:フットプリント` 名。手はんだ主体なら SMD は `_HandSolder` 付き変種を推奨。
> **★印＝標準ライブラリに無く、カスタム作成 or ベンダ/SnapEDA等の取込みが必要。**

### 受動部品

| 部品記号 | 部品 | サイズ/PKG | KiCad フットプリント |
|---|---|---|---|
| R1,R2,R3 / R4 / R5,R6 | 抵抗（RG2012P）| 0805(2012) | `Resistor_SMD:R_0805_2012Metric`（手はんだ:`..._Pad1.20x1.40mm_HandSolder`）|
| C（0.1µF/1µF/10µF, MLCC）| セラミック | 0805(2012) | `Capacitor_SMD:C_0805_2012Metric`（手はんだ:`..._HandSolder`）|
| C1（47nF C0G）| セラミック | 1206(3216) | `Capacitor_SMD:C_1206_3216Metric`（フィルム化なら THT）|
| C2,C3（1nF C0G）| セラミック | 0805(2012) | `Capacitor_SMD:C_0805_2012Metric` |
| C24,C43（100µF 電解, φ6.3）| 電解(THT) | φ6.3/P2.5 | `Capacitor_THT:CP_Radial_D6.3mm_P2.50mm` |
| C44（470µF 電解, φ10）| 電解(THT) | φ10/P5.0 | `Capacitor_THT:CP_Radial_D10.0mm_P5.00mm` |
| L1（BLM31 ビーズ）| インダクタ/ビーズ | 1206(3216) | `Inductor_SMD:L_1206_3216Metric` |

### 半導体・モジュール

| 部品記号 | 部品 | パッケージ | KiCad フットプリント |
|---|---|---|---|
| U1 | AMC3330 | **SOIC-16 (DWE, ワイド0.3")** | `Package_SO:SOIC-16W_7.5x10.3mm_P1.27mm` |
| U2 | ADS131M02IPWR（/M01）| **TSSOP-20（PW）** | `Package_SO:TSSOP-20_4.4x6.5mm_P0.65mm`（WQFN-20版は別FP／M01はDS参照）|
| U4 | ADP7142AUJZ-3.3 | **TSOT-23-5** | `Package_TO_SOT_SMD:SOT-23-5`（TSOT-23-5互換）|
| U4(代替) | ADP7142ACPZ-3.3 | LFCSP-8 (3×3) | `Package_DFN_QFN:LFCSP-8-1EP_3x3mm_P0.5mm_...` |
| **U6** | **HLK-10M05** | 基板実装モジュール(4端子) | ★ **標準に無し。要カスタム作成**（DS外形。SnapEDA等に有）|
| **F2** | インライン・ヒューズホルダ（BF301）| **基板非実装（ケーブル割り込み）** | フットプリント不要（AC入力ケーブルのL側に配線）|

### 外部ボード接続（ピンヘッダ実装の場合・参考）

| 接続先 | フットプリント例 |
|---|---|
| NUCLEO-F446RE（Morpho/Arduino） | `Connector_PinHeader_2.54mm:PinHeader_1x**_P2.54mm_Vertical`（該当ピン数）|
| ESP32-WROOM 開発ボード | `Connector_PinHeader_2.54mm:PinHeader_1x19_P2.54mm_Vertical` ×2 |
| L76K GPS HAT | `Connector_PinHeader_2.54mm:PinHeader_1x**_P2.54mm_Vertical`（引き出す信号分）|

> **注意点**
> - ★の **HLK-10M05** は標準ライブラリに無いので、DS外形からカスタム作成 or SnapEDA/メーカー提供データを取り込む。
> - **SOIC-16W(DWE)** は幅広(300mil)。狭幅 `SOIC-16_3.9x9.9mm`（150mil）と**間違えない**こと。
> - **本V2は4端子ケルビンのシャントが無い**ため、本体BOMにあった★Rsh(4端子)カスタムフットプリントは不要。
> - 手はんだ主体なら 0805/1206 は `_HandSolder` 変種、電解は THT を選ぶと作業性良。

---

## 9. 本体BOM（電圧＋電流版 v3.2）との差分

| 項目 | 本体 `PMU_BOM_Parts.md` v3.2 | 本V2（電圧のみ）|
|---|---|---|
| 電流用絶縁アンプ AMC3302(U5) | 有 | **削除** |
| シャント Rsh（WSK2512, 4端子）| 有 | **削除** |
| 電流ch AAF：R12,R13 / C5 / C6,C7 | 有 | **削除** |
| 1kΩ AAF | 4本（両ch）| **2本（電圧chのみ）** |
| 47nF C0G | 2個（C1,C5）| **1個（C1）** |
| AMCデカップリング一式 | U1+U5（2個分）| **U1のみ（1個分）** |
| ADC | ADS131M02（2ch）| ADS131M02（ch0のみ）/ **ADS131M01可** |
| 電源部（HLK/π/ADP7142）| 同一 | **同一** |

*(本V2は `PMU_Specification_V2_VoltageOnly.md` V2.0 に対応。電源・電圧FE・GPS・通信は本体と共通で、電流計測部のみ削除。)*

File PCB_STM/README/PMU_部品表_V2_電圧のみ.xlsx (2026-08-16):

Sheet: 部品表
単相PMU 試作機 部品表 — Version 2（電圧のみ / 電流計測なし）
出典: PMU_Specification_V2_VoltageOnly.md (V2.0) / PMU_BOM_Parts_V2_VoltageOnly.md ★黄色セル（単価）に金額を入力すると「金額」列が自動計算されます。
No. | 種類 | 部品名・用途 | 部品記号 | 商品名・型番 | メーカー | 主要スペック | 必要数 | 個数(発注) | 単価(円) | 金額(円) | 購入先・備考
1. 抵抗（薄膜 0.1% / ≤25ppm・精度死守）
1 | 抵抗 | 分圧 上側 Rhi（3直列＝1.53MΩ） | R1, R2, R3 | RG2012P-514-B-T5 | Susumu | 510kΩ / 0.1% / 25ppm / 0805 / 150V | 3 | 10 | 30 |  | 各33V分担。薄膜必須
2 | 抵抗 | 分圧 下側 Rlo（分圧比 1/301） | R4 | RG2012P-512-B-T5 | Susumu | 5.1kΩ / 0.1% / 25ppm / 0805 | 1 | 5 | 20 |  | 5.11kΩ(E96)可
3 | 抵抗 | AAF 直列（電圧ch） | R5, R6 | RG2012P-102-B-T5 | Susumu | 1kΩ / 0.1% / 25ppm / 0805 | 2 | 10 | 12.3 |  | 同型番で揃える（群遅延）
2. コンデンサ
4 | MLCC | 各IC電源デカップリング | C9,C11,C17,C19,C21,C26 ＋AMC低圧側 | GCM21BR91H104KA37L | Murata | 0.1µF / X5R / 50V / 0805 | 8 | 20 | 25 |  | 安価版: Samsung CL21B104KBCNNNC
5 | MLCC | ADC AVDD/DVDD/CAP・AMC3330 VDD2/高圧側 | C8,C10,C12,C20 ＋AMC高圧側 | GRM219R61H105KA73J | Murata | 1µF / X5R / 50V / 0805 | 6 | 15 | 16 |  | 安価版: Samsung CL21A105KBFNNNE
6 | MLCC | LDO入出力・AVDDバルク・πフィルタ | C16,C18,C25,C45,C46 | GRJ21BR61E106KE01K | Murata | 10µF / X5R / 25V / 0805 | 5 | 15 | 17 |  | 低ESR必須。安価版: Samsung CL21A106KAYNNNE
7 | 電解 | HLK出力バルク・ESP32 5Vバルク | C43, C24 | EEU-FR1C101 | Panasonic | 100µF / 低ESR電解 / 16V / φ6.3 | 2 | 5 | 66 |  | 代替: Nichicon UPW1C101MPD。極性注意
8 | 電解 | ESP32直近バルク（送信ピーク吸収） | C44 | UPW1C471MPD6 | Nichicon | 470µF / 低ESR電解 / 16V / φ10 | 1 | 3 | 108 |  | 代替: Panasonic EEU-FR1E471(25V)。極性注意
9 | MLCC | AAF 差動C（★C0G死守） | C1 | C3216C0G1H473J160AA | TDK | 47nF / C0G / 50V / 1206 | 1 | 5 | 86 |  | ★型番修正: GRM3195C1H472JA01D は472=4.7nFで誤り→473=47nFへ変更。単価は要再確認。代替 WIMA FKP2 47nF/63V
10 | MLCC | AAF コモンモードC・AMC高圧側 | C2, C3 ＋AMC高圧側 | C0805C102J5GACTU | KEMET | 1nF / C0G / 50V / 0805 | 4 | 10 | 12 |  | 安価版: Samsung CL21C102JBANNNC
3. 半導体（IC）
11 | IC | 絶縁アンプ（電圧ch・固定ゲイン2.0） | U1 | AMC3330DWE | Texas Instruments | SOIC-16W (DWE) / ±1V入力 / 絶縁DC-DC内蔵 | 1 | 1 | 661 |  | リール品は AMC3330DWER
12 | IC | 24bit ΔΣ ADC（ch0のみ使用） | U2 | ADS131M02IPWR | Texas Instruments | 2ch / 24bit / TSSOP-20(PW) / SPI | 1 | 1 | 718 |  | 小リール ADS131M02IPWT／1ch版 ADS131M01可
13 | IC | アナログ用 低ノイズLDO（3.3V固定） | U4 | ADP7142AUJZ-3.3-R7 | Analog Devices | TSOT-23-5 / 40V / 200mA / 入出力C≥2.2µF | 1 | 2 | 703 |  | 代替: ADP7142ACPZ-3.3(SSピン有)
4. 電源部・保護部品
14 | モジュール | 絶縁AC-DCモジュール（自給電の主電源） | U6 | HLK-10M05 | Hi-Link | AC100-240V→DC5V 2A(10W) / 強化絶縁 | 1 | 1 | 564 |  | KiCadフットプリントは要カスタム作成
15 | ビーズ | πフィルタ 直列素子（全電流が通る） | L1 | BLM31PG601SN1L | Murata | 1206 / 600Ω@100MHz / 3A / 低DCR | 1 | 2 | 54 |  | 代替: TDK MPZ2012S601AT。0603信号用は不可
16 | ヒューズ | 電源分岐ヒューズ 本体（HLK AC入力保護） | F2 | 0215.500MXP | Littelfuse | 5×20mm / T0.5A / AC250V / スローブロー | 1 | 2 | 389 |  | L(活線)側のみに挿入
17 | ホルダ | ヒューズホルダ | Fホルダ | 0031.8201 | Schurter inc. |  | 1 | 1 | 217 |  | 基板非実装。代替 BF303 / 01500274Z
5. ボード・モジュール（仕様書 §1）
18 | ボード | MCU（取得・フェーザ演算） | NUCLEO | NUCLEO-F446RE | STMicroelectronics | STM32F446RE / FPU / タイマ＋DMA | 1 | 1 | 2998 |  | JP5=E5V で +5V_F 給電
19 | ボード | WiFi通信（C37.118送信） | ESP32 | ESP32-WROOM-32E 開発ボード | Espressif | 3.3Vロジック / UART接続 / WiFi | 1 | 1 | 800 |  | 直近に470µFバルク(C44)
20 | モジュール | GPS 時刻同期（1PPS） | L76K | L76K GPS HAT | Waveshare | GPS/GLONASS/BeiDou/QZSS / 1PPS <30ns | 1 | 1 | 3662 |  | Piに挿さずSTM32へ配線。PPSピン要確認
6. 参考：仕様書 §14/§15 記載の周辺部品（型番未選定・要検討）
21 | ヒューズ | 商用入力 主ヒューズ | F1 | （要選定） |  | AC250V / T / ceramic HBC / 3〜10A | 1 | 1 |  |  | 仕様書§14。L側に挿入
22 | スイッチ | 商用入力 電源スイッチ | SW1 | （要選定） |  | AC定格スイッチ | 1 | 1 |  |  | 仕様書§14
23 | ホルダ | F1用 ヒューズホルダ | F1ホルダ | （要選定） |  | 5×20mm / AC250V以上 | 1 | 1 |  |  | 端子カバー付き推奨
24 | コネクタ | 外部ボード接続 ピンヘッダ | - | （要選定） |  | 2.54mm ピンヘッダ 各種 | 1 | 1 |  |  | NUCLEO/ESP32/L76K の引き出し分
25 | 基板 | PCB 製造 | - | （要発注） |  | JLCPCB/Elecrow 等 | 1 | 1 | 320 |  | 危険側/安全側の絶縁距離を確保
26 | 機構 | 絶縁ケース・端子カバー・熱収縮チューブ | - | （要選定） |  | 危険側を露出させない | 1 | 1 |  |  | 仕様書§14 安全設計
合計金額
【注意事項】
・型番は代表例です。発注前に在庫・値・許容差/TCRコード・耐圧を必ず確認してください。
・47nF は「473」が正（472=4.7nF は値違い。入れるとアンチエイリアス破綻）。47nF C0G は 0805 では作れないため 1206 かフィルム。
・47nF / 1nF（AAF）は C0G/NP0 必須。X7R・電解は不可。
・分圧/AAF抵抗は薄膜・≤50ppm を死守（厚膜200ppmはドリフト大で不可）。許容差は 0.1%→0.5% までなら緩和可。
・電解コンデンサ（C24 / C43 / C44）は極性厳守（−をDGNDへ）。
・ヒューズ F2 はインライン方式：AC入力ケーブルの L（活線）側に BF301 を割り込ませ、0215.500MXP を入れる。基板には実装しない。
・本V2では AMC3302（電流用絶縁アンプ）・シャント Rsh・電流ch AAF（R12/R13/C5/C6/C7）は不要です。
・第6節は仕様書に記載はあるが型番未確定の部品です。選定後に型番と金額を記入してください。

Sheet: 単価入力済み
PMU試作機 部品表 — 単価入力済みリスト（V2 電圧のみ）
「部品表」シートで単価を入力済みの 21 件を抽出 ／ Amount = Qty × Unit Price（1台分の実装コスト）
Category | Part Number | Manufacturer | Specifications | Qty | Unit Price (JPY) | Amount (JPY)
Resistor | RG2012P-514-B-T5 | Susumu | 510kΩ / 0.1% / 25ppm / 0805 / 150V | 3 | 30
Resistor | RG2012P-512-B-T5 | Susumu | 5.1kΩ / 0.1% / 25ppm / 0805 | 1 | 20
Resistor | RG2012P-102-B-T5 | Susumu | 1kΩ / 0.1% / 25ppm / 0805 | 2 | 12.3
MLCC | GCM21BR91H104KA37L | Murata | 0.1µF / X5R / 50V / 0805 | 8 | 25
MLCC | GRM219R61H105KA73J | Murata | 1µF / X5R / 50V / 0805 | 6 | 16
MLCC | GRJ21BR61E106KE01K | Murata | 10µF / X5R / 25V / 0805 | 5 | 17
Electrolytic Cap | EEU-FR1C101 | Panasonic | 100µF / 低ESR電解 / 16V / φ6.3 | 2 | 66
Electrolytic Cap | UPW1C471MPD6 | Nichicon | 470µF / 低ESR電解 / 16V / φ10 | 1 | 108
MLCC | C3216C0G1H473J160AA | TDK | 47nF / C0G / 50V / 1206 | 1 | 86
MLCC | C0805C102J5GACTU | KEMET | 1nF / C0G / 50V / 0805 | 4 | 12
IC | AMC3330DWE | Texas Instruments | SOIC-16W (DWE) / ±1V入力 / 絶縁DC-DC内蔵 | 1 | 661
IC | ADS131M02IPWR | Texas Instruments | 2ch / 24bit / TSSOP-20(PW) / SPI | 1 | 718
IC | ADP7142AUJZ-3.3-R7 | Analog Devices | TSOT-23-5 / 40V / 200mA / 入出力C≥2.2µF | 1 | 703
Module | HLK-10M05 | Hi-Link | AC100-240V→DC5V 2A(10W) / 強化絶縁 | 1 | 564
Ferrite Bead | BLM31PG601SN1L | Murata | 1206 / 600Ω@100MHz / 3A / 低DCR | 1 | 54
Fuse | 0215.500MXP | Littelfuse | 5×20mm / T0.5A / AC250V / スローブロー | 1 | 389
Fuse Holder | 0031.8201 | Schurter inc. |  | 1 | 217
Board | NUCLEO-F446RE | STMicroelectronics | STM32F446RE / FPU / タイマ＋DMA | 1 | 2998
Board | ESP32-WROOM-32E 開発ボード | Espressif | 3.3Vロジック / UART接続 / WiFi | 1 | 800
Module | L76K GPS HAT | Waveshare | GPS/GLONASS/BeiDou/QZSS / 1PPS <30ns | 1 | 3662
PCB | （要発注） |  | JLCPCB/Elecrow 等 | 1 | 320
Total
※ このシートは作成時点で単価が入っていた行のスナップショットです（「部品表」シートの No.21〜24, 26 は単価未入力のため含まれません）。
※ Amount = Qty × Unit Price。発注数（推奨購入数）ベースの合計は「部品表」シートを参照してください。

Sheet: 代替・安価候補
代替・安価候補（コスト最適化 / 在庫切れ時）
対象 | 標準型番（本表） | 代替・安価候補 | メーカー | 効果・注意点
0.1µF MLCC | GRM21BR61H104KA01L | CL21B104KBCNNNC | Samsung | 同 X5R/50V で約1/2〜1/3。耐圧50Vは維持（DCバイアス劣化のため）
1µF MLCC | GRM21BR61H105KA12L | CL21A105KBFNNNE / GRM219R61H105KA73J | Samsung / Murata | X5R 50V 維持。GRM219…は厚み違いの等価バリアント
10µF MLCC | GRM21BR61E106KA73L | CL21A106KAYNNNE | Samsung | 低ESR必須（LDO安定・πフィルタ減衰）。25V品でOK
47nF C0G | C3216C0G1H473J160AA | FKP2 47nF/63V（フィルム） | WIMA | 1206が大きい場合の代替。C0G相当の安定度
1nF C0G | GRM2165C1H102JA01J | CL21C102JBANNNC | Samsung | C0G 50V 維持
100µF 電解 | EEU-FR1C101 | UPW1C101MPD | Nichicon | C43 のみ汎用105℃電解でも可（ESP32側 C24/C44 は低ESR必須）
470µF 電解 | UPW1C471MPD6 | EEU-FR1E471（470µF/25V） | Panasonic | EEU-FR1C471(16V)はDigiKeyバックオーダー。25V品はφ大きめ
薄膜抵抗 全般 | RG2012P-xxx-B-T5 | ERA-6A 系（0.5% / 25ppm） | Panasonic | 許容差 0.1%→0.5% でコスト減（振幅は校正で吸収）。低ppm薄膜は維持
LDO U4 | ADP7142AUJZ-3.3 | ADP7142ACPZ-3.3 / ADP7118AUJZ-3.3 / TPS7A20-3.3 | ADI / TI | ACPZ は LFCSP-8・ソフトスタートピン有（開放で380µs）
ビーズ L1 | BLM31PG601SN1 | MPZ2012S601AT(2A) / 4.7-10µH ≥2A パワーインダクタ | TDK 他 | 全電流(連続~0.7A/ピーク~1A強)が通る。信号用0603は不可
ADC U2 | ADS131M02IPWR | ADS131M02IPWT（小リール） / ADS131M01（1ch版） | Texas Instruments | 本V2は ch0 のみ使用のため 1ch版でも可（配線簡素）
ヒューズホルダ | BF301 | BF303（500V/15A） / 01500274Z（10A/350V） | MPD / Littelfuse | 在庫状況に応じて選択
手はんだ性を上げたい | 0805 部品 | 1206（RG3216P-xxx-B-T5 / GRM31…） | - | 手はんだ主体なら KiCad は _HandSolder 変種フットプリントを推奨

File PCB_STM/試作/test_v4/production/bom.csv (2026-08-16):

Designator | Footprint | Quantity | Value | LCSC Part #
C1, C16, C17, C3 | 0805 | 4 | 1nF
C10, C4 | 0805 | 2 | 100nF
C12, C15, C28 | 0805 | 3 | 10uF
C13 | 1206 | 1 | 47nF
C2, C21, C23, C25, C5 | 0805 | 5 | 1uF
C20, C26 | 0805 | 2 | 2.2uF
C22, C24, C29, C6 | 0805 | 4 | 0.1uF
C27 | C_Radial_D10.0mm_H12.5mm_P5.00mm | 1 | 470uF
C9 | C_Radial_D6.3mm_H5.0mm_P2.50mm | 1 | 100uF
F1 | FUSE_0031.8201_SCH | 1 | 0031.8201
J1 | Altech_AK300_1x02_P5.00mm_45-Degree | 1 | TB
J2 | PinHeader_2x20_P2.54mm_Vertical | 1 | L76K_GPSHAT
J3 | PinSocket_2x19_P2.54mm_Vertical | 1 | NUCLEO_CN7
J4, J5 | PinSocket_1x19_P2.54mm_Vertical | 2 | ESP32
J6 | PinSocket_2x19_P2.54mm_Vertical | 1 | NUCLEO_CN10
R1, R3, R4 | 0805 | 3 | 510k
R6 | 0805 | 1 | 5.1k
R7, R8 | 0805 | 2 | 1k
R9 | 0201 | 1 | 0Ω
U1 | SOIC-16W_7.5x10.3mm_P1.27mm | 1 | AMC3330
U3 | Converter_ACDC_Hi-Link_HLK-10Mxx | 1 | HLK-10M05
U4 | TSSOP-20_4.4x6.5mm_P0.65mm | 1 | ADS131M04xPW
U5 | SOIC-8-1EP_3.9x4.9mm_P1.27mm_EP2.29x3mm | 1 | ADP7142ARDZ-3.3
フェライトビーズ11 | 1206 | 1 | 600

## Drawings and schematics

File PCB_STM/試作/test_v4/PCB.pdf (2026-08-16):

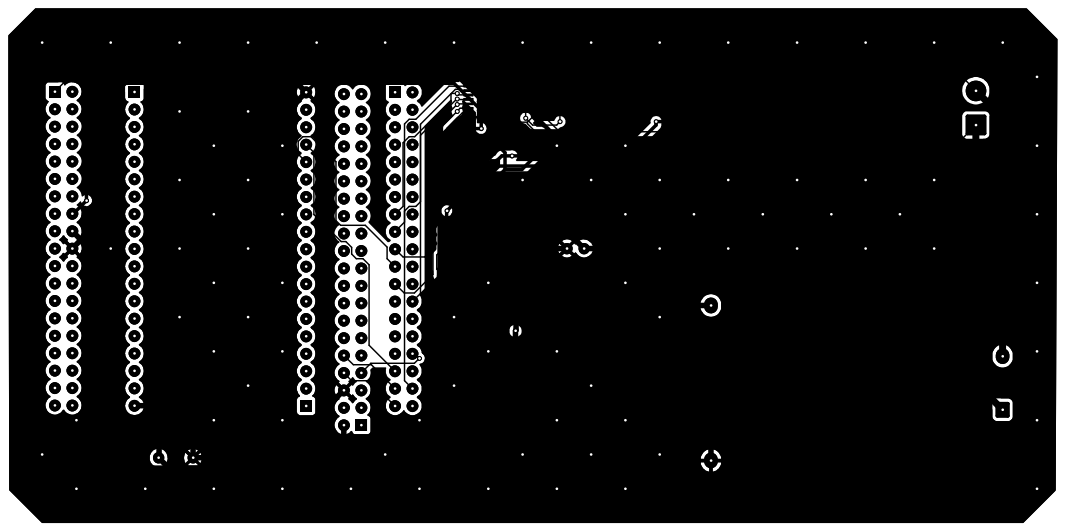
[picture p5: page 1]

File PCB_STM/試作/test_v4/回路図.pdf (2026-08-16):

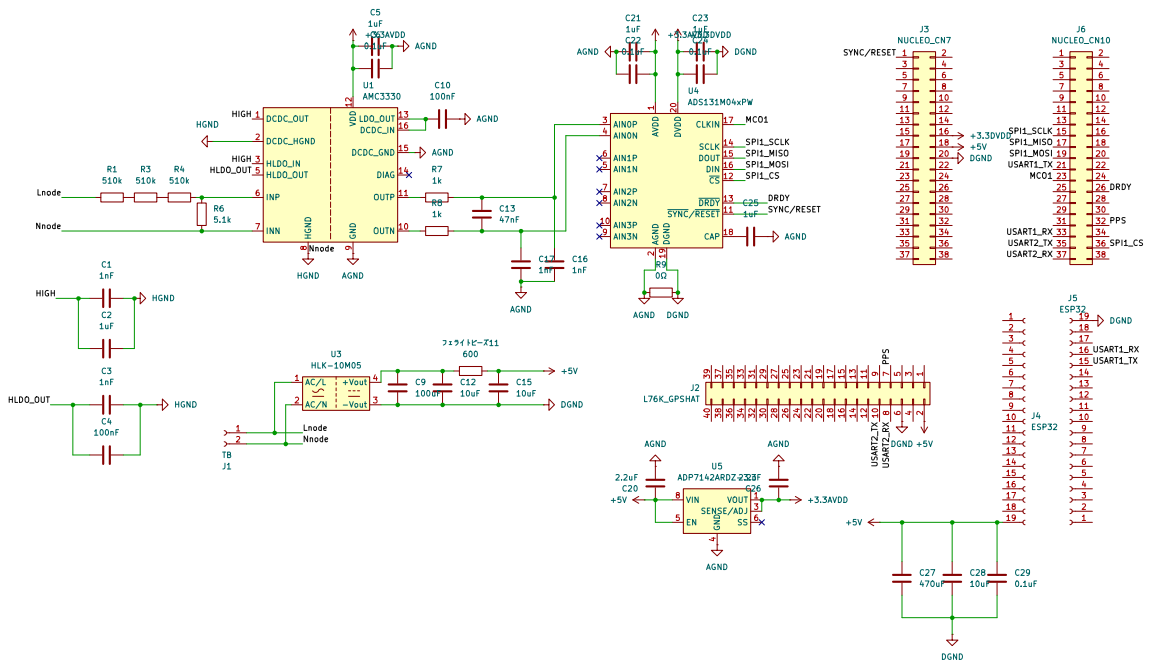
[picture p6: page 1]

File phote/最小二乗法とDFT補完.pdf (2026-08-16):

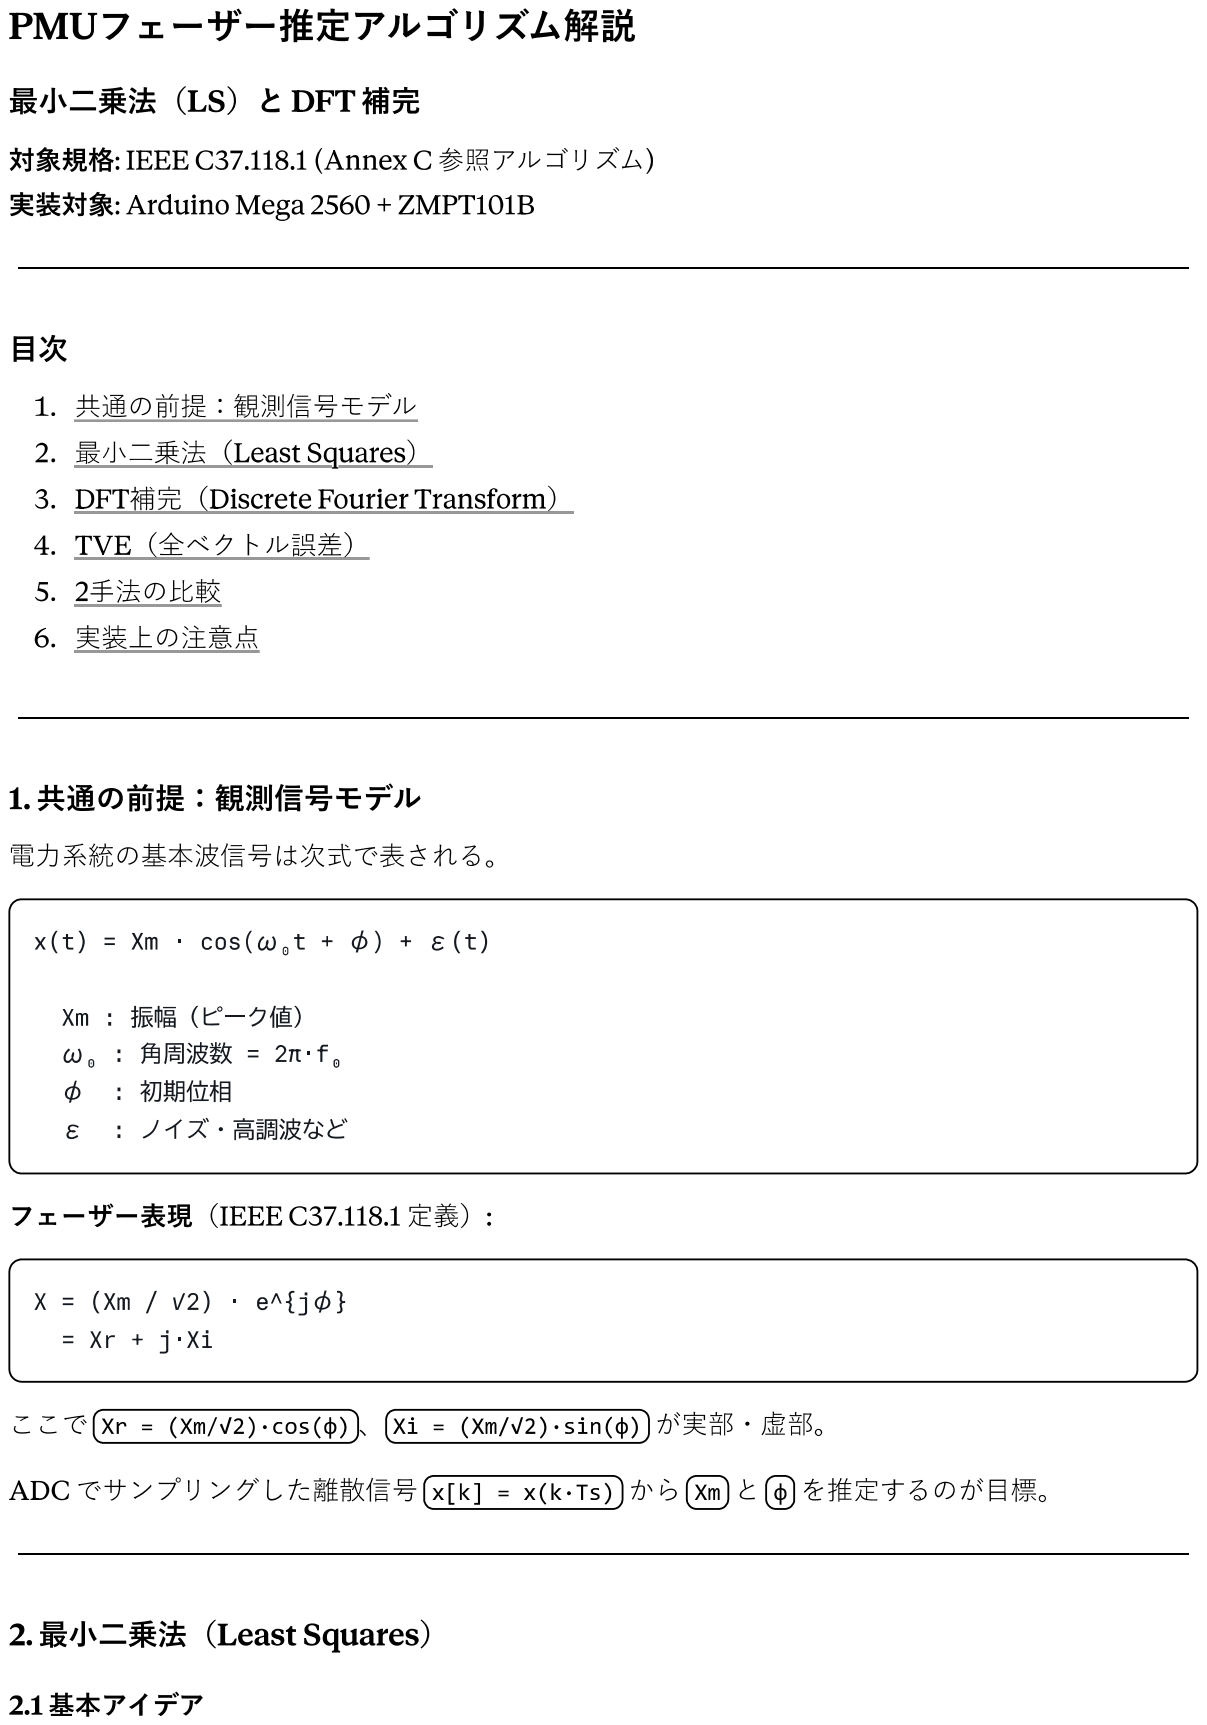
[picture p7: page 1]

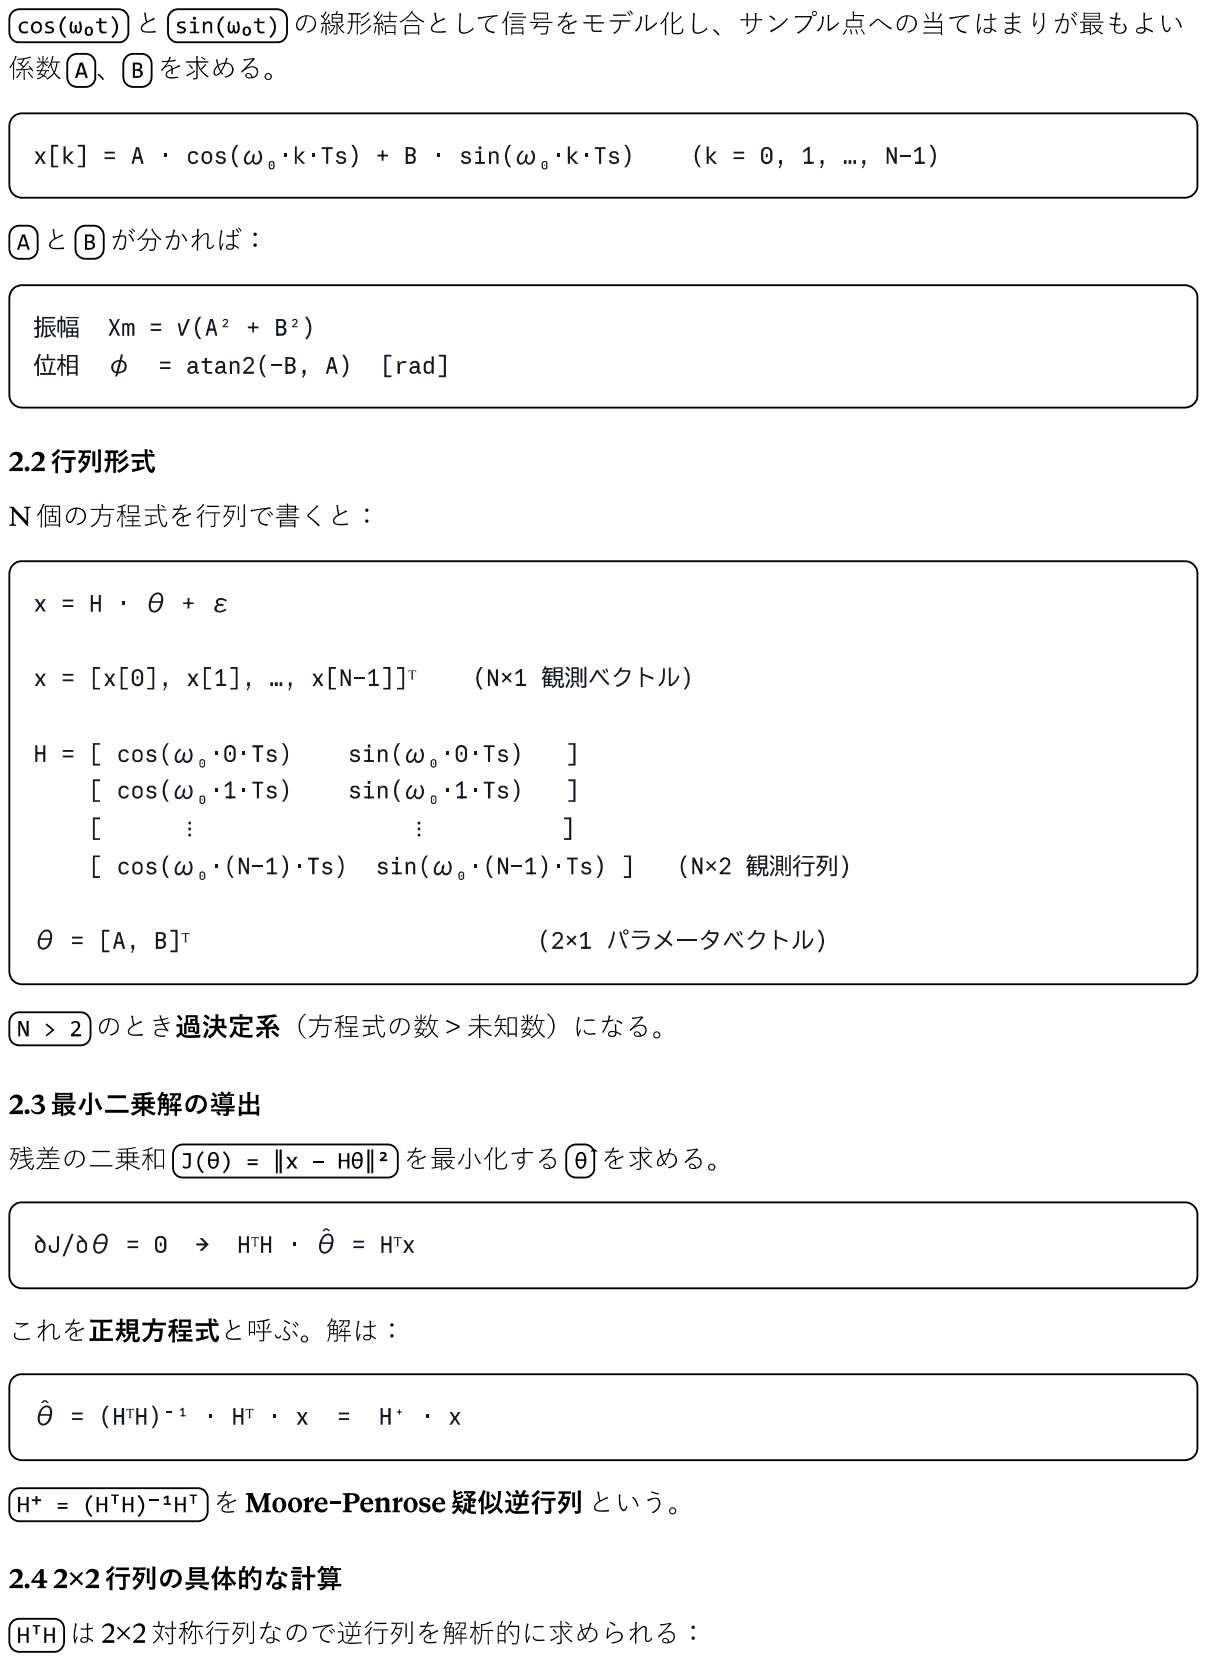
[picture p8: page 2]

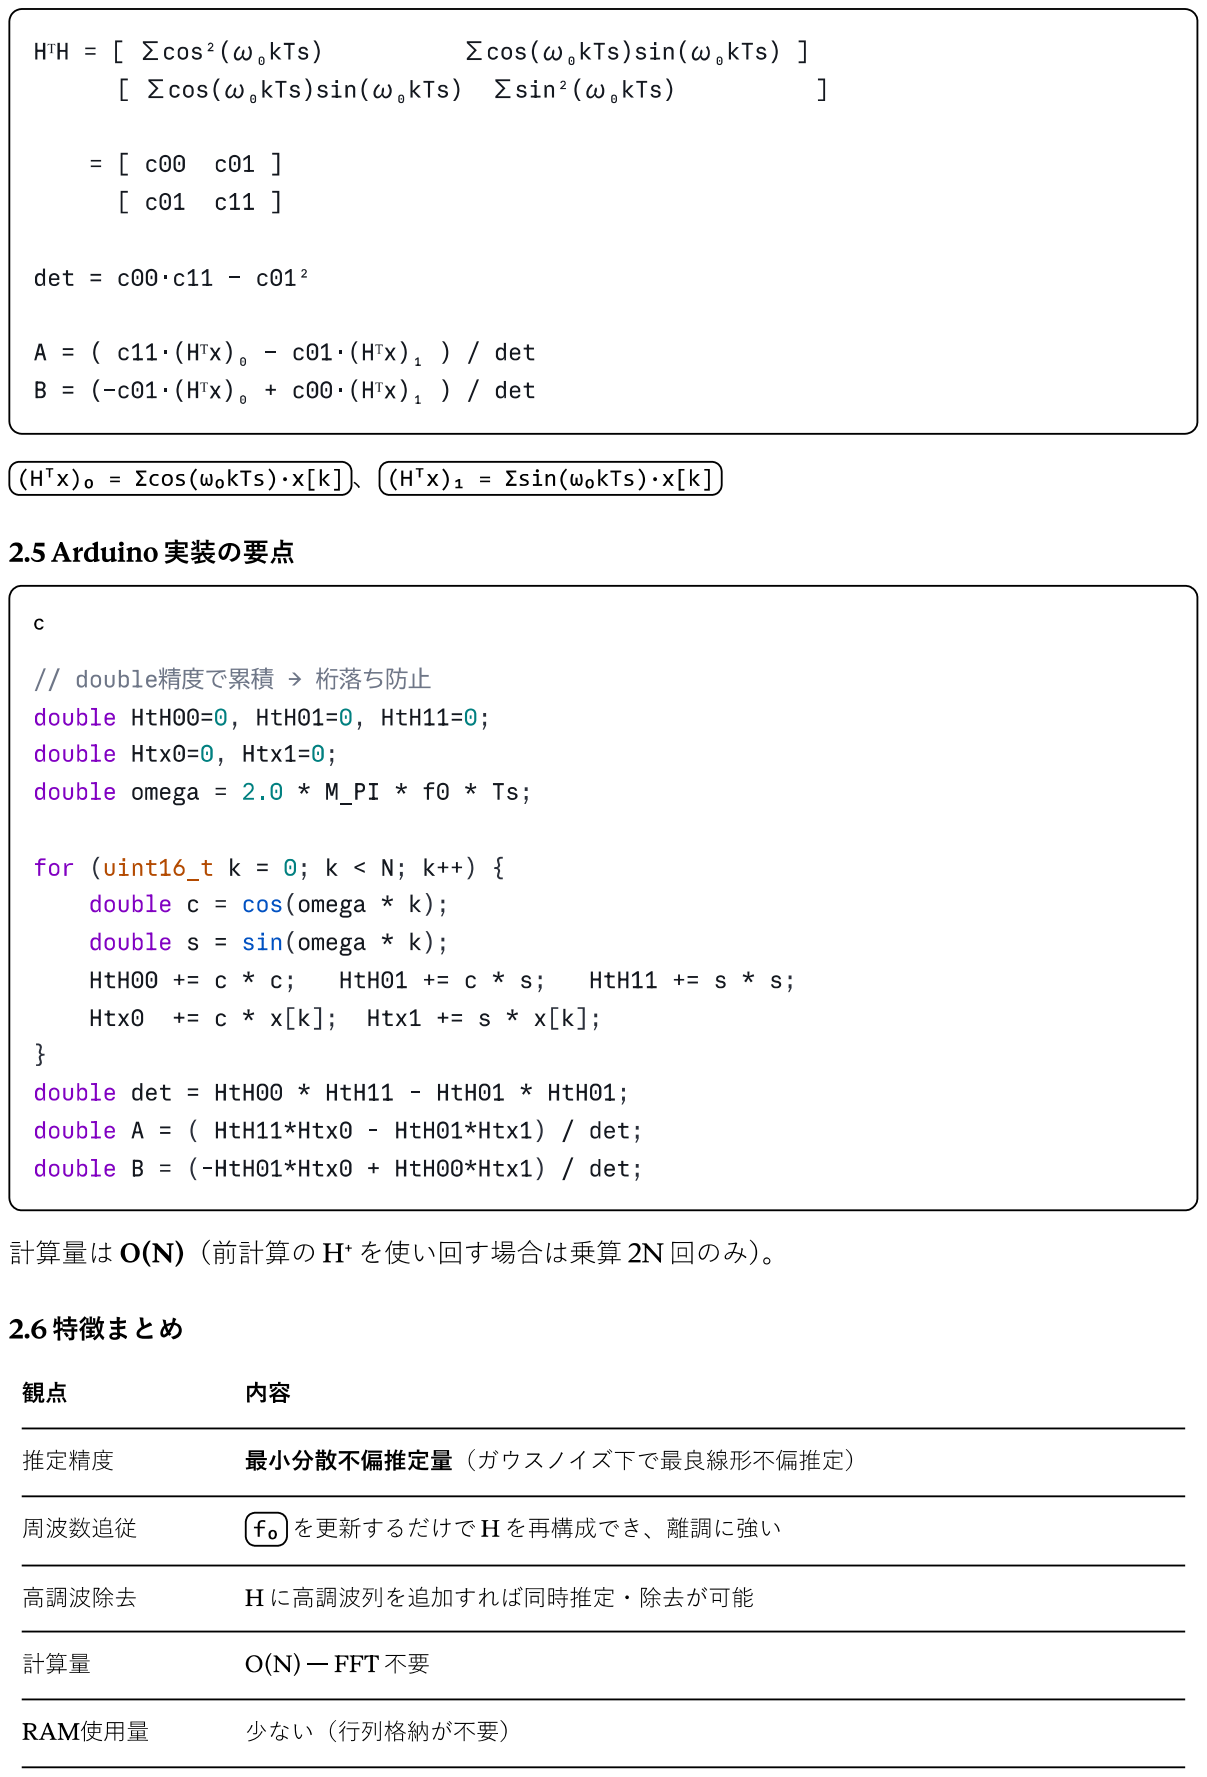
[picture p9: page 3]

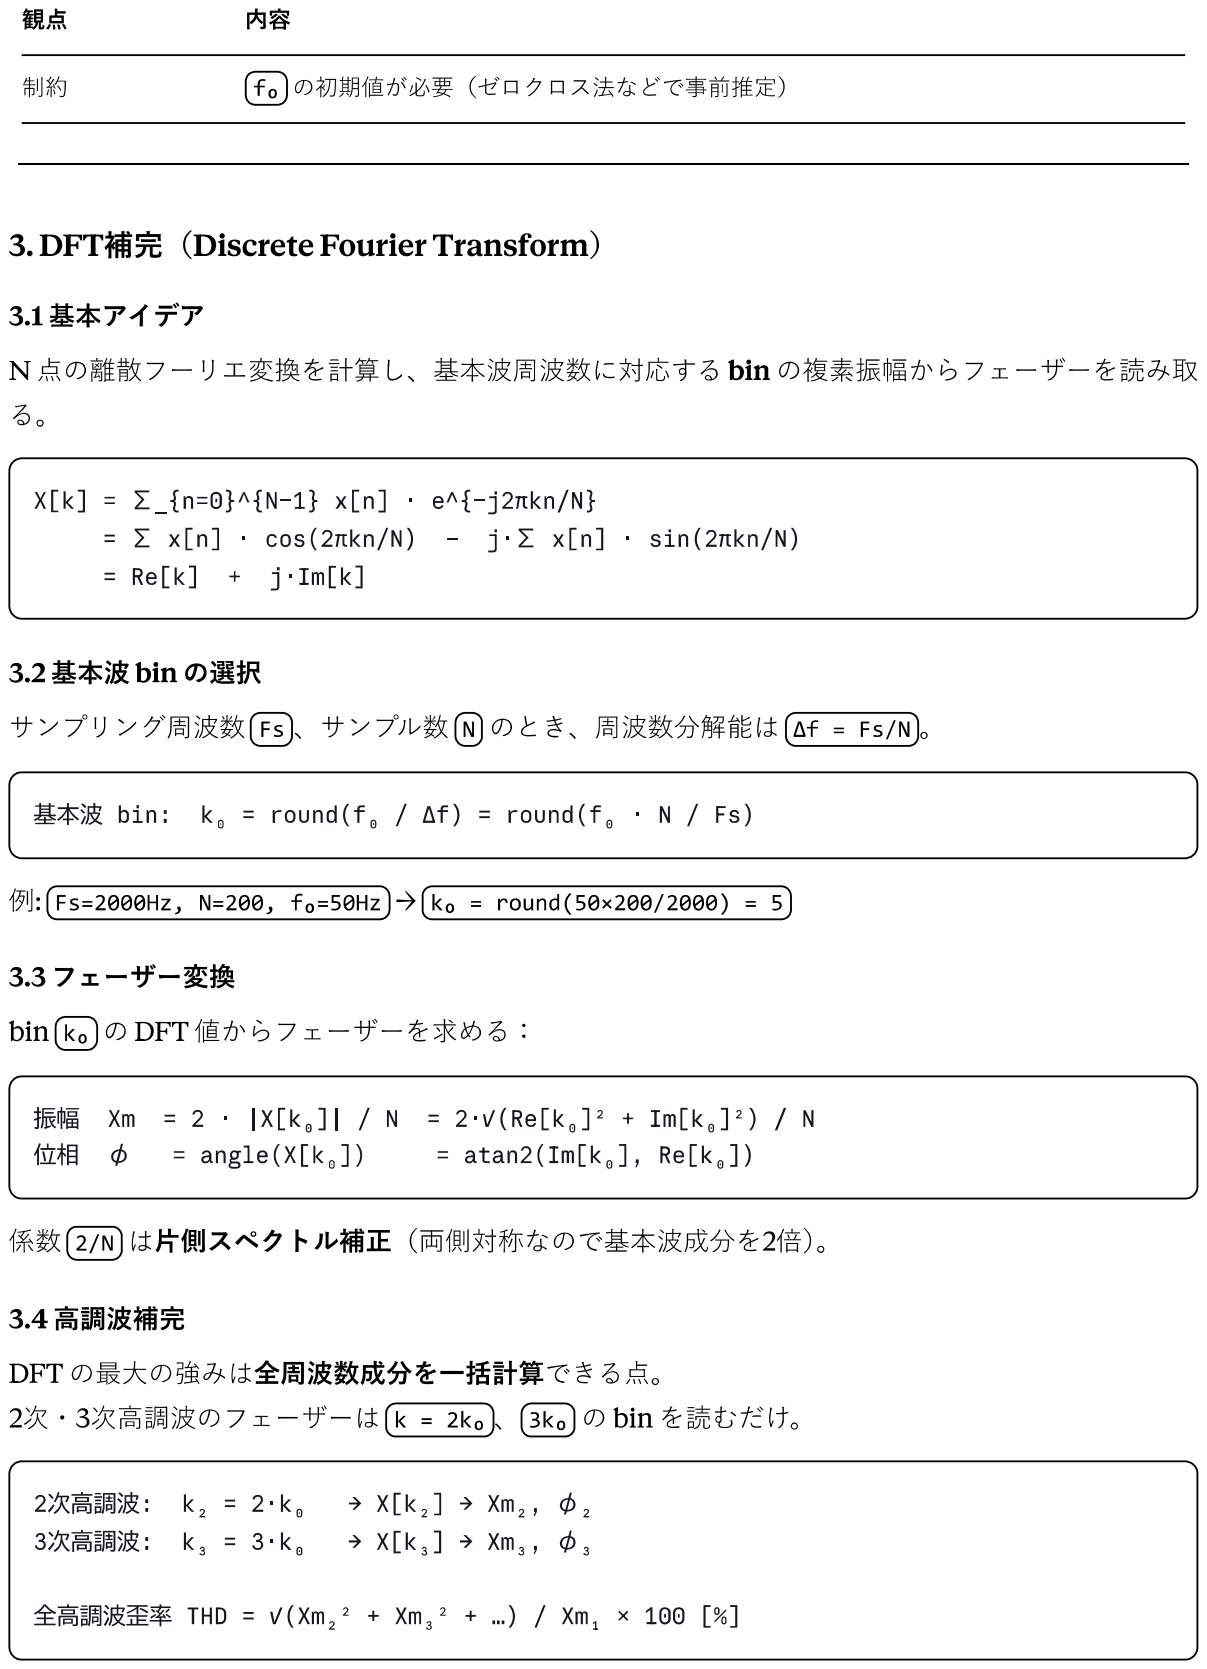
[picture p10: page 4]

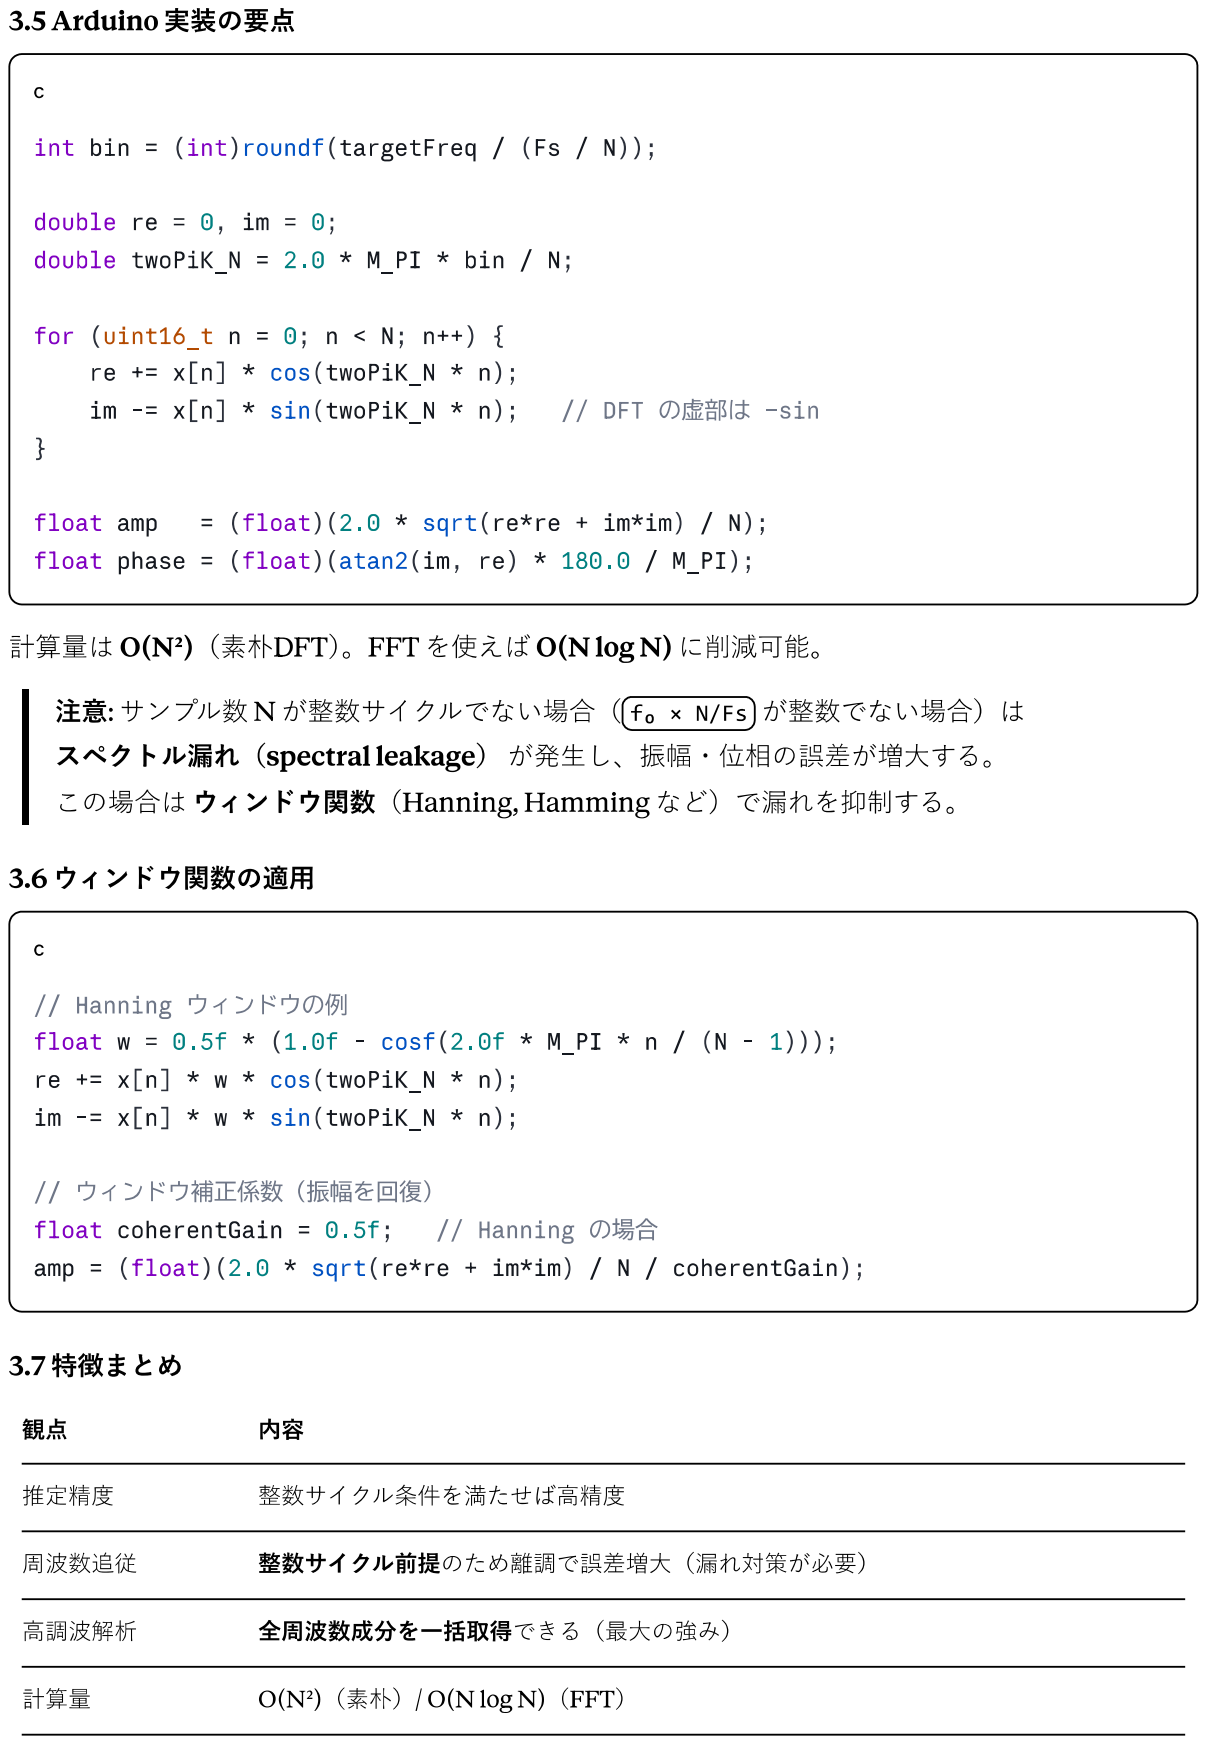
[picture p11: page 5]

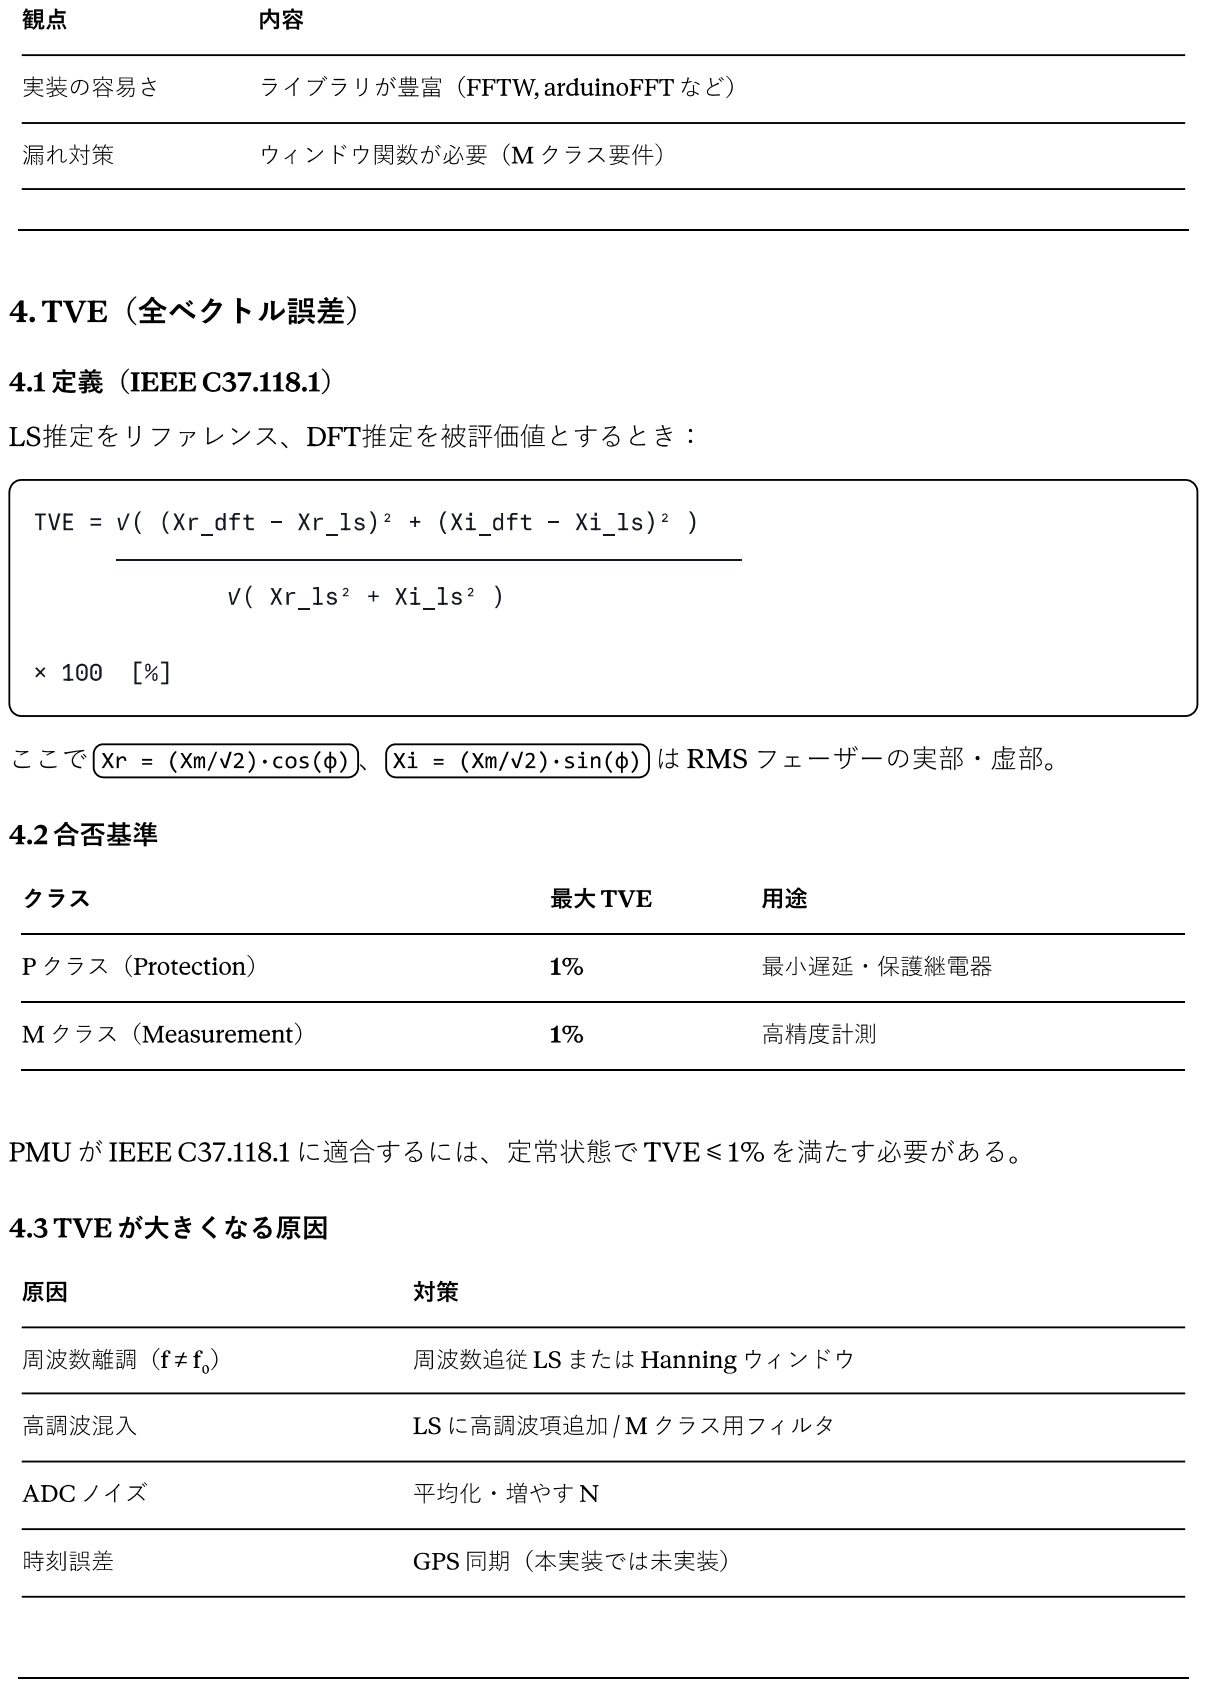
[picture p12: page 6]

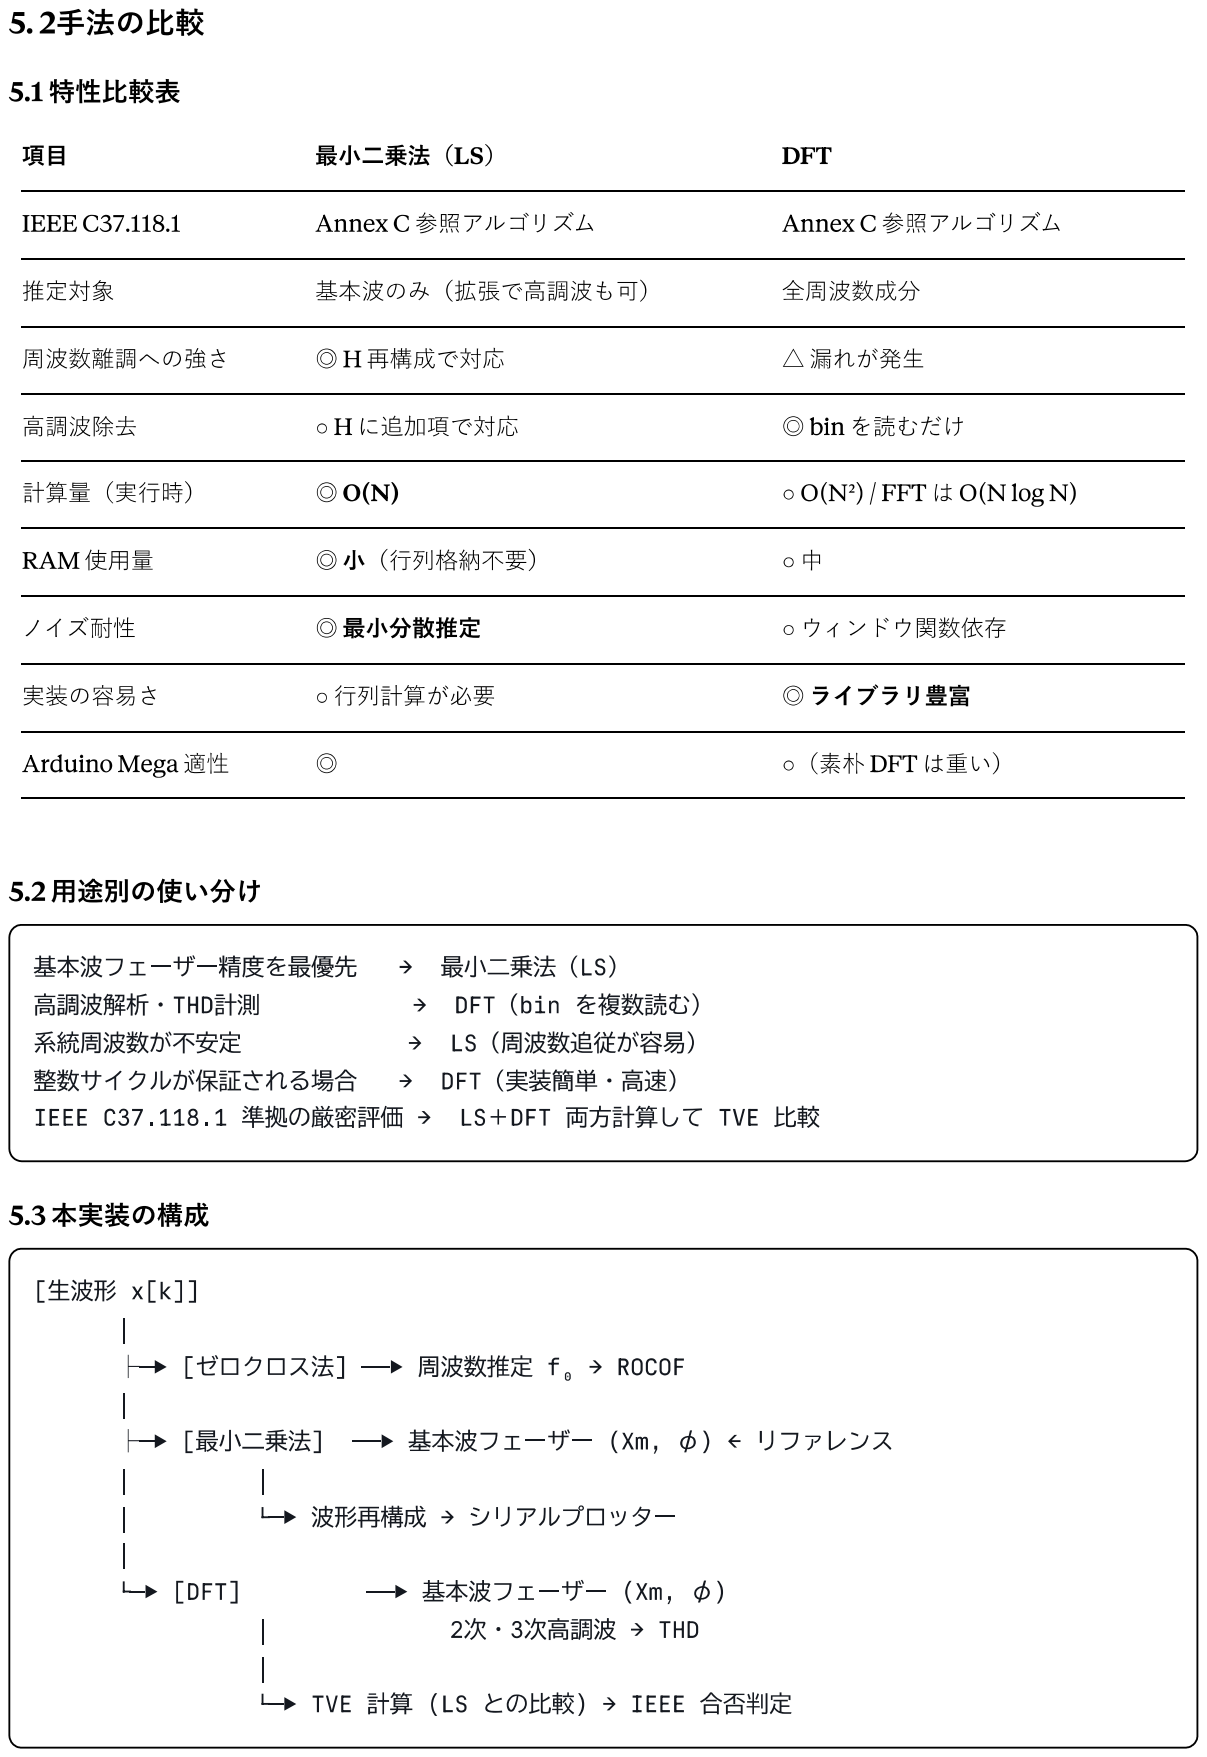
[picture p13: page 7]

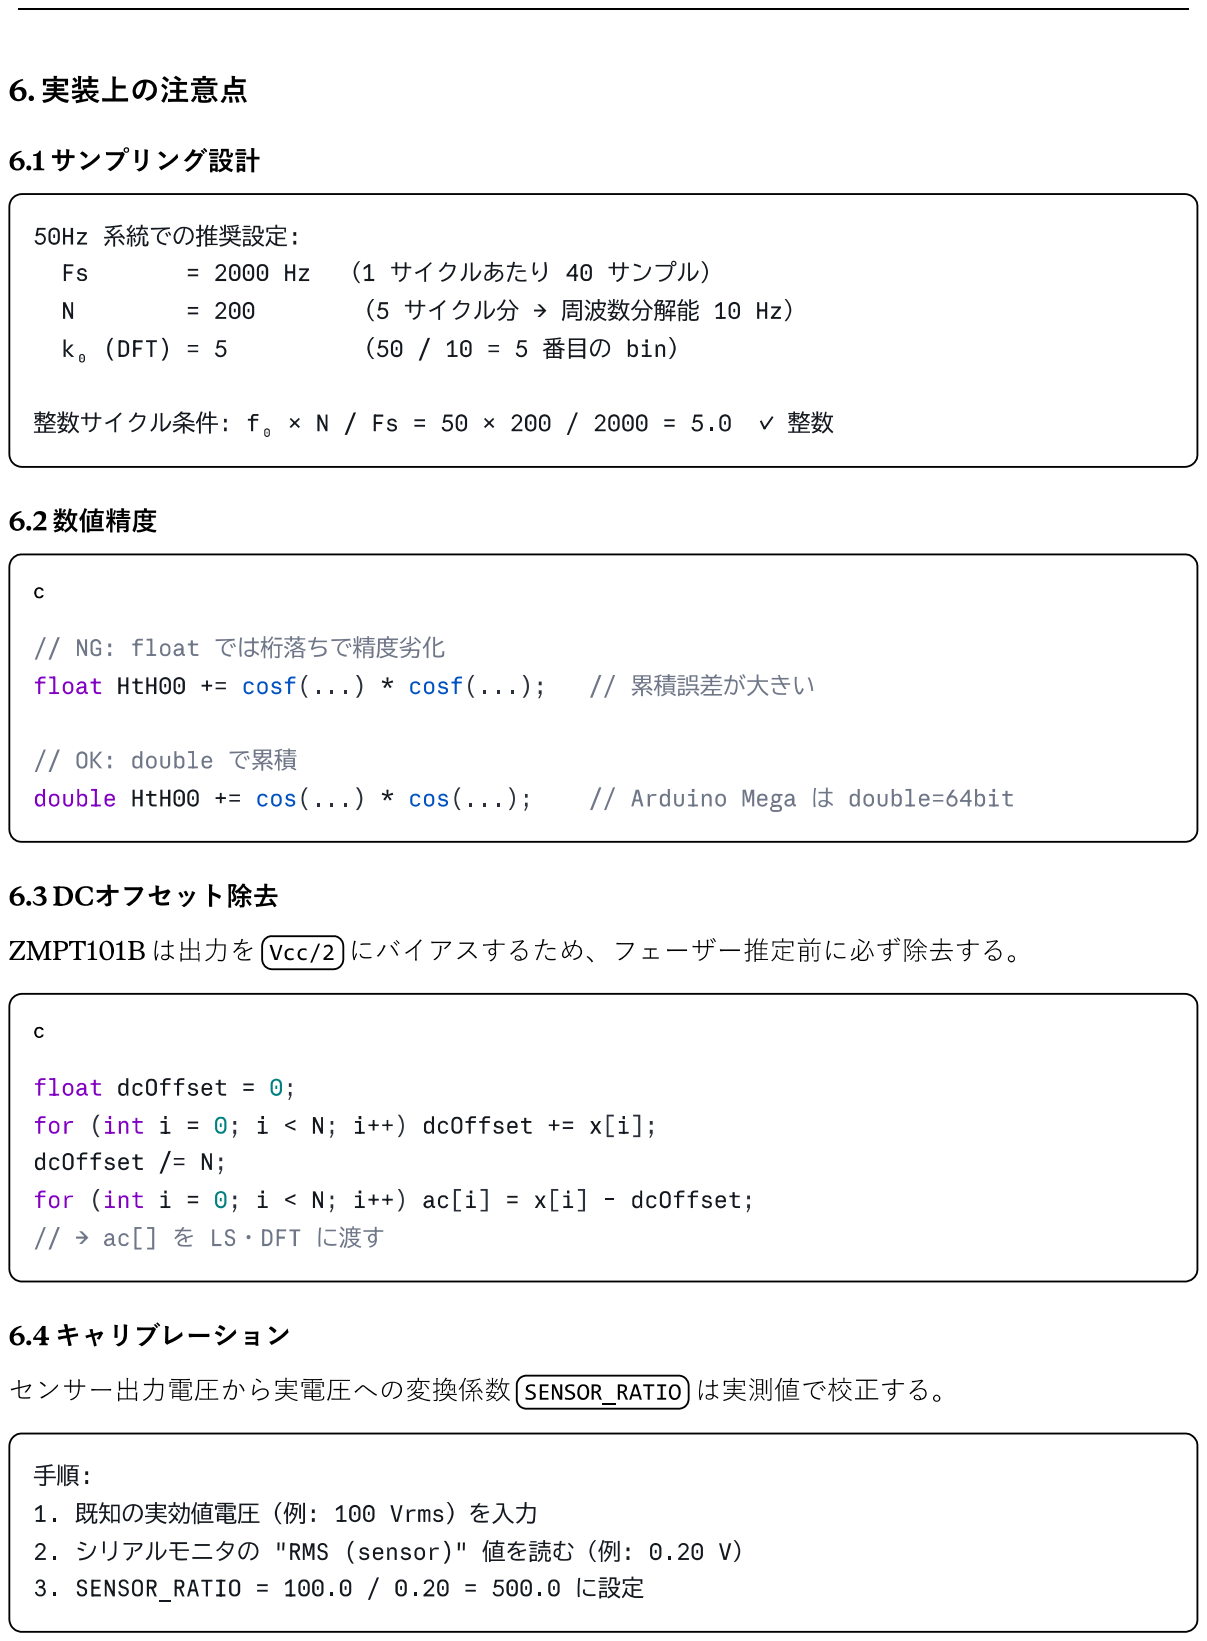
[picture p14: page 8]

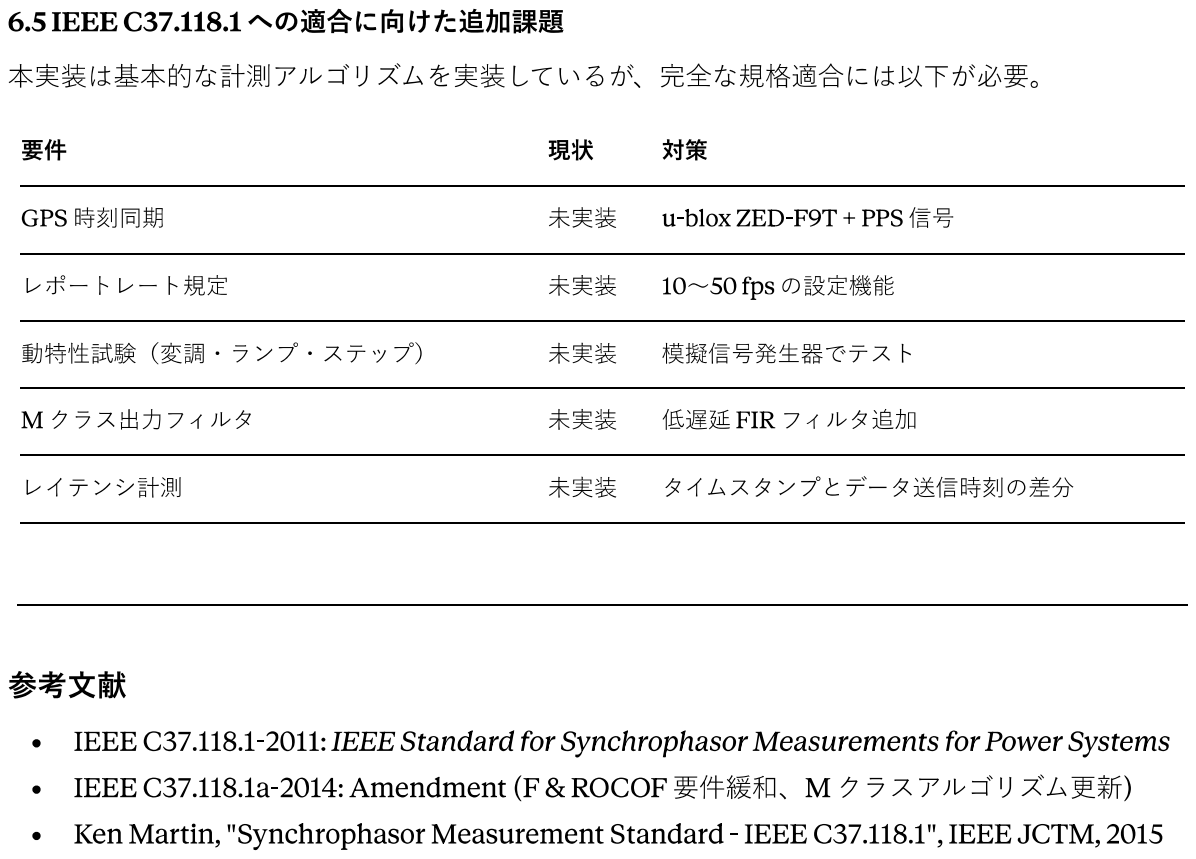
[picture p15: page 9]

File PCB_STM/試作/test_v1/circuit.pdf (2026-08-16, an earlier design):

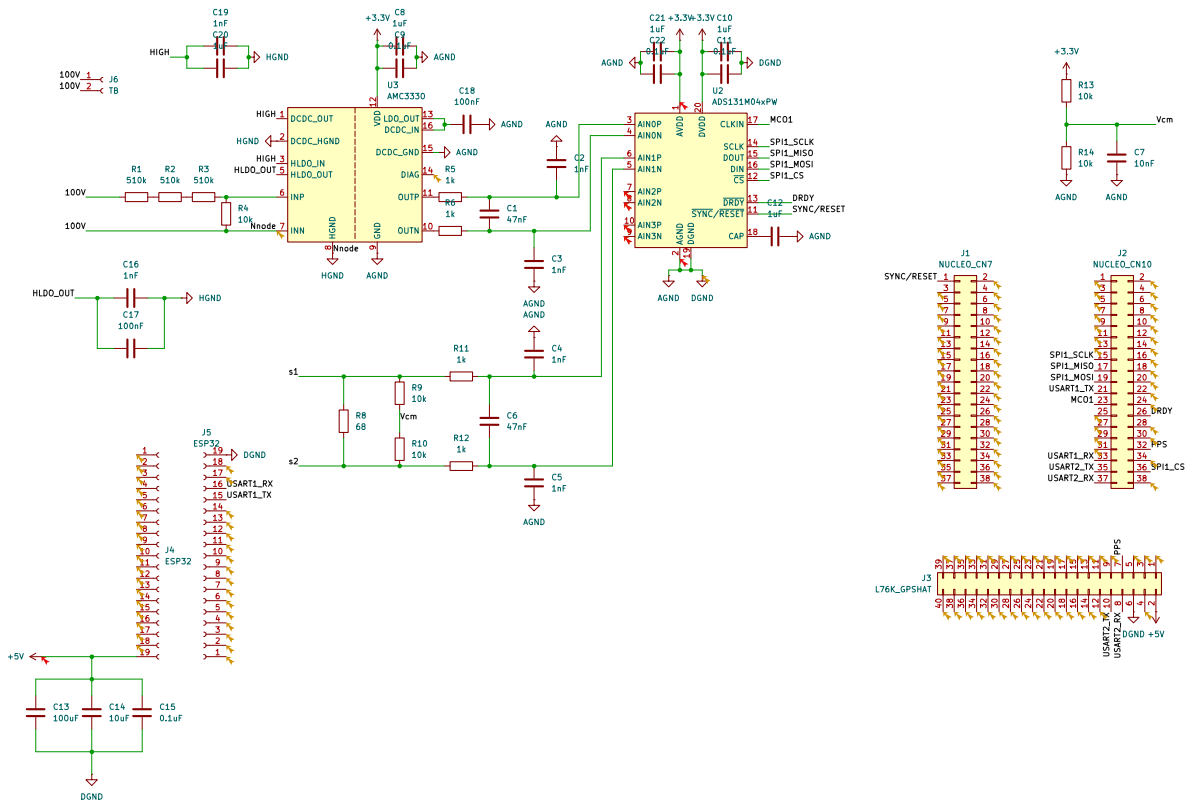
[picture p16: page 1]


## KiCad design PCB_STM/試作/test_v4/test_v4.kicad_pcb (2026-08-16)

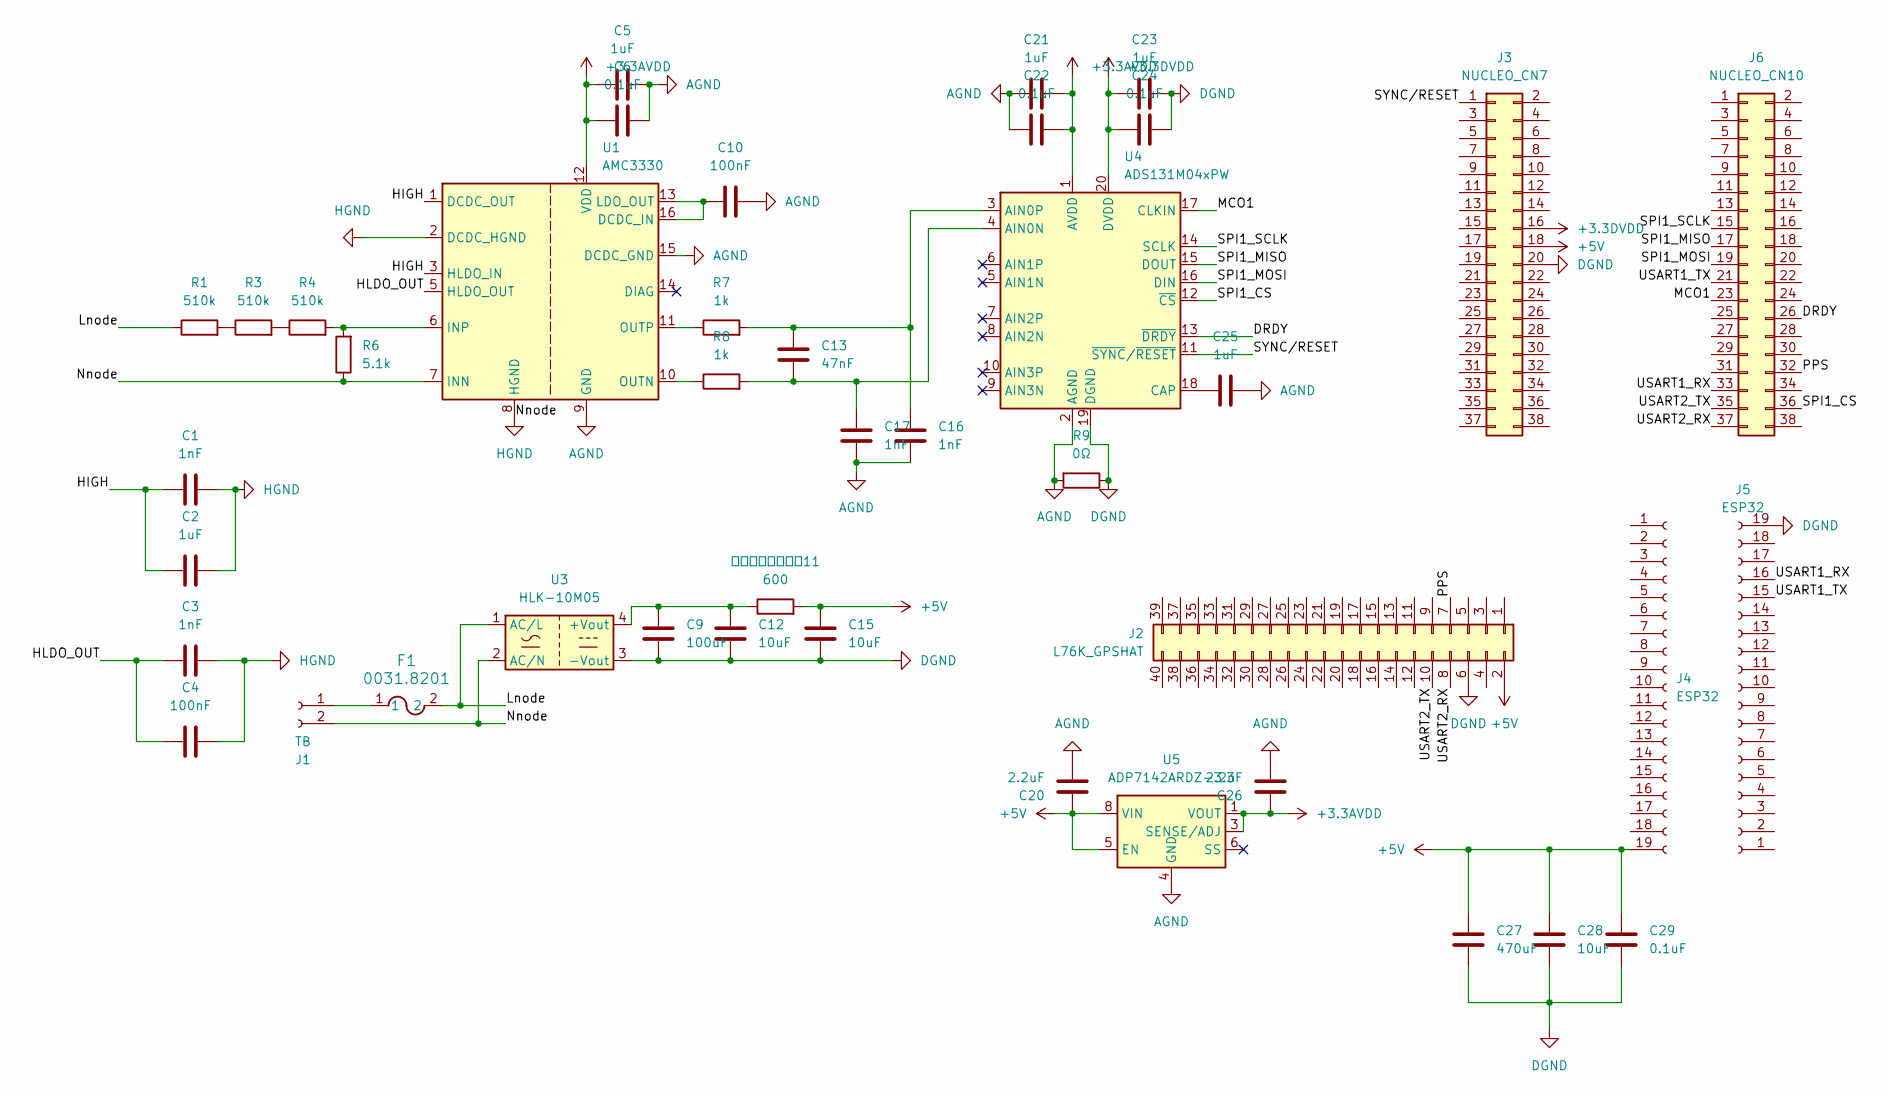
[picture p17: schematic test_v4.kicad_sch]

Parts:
C1, C3, C16, C17: 1nF; C_0805_2012Metric
C2, C5, C21, C23, C25: 1uF; C_0805_2012Metric
C4, C10: 100nF; C_0805_2012Metric
C6, C22, C24, C29: 0.1uF; C_0805_2012Metric
C9: 100uF; C_Radial_D6.3mm_H5.0mm_P2.50mm
C12, C15, C28: 10uF; C_0805_2012Metric
C13: 47nF; C_1206_3216Metric
C20, C26: 2.2uF; C_0805_2012Metric
C27: 470uF; C_Radial_D10.0mm_H12.5mm_P5.00mm
F1: 0031.8201; FUSE_0031.8201_SCH
J1: TB; Altech_AK300_1x02_P5.00mm_45-Degree
J2: L76K_GPSHAT; PinHeader_2x20_P2.54mm_Vertical
J3: NUCLEO_CN7; PinSocket_2x19_P2.54mm_Vertical
J4, J5: ESP32; PinSocket_1x19_P2.54mm_Vertical
J6: NUCLEO_CN10; PinSocket_2x19_P2.54mm_Vertical
R1, R3, R4: 510k; R_0805_2012Metric
R6: 5.1k; R_0805_2012Metric
R7, R8: 1k; R_0805_2012Metric
R9: 0Ω; R_0201_0603Metric
U1: AMC3330; SOIC-16W_7.5x10.3mm_P1.27mm
U3: HLK-10M05; Converter_ACDC_Hi-Link_HLK-10Mxx
U4: ADS131M04xPW; TSSOP-20_4.4x6.5mm_P0.65mm
U5: ADP7142ARDZ-3.3; SOIC-8-1EP_3.9x4.9mm_P1.27mm_EP2.29x3mm
フェライトビーズ11: 600; L_1206_3216Metric

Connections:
+3.3AVDD: C5.2, C6.2, C21.1, C22.1, C26.1, U1.12 (VDD), U4.1 (AVDD), U5.1 (VOUT), U5.2 (VOUT), U5.3 (SENSE/ADJ)
+3.3DVDD: C23.1, C24.1, J3.16, U4.20 (DVDD)
+5V: C15.1, C20.1, C27.1, C28.1, C29.1, J2.2, J3.18, J4.19 (Pin_19_19), U5.5 (EN), U5.7 (VIN), U5.8 (VIN), フェライトビーズ11.2
/DRDY: J6.26, U4.13 (~DRDY)
/HIGH: C1.1, C2.1, U1.1 (DCDC_OUT), U1.3 (HLDO_IN)
/HLDO_OUT: C3.1, C4.2, U1.5 (HLDO_OUT)
/Lnode: F1.2, R1.1, U3.1 (AC/L)
/MCO1: J6.23, U4.17 (CLKIN)
/PPS: J2.7, J6.32
/SPI1_CS: J6.36, U4.12 (~CS)
/SPI1_MISO: J6.17, U4.15 (DOUT)
/SPI1_MOSI: J6.19, U4.16 (DIN)
/SPI1_SCLK: J6.15, U4.14 (SCLK)
/SYNC/RESET: J3.1, U4.11 (~SYNC/~RESET)
/USART1_RX: J5.16, J6.33
/USART1_TX: J5.15, J6.21
/USART2_RX: J2.8, J6.37
/USART2_TX: J2.10, J6.35
AGND: C5.1, C6.1, C10.1, C16.2, C17.2, C20.2, C21.2, C22.2, C25.2, C26.2, R9.2, U1.9 (GND), U1.15 (DCDC_GND), U4.2 (AGND), U5.4 (GND), U5.9 (GND)
DGND: C9.2, C12.2, C15.2, C23.2, C24.2, C27.2, C28.2, C29.2, J2.6, J3.20, J5.19, R9.1, U3.3 (-Vout), U4.19 (DGND)
HGND: C1.2, C2.2, C3.2, C4.1, J1.2, R6.1, U1.2 (DCDC_HGND), U1.7 (INN), U1.8 (HGND), U3.2 (AC/N)
unnamed: F1.1, J1.1
unnamed: R1.2, R3.1
unnamed: R3.2, R4.1
unnamed: C10.2, U1.13 (LDO_OUT), U1.16 (DCDC_IN)
unnamed: R4.2, R6.2, U1.6 (INP)
unnamed: R8.1, U1.10 (OUTN)
unnamed: R7.1, U1.11 (OUTP)
unnamed: C9.1, C12.1, U3.4 (+Vout), フェライトビーズ11.1
unnamed: C13.2, C17.1, R8.2, U4.4 (AIN0N)
unnamed: C13.1, C16.1, R7.2, U4.3 (AIN0P)
unnamed: C25.1, U4.18 (CAP)

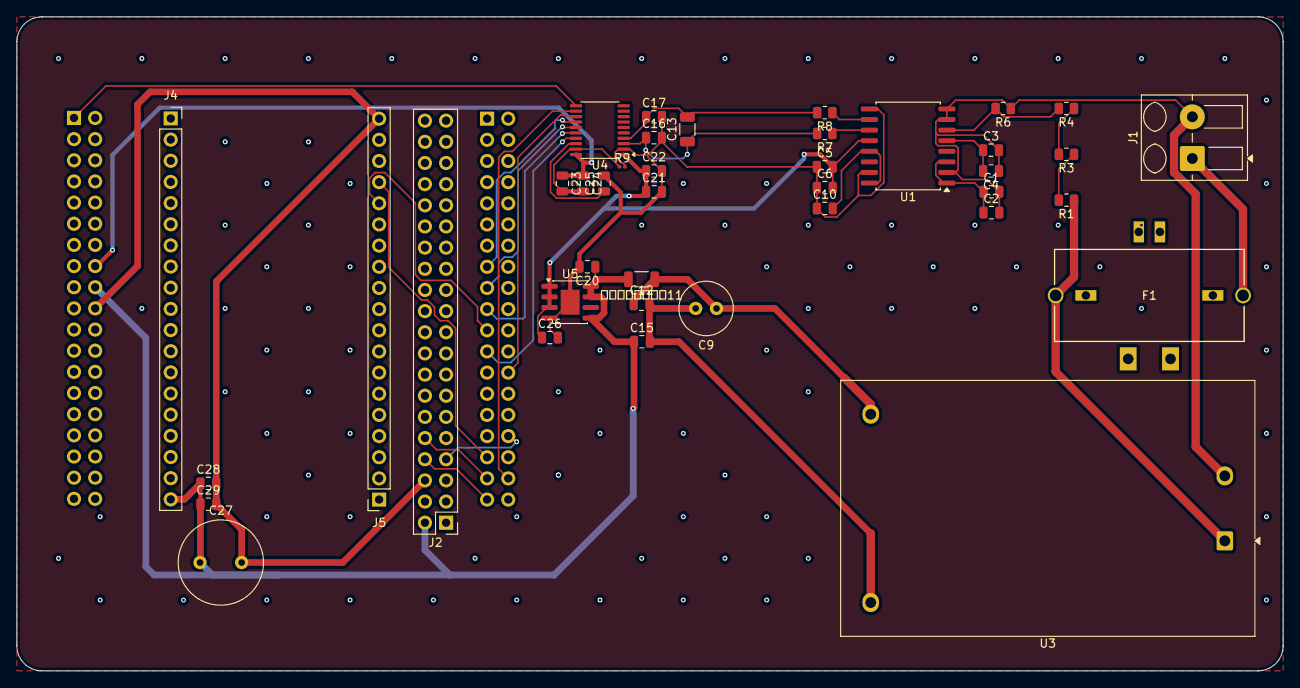
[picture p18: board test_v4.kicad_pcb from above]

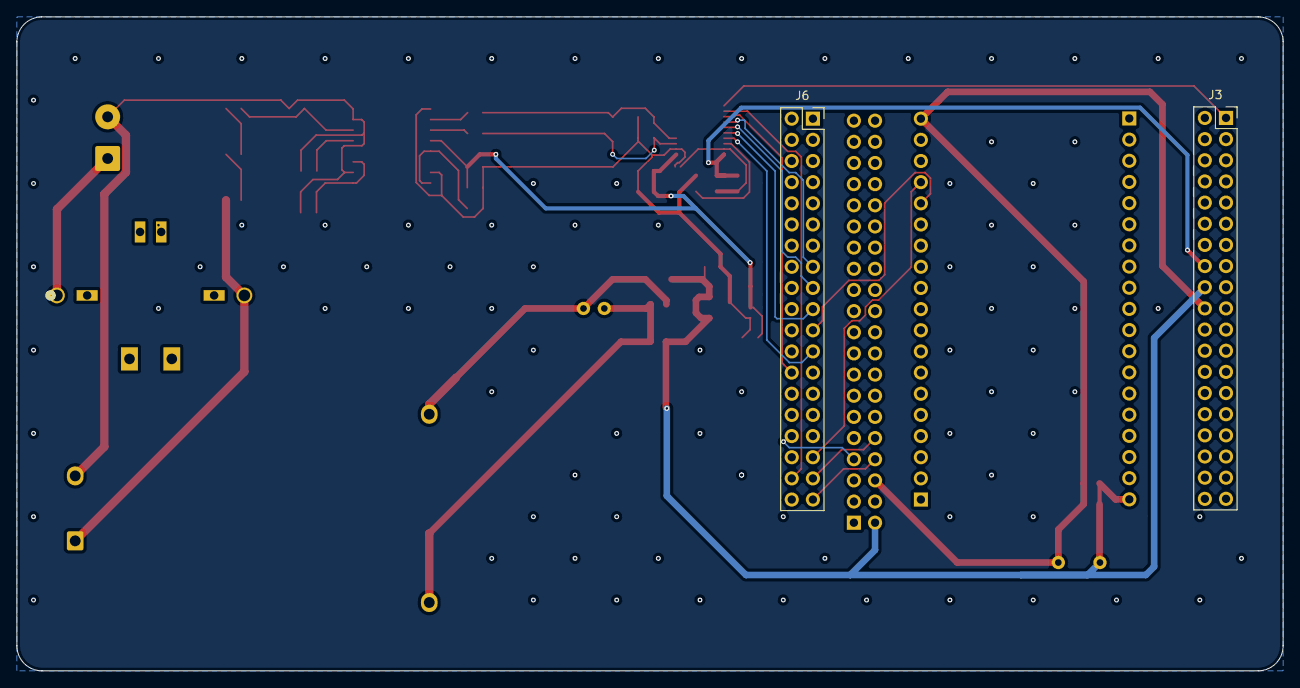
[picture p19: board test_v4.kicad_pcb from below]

Board: 2 copper layers, 152.0 x 78.5 mm, 42 parts (2 on the bottom side), 32 nets.

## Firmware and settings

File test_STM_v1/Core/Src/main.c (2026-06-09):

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
/* Includes ------------------------------------------------------------------*/
#include "main.h"
#include "pmu.h"
ADC_HandleTypeDef hadc1;

TIM_HandleTypeDef htim2;
TIM_HandleTypeDef htim5;

UART_HandleTypeDef huart2;
UART_HandleTypeDef huart1;

static uint8_t g_uart1RxByte;

void SystemClock_Config(void);
static void MX_GPIO_Init(void);
static void MX_ADC1_Init(void);
static void MX_TIM2_Init(void);
static void MX_TIM5_Init(void);
static void MX_USART2_UART_Init(void);
static void MX_USART1_UART_Init(void);
/**
  * @brief  The application entry point.
  * @retval int
  */
int main(void)
{

  /* MCU Configuration--------------------------------------------------------*/

  /* Reset of all peripherals, Initializes the Flash interface and the Systick. */
  HAL_Init();

  /* Configure the system clock */
  SystemClock_Config();

  /* Initialize all configured peripherals */
  MX_GPIO_Init();
  MX_ADC1_Init();
  MX_TIM2_Init();
  MX_TIM5_Init();
  MX_USART2_UART_Init();
  MX_USART1_UART_Init();
  /* USER CODE BEGIN 2 */
  PMU_Init();
  HAL_TIM_Base_Start_IT(&htim2);
  HAL_UART_Receive_IT(&huart1, &g_uart1RxByte, 1);
  /* USER CODE END 2 */

  /* Infinite loop */
  /* USER CODE BEGIN WHILE */
  while (1)
  {
    /* USER CODE END WHILE */

    /* USER CODE BEGIN 3 */
    PMU_Task();
  }
  /* USER CODE END 3 */
}

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
/* USER CODE BEGIN 4 */
void HAL_TIM_PeriodElapsedCallback(TIM_HandleTypeDef *htim)
{
    if (htim->Instance == TIM2)
        PMU_TIM_Callback();
}

void HAL_TIM_IC_CaptureCallback(TIM_HandleTypeDef *htim)
{
    if (htim->Instance == TIM5 && htim->Channel == HAL_TIM_ACTIVE_CHANNEL_2)
        PMU_PPS_Callback(HAL_TIM_ReadCapturedValue(htim, TIM_CHANNEL_2));
}

void HAL_ADC_ConvCpltCallback(ADC_HandleTypeDef *hadc)
{
    if (hadc->Instance == ADC1)
        PMU_ADC_Callback((uint16_t)HAL_ADC_GetValue(hadc));
}

void HAL_UART_RxCpltCallback(UART_HandleTypeDef *huart)
{
    if (huart->Instance == USART1) {
        PMU_GPS_ByteCallback(g_uart1RxByte);
        HAL_UART_Receive_IT(&huart1, &g_uart1RxByte, 1);
    }
}
/* USER CODE END 4 */
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


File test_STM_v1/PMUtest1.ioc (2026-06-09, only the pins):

Mcu.UserName=STM32F446RETx
PA0-WKUP.Signal=ADCx_IN0
PA2.Signal=USART2_TX
PA3.Signal=USART2_RX

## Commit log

2026-06-09 Add PMU synchrophasor firmware and real-time dashboard
    - STM32F446RE firmware: LS/DFT phasor estimation, frequency, ROCOF, TVE, THD
    - GPS PPS synchronization via TIM5_CH2 (PA1) for absolute phasor (IEEE C37.118.1)
    - GPS NMEA parsing via USART1 (PA10) for UTC timestamp
    - Single-file HTML dashboard with WebSerial, Chart.js, phasor diagram, CSV export
    - Device auto-detection panel (STM32 Nucleo, CH340, CP2102, FT232, etc.)
2026-06-10 Add L76K GPS HAT monitor for Arduino Mega
    - Arduino Mega + Hardware Serial1 (RX=19, TX=18) で NMEA を受信
    - TinyGPS++ でパース、衛星数・位置・時刻・速度などを表示
    - RAW_MODE で生 NMEA 確認、5秒無受信で配線警告を出力
    - 回路図・接続表・データシートまとめを同梱
2026-06-11 Update L76K GPS Monitor for Arduino Mega
    - 電源を Pin1(3.3V) から Pin2(5V) に修正（HAT は 5V 動作）
    - Mega 以外のボードでコンパイルエラーを出す #error を追加
    - UART パススルースケッチ (L76K_UART_Passthrough.ino) を追加
    - 回路図・データシートまとめのピン説明を修正
2026-08-16 Add PCB design data, specifications, and parts list
    PCB_STM/ を追加:
    - 試作 test_v1〜v4 の KiCad プロジェクト（回路図・基板・PDF）
    - 発注 test_v4 のガーバー/ドリル/製造データ一式
    - README/ に仕様書・BOM・フットプリント/ピンマップ資料、部品表xlsx
    libs/ にヒューズのカスタムシンボル/フットプリントを追加。
    phote/ に参考資料（IEEE C37.118.1 ほか）を追加。
    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
    [PMU_部品表_V2_電圧のみ.xlsx, bom.csv, designators.csv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]
2026-08-16 Add priced-parts summary sheet to BOM spreadsheet
    部品表xlsxに「単価入力済み」シートを追加。
    「部品表」シートで単価を入力済みの21件を抽出し、
    Category / Part Number / Manufacturer / Specifications / Qty /
    Unit Price (JPY) / Amount (JPY) の英語見出しで一覧化。
    Amount = Qty × Unit Price（1台分の実装コスト）、Total = 11,976円。
    発注数ベースの合計は「部品表」シート側に従来どおり残存。
    [PMU_部品表_V2_電圧のみ.xlsx]
2026-08-16 Fix AAF differential cap part number (4.7nF -> 47nF)
    No.9（C1 = AAF差動C）の型番が GRM3195C1H472JA01D になっていたが、
    Murataの容量コード 472 = 47x10^2 pF = 4.7nF であり、必要な 47nF ではない。
    このままでは fc が約1.7kHz→約17kHz となり fs/2(3.9kHz) を超えて
    アンチエイリアスが破綻するため、473（=47nF）品へ修正。
    - E15: GRM3195C1H472JA01D -> C3216C0G1H473J160AA（47nF/C0G/50V/1206）
    - F15: Murata -> TDK
    - L15: 修正内容と「単価は要再確認」を備考に追記
    - F16: C0805C102J5GACTU は KEMET 製のため メーカー表記を修正
    「単価入力済み」シートも上記に合わせて再生成。
    Co-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
    [PMU_部品表_V2_電圧のみ.xlsx]

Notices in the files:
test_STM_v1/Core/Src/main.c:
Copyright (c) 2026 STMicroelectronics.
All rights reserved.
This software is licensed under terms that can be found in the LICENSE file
